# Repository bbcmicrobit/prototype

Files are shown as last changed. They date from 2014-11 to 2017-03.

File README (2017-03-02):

Prototype Microbit/Reference Implementation
===========================================

----------------------------------------------------------------------------
NOTE:

This is the original README file for the project as released to potential
project partners in 2014.  The project is no longer covered under NDA, and
none of the information in this repository is considered confidential
information.

At some point this will revert to a historical readme and the text of this
file replaced.  Pull requests welcome, and will be merged as and when
practical!

Updated: May 2016

Michael Sparks, Senior Research Engineer, BBC R&D

---------------------------------------------------------------------------

Copyright (C) 2014 BBC.

This reference implementation is confidential information, and MUST be kept
confidential, as per the NDA you have signed with the BBC.

The reference implementation is provided to assist you in your pitch/proposal/
development process. It is NOT intended as a basis for ongoing development.

You should use this as a reference for what you want to pitch, rather than as
a basis for development. While improvements to the reference implementation
are welcome, the proposition will be better served by those pitches that go
beyond the reference implementation. Please see the enclosed LICENSE for
further details.

Licenses of technologies used within the reference implementation can be
found in the LICENSES.pdf file

The reference implementation is a WORK IN PROGRESS. It covers most of the
functional specification, and was used to create the functional spec. 
However, in places the the reference implementation deviates from the
functional spec.  In such cases, the functional spec is canonical, and over
time the reference implementation will improve to match the spec.

    NO WARRANTY

    THE HARDWARE, HARDWARE DESIGNS AND SOFTWARE ("MICROBIT SYSTEM")   
    IS DISTRIBUTED IN THE HOPE THAT IT WILL BE USEFUL, BUT WITHOUT 
    ANY WARRANTY.  IT IS PROVIDED "AS IS" WITHOUT WARRANTY OF ANY
    KIND, EITHER EXPRESSED OR IMPLIED, INCLUDING, BUT NOT LIMITED      
    TO, THE IMPLIED WARRANTIES OF MERCHANTABILITY AND FITNESS FOR A
    PARTICULAR PURPOSE.  THE ENTIRE RISK AS TO THE QUALITY AND
    PERFORMANCE OF THE MICROBIT SYSTEM IS WITH YOU.  SHOULD THE
    MICROBIT SYSTEM PROVE DEFECTIVE, YOU ASSUME THE COST OF ALL
    NECESSARY SERVICING, REPAIR OR CORRECTION.

    IN NO EVENT UNLESS REQUIRED BY APPLICABLE LAW THE AUTHOR WILL BE
    LIABLE TO YOU FOR DAMAGES, INCLUDING ANY GENERAL, SPECIAL,
    INCIDENTAL OR CONSEQUENTIAL DAMAGES ARISING OUT OF THE USE OR
    INABILITY TO USE THE MICROBIT SYSTEM (INCLUDING BUT NOT LIMITED      
    TO LOSS OF DATA OR DATA BEING RENDERED INACCURATE OR LOSSES
    SUSTAINED BY YOU OR THIRD PARTIES OR A FAILURE OF THE MICROBIT 
    SYSTEM TO OPERATE WITH ANY OTHER SYSTEMS), EVEN IF THE AUTHOR
    HAS BEEN ADVISED OF THE POSSIBILITY OF SUCH DAMAGES.

Michael Sparks, Senior Research Engineer, BBC R&D, December 2014

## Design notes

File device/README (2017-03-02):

The device design & production data files will go in here, so that
all the tech materials relating to the production microbit are in one place.

The current device is described in ProductionData, and uses Design Spark PCB
as the editor tool.

Note: The gerber/etc files in here are as provided to the PCB-A
print/assembly house *that we used* and while maybe could be used as-is you
are required to check that they are suitable for your use before you do.

Files in this directory and all the directories below this one are covered by this license:

#
# Copyright 2016 British Broadcasting Corporation and Contributors(1)
#
# (1) Contributors are listed in the AUTHORS file (please extend AUTHORS,
#     not this header)
#
# Licensed under the Apache License, Version 2.0 (the "License"); you may
# not use this file except in compliance this license (or the alternative
# license below).
# You may obtain a copy of the License at
#
#     http://www.apache.org/licenses/LICENSE-2.0
#
# This file is also alternatively licensed under the terms of the Creative
# Commons Attribution License (cc-by) version 2.  You may obtain a copy of
# the license at:
#
#     https://creativecommons.org/licenses/by/2.0/uk/
#
# Unless required by applicable law or agreed to in writing, software
# distributed under the License is distributed on an "AS IS" BASIS,
# WITHOUT WARRANTIES OR CONDITIONS OF ANY KIND, either express or implied.
# See the License for the specific language governing permissions and
# limitations under the License.
#

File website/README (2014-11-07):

Massive reorganisation - to allow using the repo to store
ALL the material relating to the project.

This directory is the various necessary parts of the website

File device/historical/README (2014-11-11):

These are the iterations of the microbug device from first steps through to
now.

This only includes the iterations created using DesignSpark PCB

I've left the tmp files in for now so there's a complete copy of everything

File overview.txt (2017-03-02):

What is Microbit - prototype technical overview
===============================================

NOTE; This, and all materials related to the reference implementation are
CONFIDENTIAL INFORMATION, and must not be made public, as per NDA with BBC.

The project entails a simple programmable wearable device. The current
reference implementation is based on an Atmel ATMega 32u4 which makes it
similar to an leonardo arduino - indeed we using the command line suite of
tools configured as a leonardo. (The device doesn't have an Arduino
bootloader however)

The user uses a website (which is implemented using Django) to create
programs for the device using Blockly. Blockly generates javascript to drive
a simulator for verification of the behaviour. Blockly also generates python
- that is stored on a server.

The python is compiled to C++ - using a barebone python to C++ compiler I've
written using David Beazeley's ply.

The C++ is then injected into the arduino command line tools, compiled and a
.hex file image extracted from the build

That .hex file can be downloaded by users
They then have a local application - a loader - (PyQT & shell out to a
command line tool) for loading the code onto the device.
The device then runs the code.

There's also an IOT library (http://github.com/sparkslabs/iotoy) which is
available to allow the device to be controlled and used as a sensor by a
host machine. The primary client side library for that is written in python.

Buried in that toolchain is a cut down python to C++ compiler intended for
targetting microcontrollers. (I did look at all the others I'm aware of, but
they weren't really suitable). 

There's also the aspect that actually while blockly is used as *a* editor,
the system's primary target is python.

While technologies are used in this reference implementation, please
rememeber it is illustrative, not prescriptive. The functional specification
is the canonical description of prescriptive functionality.

There are many some parts of this are not as fleshed out as they could be -
in particular the python/C++ code is nowhere near as far along as we'd like.
It works, but within more constrained limits than it should. 

Michael Sparks, Senior Research Engineer, BBC R&D, December 2014

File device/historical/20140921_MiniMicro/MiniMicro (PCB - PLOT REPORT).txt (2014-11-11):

PLOT REPORT
-----------

Report File    : C:\Users\michaels\Documents\MiniMicro\MiniMicro (PCB - PLOT REPORT).txt
Report Written : Sunday, September 21, 2014
Design Path    : C:\Users\michaels\Documents\MiniMicro\MiniMicro.pcb
Design Title   : 
Created        : 19/09/2014 13:37:57
Last Saved     : 21/09/2014 04:09:29
Editing Time   : 1987 min
Units          : thou (precision 1)

Device Settings
===============

Gerber Settings
===============

    Leading zero suppression.
    G01 assumed throughout.
    Line termination <*> <CR> <LF>.
    2.3 format absolute inches.

    Format commands defined in Gerber file.
    Aperture table defined in Gerber file.
    Hardware arcs allowed.

Drill Settings
==============

    Excellon Format 1    Format 2.3 absolute in mm.
    No zero suppression.

PDF Settings
============

Combine Plots Yes

Use Bookmarks Yes

Component Details Yes

Symbol Details Yes

Link Net Names Yes

View PDF Yes

All Colours Black Yes

Plots Output
============

    Plot Job: "C:\Users\michaels\Documents\MiniMicro\MiniMicro.mop"

PDF Output
==========

    Layer
    --------------
    Bottom Copper
    Top Copper
    Top Silkscreen

Gerber Output
=============

C:\Users\michaels\Documents\MiniMicro\MiniMicro - Top Copper (Resist).gbr

    Layers:
    ------------
    Top Copper

    D-Code  Shape  (thou)
    --------------------------------------------
    D14     Rectangle 24.00 X 56.00  Rotation 90
    D15     Rectangle 24.00 X 56.00
    D25     Rectangle 27.52 X 47.40
    D26     Rectangle 46.00 X 67.00
    D27     Square 69.00
    D28     Round 69.00
    D29     Rectangle 28.00 X 65.00
    D72     Rectangle 65.00 X 73.00
    D73     Rectangle 63.00 X 67.00  Rotation 90
    D83     Rectangle 27.52 X 47.40  Rotation 90
    D84     Rectangle 36.00 X 65.00  Rotation 90
    D85     Rectangle 65.00 X 69.00
    D86     Rectangle 65.00 X 69.00  Rotation 90
    D87     Rectangle 40.00 X 65.00
    D88     Square 57.00
    D89     Round 57.00
    D90     Round 72.99
    D91     Round 88.74
    D92     Round 128.11

Gerber Output
=============

C:\Users\michaels\Documents\MiniMicro\MiniMicro - Top Copper (Paste).gbr

    Layers:
    ------------
    Top Copper

    D-Code  Shape  (thou)
    --------------------------------------------
    D17     Rectangle 10.00 X 42.00  Rotation 90
    D18     Rectangle 10.00 X 42.00
    D77     Rectangle 13.52 X 33.40
    D78     Rectangle 32.00 X 53.00
    D79     Rectangle 14.00 X 51.00
    D80     Rectangle 51.00 X 59.00
    D81     Rectangle 49.00 X 53.00  Rotation 90
    D93     Rectangle 13.52 X 33.40  Rotation 90
    D94     Rectangle 22.00 X 51.00  Rotation 90
    D95     Rectangle 51.00 X 55.00
    D96     Rectangle 51.00 X 55.00  Rotation 90
    D97     Rectangle 26.00 X 51.00

Gerber Output
=============

C:\Users\michaels\Documents\MiniMicro\MiniMicro - Bottom Copper (Resist).gbr

    Layers:
    ---------------
    Bottom Copper

    D-Code  Shape  (thou)
    ---------------------------------
    D20     Round 70.00
    D27     Square 69.00
    D28     Round 69.00
    D88     Square 57.00
    D89     Round 57.00
    D90     Round 72.99
    D91     Round 88.74
    D92     Round 128.11
    D98     Rectangle 246.22 X 246.22

Gerber Output
=============

C:\Users\michaels\Documents\MiniMicro\MiniMicro - Bottom Copper (Paste).gbr

    Layers:
    ---------------
    Bottom Copper

    D-Code  Shape  (thou)
    ---------------------------------
    D99     Round 56.00
    D100    Rectangle 232.22 X 232.22

NC Drill Output
===============

C:\Users\michaels\Documents\MiniMicro\MiniMicro - Drill Data - Through Hole.drl

    Output:
    --------------------------
    Plated Round Drill Holes
    Plated Slots
    Plated Board Outlines

    Tool   Size       Count    ID
    -----------------------------
    T001   00.024 in  37     B
    T002   00.027 in  2      F
    T003   00.031 in  3      G
    T004   00.032 in  13     C
    T005   00.039 in  12     E
    T006   00.057 in  1      H
    T007   00.059 in  1      I
    T008   00.071 in  2      J
    -----------------------------
    Total             71
    -----------------------------
    Tool   Size       Count    ID
    -----------------------------
    T001   00.025 in  1
    -----------------------------
    Total             1
    -----------------------------

Gerber Output
=============

C:\Users\michaels\Documents\MiniMicro\MiniMicro - Drill Ident Drawing - Through Hole.gbr

    Layers:
    ----------------
    [Through Hole]

Drill Ident Drawing
===================

    Drill  Plated  Size  Shape  ID
    ------------------------------
    24     Y       100   Round  B
    32     Y       100   Round  C
    39     Y       100   Round  E
    27     Y       100   Round  F
    31     Y       100   Round  G
    57     Y       100   Round  H
    59     Y       100   Round  I
    71     Y       100   Round  J

    D-Code  Shape  (thou)
    ---------------------
    D19     Round 100.00
    D70     Round 5.00

End Of Report.

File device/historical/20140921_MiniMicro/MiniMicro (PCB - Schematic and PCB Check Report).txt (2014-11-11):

Schematic and PCB Check Report
------------------------------

Report File    : C:\Users\michaels\Documents\MiniMicro\MiniMicro (PCB - Schematic and PCB Check Report).txt
Report Written : Sunday, September 21, 2014
Design Path    : C:\Users\michaels\Documents\MiniMicro\MiniMicro.pcb
Design Title   : 
Created        : 19/09/2014 13:37:57
Last Saved     : 21/09/2014 03:45:59
Editing Time   : 1963 min
Units          : thou (precision 1)

Checking integrity of Schematic "C:\Users\michaels\Documents\MiniMicro\MiniMicro_Sheet1.sch" with PCB "C:\Users\michaels\Documents\MiniMicro\MiniMicro.pcb"
===========================================================================================================================================================

The designs are the same.

End Of Report.

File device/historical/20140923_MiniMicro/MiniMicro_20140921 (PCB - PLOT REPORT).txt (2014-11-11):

PLOT REPORT
-----------

Report File    : C:\Users\michaels\Documents\MiniMicro_20140921\MiniMicro_20140921 (PCB - PLOT REPORT).txt
Report Written : Monday, September 22, 2014
Project Path   : C:\Users\michaels\Documents\MiniMicro_20140921\MiniMicro_20140921.prj
Design Path    : C:\Users\michaels\Documents\MiniMicro_20140921\MiniMicro_20140921.pcb
Design Title   : 
Created        : 21/09/2014 12:47:43
Last Saved     : 22/09/2014 12:27:17
Editing Time   : 626 min
Units          : thou (precision 0)

Device Settings
===============

Gerber Settings
===============

    Leading zero suppression.
    G01 assumed throughout.
    Line termination <*> <CR> <LF>.
    2.3 format absolute inches.

    Format commands defined in Gerber file.
    Aperture table defined in Gerber file.
    Hardware arcs allowed.

Drill Settings
==============

    Excellon Format 1    Format 2.3 absolute in mm.
    No zero suppression.

Plots Output
============

    Plot Job: "C:\Users\michaels\Documents\MiniMicro_20140921\MiniMicro_20140921.mop"

Gerber Output
=============

C:\Users\michaels\Documents\MiniMicro_20140921\MiniMicro_20140921 - Top Silkscreen.gbr

    Layers:
    ----------------
    Top Silkscreen
    Board Outlines

    D-Code  Shape  (thou)
    ---------------------
    D70     Round 5.00
    D116    Round 1.00
    D117    Round 6.00
    D118    Round 3.00

Gerber Output
=============

C:\Users\michaels\Documents\MiniMicro_20140921\MiniMicro_20140921 - Top Copper.gbr

    Layers:
    ------------
    Top Copper

    D-Code  Shape  (thou)
    ---------------------------------------------
    D13     Round 15.00
    D71     Round 48.00
    D119    Rectangle 14.00 X 46.00  Rotation 45
    D120    Rectangle 14.00 X 46.00  Rotation 135
    D121    Rectangle 17.52 X 37.40
    D122    Rectangle 36.00 X 57.00  Rotation 45
    D123    Square 59.00
    D124    Round 59.00
    D125    Rectangle 18.00 X 55.00
    D126    Rectangle 55.00 X 63.00
    D127    Rectangle 53.00 X 57.00  Rotation 90
    D128    Rectangle 36.00 X 57.00
    D129    Rectangle 26.00 X 55.00  Rotation 135
    D130    Rectangle 55.00 X 59.00
    D131    Rectangle 30.00 X 55.00
    D132    Round 62.99
    D133    Round 78.74
    D134    Square 47.00
    D135    Round 47.00
    D136    Round 236.22
    D137    Round 10.00
    D138    Round 56.00
    D139    Round 25.00

Gerber Output
=============

C:\Users\michaels\Documents\MiniMicro_20140921\MiniMicro_20140921 - Top Copper (Resist).gbr

    Layers:
    ------------
    Top Copper

    D-Code  Shape  (thou)
    ---------------------------------------------
    D21     Rectangle 24.00 X 56.00  Rotation 135
    D22     Rectangle 24.00 X 56.00  Rotation 45
    D25     Rectangle 27.52 X 47.40
    D26     Rectangle 46.00 X 67.00
    D27     Square 69.00
    D28     Round 69.00
    D29     Rectangle 28.00 X 65.00
    D73     Rectangle 63.00 X 67.00  Rotation 90
    D87     Rectangle 40.00 X 65.00
    D88     Square 57.00
    D89     Round 57.00
    D90     Round 72.99
    D91     Round 88.74
    D101    Rectangle 46.00 X 67.00  Rotation 45
    D102    Rectangle 65.00 X 73.00
    D104    Rectangle 65.00 X 69.00
    D107    Rectangle 36.00 X 65.00  Rotation 135
    D109    Round 246.22

Gerber Output
=============

C:\Users\michaels\Documents\MiniMicro_20140921\MiniMicro_20140921 - Top Copper (Paste).gbr

    Layers:
    ------------
    Top Copper

    D-Code  Shape  (thou)
    ---------------------------------------------
    D75     Rectangle 10.00 X 42.00  Rotation 135
    D76     Rectangle 10.00 X 42.00  Rotation 45
    D77     Rectangle 13.52 X 33.40
    D78     Rectangle 32.00 X 53.00
    D79     Rectangle 14.00 X 51.00
    D80     Rectangle 51.00 X 59.00
    D81     Rectangle 49.00 X 53.00  Rotation 90
    D95     Rectangle 51.00 X 55.00
    D97     Rectangle 26.00 X 51.00
    D105    Rectangle 32.00 X 53.00  Rotation 45
    D108    Rectangle 22.00 X 51.00  Rotation 135

Gerber Output
=============

C:\Users\michaels\Documents\MiniMicro_20140921\MiniMicro_20140921 - Bottom Copper.gbr

    Layers:
    ---------------
    Bottom Copper

    D-Code  Shape  (thou)
    ----------------------------------------------
    D13     Round 15.00
    D71     Round 48.00
    D123    Square 59.00
    D124    Round 59.00
    D132    Round 62.99
    D133    Round 78.74
    D134    Square 47.00
    D135    Round 47.00
    D136    Round 236.22
    D138    Round 56.00
    D140    Rectangle 400.00 X 400.00  Rotation 90
    D141    Rectangle 200.00 X 200.00  Rotation 90
    D142    Rectangle 196.85 X 196.85  Rotation 90
    D143    Round 50.00

Gerber Output
=============

C:\Users\michaels\Documents\MiniMicro_20140921\MiniMicro_20140921 - Bottom Copper (Resist).gbr

    Layers:
    ---------------
    Bottom Copper

    D-Code  Shape  (thou)
    ----------------------------------------------
    D27     Square 69.00
    D28     Round 69.00
    D88     Square 57.00
    D89     Round 57.00
    D90     Round 72.99
    D91     Round 88.74
    D109    Round 246.22
    D110    Rectangle 410.00 X 410.00  Rotation 90
    D111    Rectangle 210.00 X 210.00  Rotation 90
    D112    Rectangle 206.85 X 206.85  Rotation 90

Gerber Output
=============

C:\Users\michaels\Documents\MiniMicro_20140921\MiniMicro_20140921 - Bottom Copper (Paste).gbr

    Layers:
    ---------------
    Bottom Copper

    D-Code  Shape  (thou)
    ----------------------------------------------
    D113    Rectangle 396.00 X 396.00  Rotation 90
    D114    Rectangle 196.00 X 196.00  Rotation 90
    D115    Rectangle 192.85 X 192.85  Rotation 90

NC Drill Output
===============

C:\Users\michaels\Documents\MiniMicro_20140921\MiniMicro_20140921 - Drill Data - Through Hole.drl

    Output:
    --------------------------
    Plated Round Drill Holes
    Plated Slots
    Plated Board Outlines

    Tool   Size       Count    ID
    -----------------------------
    T001   00.024 in  50     B
    T002   00.027 in  2      F
    T003   00.031 in  3      G
    T004   00.032 in  9      C
    T005   00.039 in  12     E
    T006   00.057 in  1      H
    T007   00.059 in  1      I
    T008   00.157 in  8      K
    -----------------------------
    Total             86
    -----------------------------
    Tool   Size       Count    ID
    -----------------------------
    T001   00.025 in  1
    -----------------------------
    Total             1
    -----------------------------

Gerber Output
=============

C:\Users\michaels\Documents\MiniMicro_20140921\MiniMicro_20140921 - Drill Ident Drawing - Through Hole.gbr

    Layers:
    ----------------
    [Through Hole]

Drill Ident Drawing
===================

    Drill  Plated  Size  Shape  ID
    ------------------------------
    24     Y       100   Round  B
    32     Y       100   Round  C
    39     Y       100   Round  E
    27     Y       100   Round  F
    31     Y       100   Round  G
    57     Y       100   Round  H
    59     Y       100   Round  I
    157    Y       100   Round  K

    D-Code  Shape  (thou)
    ---------------------
    D19     Round 100.00
    D70     Round 5.00

End Of Report.

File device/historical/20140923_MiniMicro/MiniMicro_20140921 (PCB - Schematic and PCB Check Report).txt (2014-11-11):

Schematic and PCB Check Report
------------------------------

Report File    : C:\Users\michaels\Documents\MiniMicro_20140921\MiniMicro_20140921 (PCB - Schematic and PCB Check Report).txt
Report Written : Tuesday, September 23, 2014
Project Path   : C:\Users\michaels\Documents\MiniMicro_20140921\MiniMicro_20140921.prj
Design Path    : C:\Users\michaels\Documents\MiniMicro_20140921\MiniMicro_20140921.pcb
Design Title   : 
Created        : 21/09/2014 12:47:43
Last Saved     : 23/09/2014 15:33:50
Editing Time   : 719 min
Units          : thou (precision 0)

Checking integrity of Schematic and Pcb designs in project "MiniMicro_20140921"
===============================================================================

The designs are the same.

End Of Report.

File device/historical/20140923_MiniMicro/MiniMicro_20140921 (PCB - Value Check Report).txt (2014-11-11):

Value Check Report
------------------

Report File    : C:\Users\michaels\Documents\MiniMicro_20140921\MiniMicro_20140921 (PCB - Value Check Report).txt
Report Written : Monday, September 22, 2014
Project Path   : C:\Users\michaels\Documents\MiniMicro_20140921\MiniMicro_20140921.prj
Design Path    : C:\Users\michaels\Documents\MiniMicro_20140921\MiniMicro_20140921.pcb
Design Title   : 
Created        : 21/09/2014 12:47:43
Last Saved     : 22/09/2014 12:14:15
Editing Time   : 613 min
Units          : thou (precision 0)

Errors Found
============

Capacitor C1 value not found
Capacitor C2 value not found
Capacitor C4 value not found
Inductor L1 value not found
Inductor L2 value not found
Inductor L3 value not found
Inductor L4 value not found
Inductor L5 value not found
Inductor L6 value not found
Inductor L7 value not found
Inductor L8 value not found
Inductor L9 value not found
Inductor L10 value not found
Inductor L11 value not found
Inductor L12 value not found
Inductor L13 value not found
Inductor L14 value not found
Inductor L15 value not found
Inductor L16 value not found
Inductor L17 value not found
Inductor L18 value not found
Inductor L19 value not found
Inductor L20 value not found
Inductor L21 value not found
Inductor L22 value not found
Inductor L23 value not found
Inductor L24 value not found
Inductor L25 value not found
Resistor R1 value not found
Resistor R2 value not found
Resistor R10 value not found
Resistor R11 value not found
Resistor R13 value not found
Resistor R14 value not found
Resistor R15 value not found

End Of Report.

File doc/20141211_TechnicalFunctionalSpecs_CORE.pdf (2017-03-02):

# BBC Learning Make It Digital

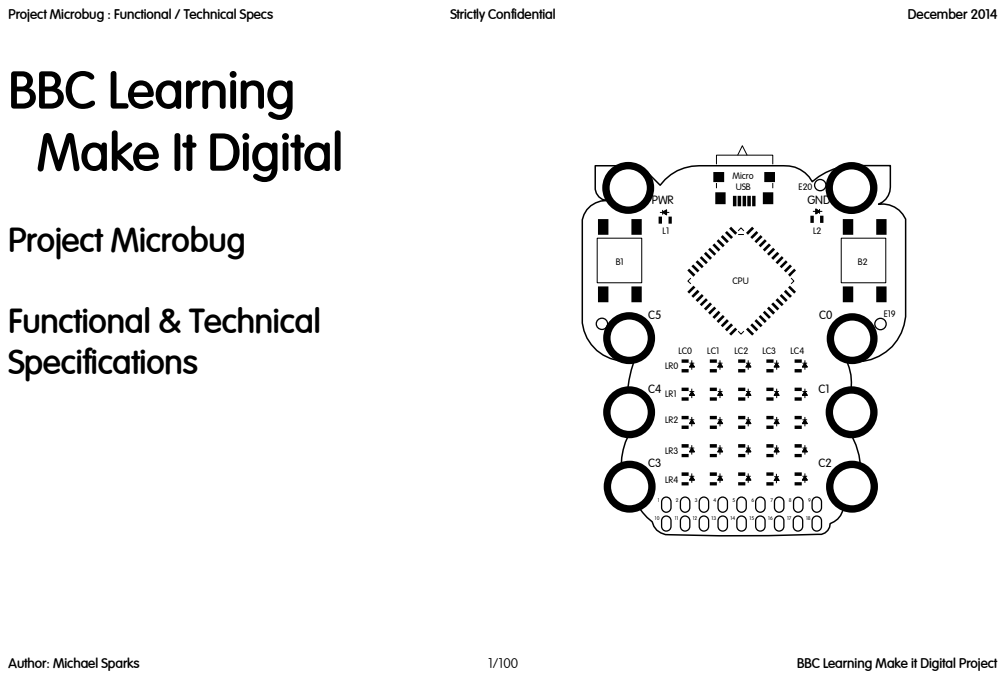
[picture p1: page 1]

Project Microbug : Functional / Technical Specs | Strictly Confidential | December 2014

## Contents

Author: Michael Sparks | 2/100 | BBC Learning Make it Digital Project

Project Microbug : Functional / Technical Specs | Strictly Confidential | December 2014

2.9 Front End Types | 40 2.10 Website Core | 41 2.10.1 Browsing | 41 2.10.2 Editing | 42 2.10.3 Simulator | 42 2.10.4 Tutorial Resources | 42 2.10.5 Code Generation from a visual editor | 43 2.11 Website Services | 43 2.11.1 Identity Services | 44 2.11.2 Compiler Service | 44 2.11.3 Python interface | 44
2.11.3.a Language Features to be supported | 44
2.11.3.b Language Features not supported | 45

2.11.4 C++ Interface | 46 2.11.5 Storage Services | 46 2.12 API | 47 2.13 Tethered Mode | 47 2.13.1 Tethered mode – Serial Protocol | 48 2.13.2 Tethered mode – Manual usage | 50 2.13.3 Tethered Mode - local API usage | 50 2.13.4 Tethered Mode - local API advertising | 50 2.13.5 Tethered Mode - remote API access | 50

### 3 Fixed & Flexible Points | 51

### 3.1 Rationale | 51 3.2 Device | 52 3.2.1 Device interface - Device abstraction layer | 52 3.2.2 uhex file specification (Universal .hex file format) | 53

3.2.3 Boot Loader | 53 3.2.4 Loader | 54 3.3 Website Overview | 54 3.3.1 Browsing | 55 3.3.2 Editing | 55 3.3.3 Simulator | 56 3.3.4 Tutorials | 56 3.3.5 Identity | 57 3.3.6 Code Generation from a visual editor | 57 3.4 Website Services | 58 3.4.1 Identity Services | 58 3.4.2 Compiler Service | 59 3.4.3 Python interface | 59 3.4.4 C++ Interface | 60 3.4.5 Other language interfaces | 60 3.4.6 Language interfaces | 61 3.4.7 Upload/Download service | 61 3.5 API | 62 3.6 Tethered Mode | 62
3.6.1 - Device specification | 63
3.6.2 - Local usage | 63
3.6.3 - local API usage | 64
3.6.4 - local API advertising | 65
3.6.5 - remote API access | 65

### 4 Appendix Reference Implementation | 66

### 4.1 Reference Implementation Hardware Description | 66 4.1.1 Electronics | 66 4.1.2 Device Physical Connections | 67

Author: Michael Sparks | 3/100 | BBC Learning Make it Digital Project

Project Microbug : Functional / Technical Specs | Strictly Confidential | December 2014
4.1.2.a Physical Connections: LED Matrix | 68
4.1.2.b Physical Connections: Buttons, Eyes, Croc Clips | 69
4.1.2.c Physical Connections: Headers | 70
4.1.2.d Physical Connections: Expert/Emergency IO Pins | 71

### 4.2 Font | 72 4.2.1 DAL Reference font | 72 4.3 Overview of Software Stack | 75 4.4 Software Stack Rationale | 75 4.4.1 Device interface - Device abstraction layer | 76

4.4.1.a Display management | 76
4.4.1.b Status LED | 77
4.4.1.c Buttons | 77
4.4.1.d Images | 77
4.4.1.e Displayable Strings | 77
4.4.1.f IO Pin Control | 77
4.4.1.g Font | 77
4.4.1.h Library Functions | 77
4.4.1.i Startup Modes | 77
4.4.1.j Compiled Program Hosting Infrastructure | 77

### 4.4.2 uhex file specification (Universal .hex file format) | 77 4.4.3 Boot Loader | 78 4.4.4 Loader | 78

4.4.4.a Windows | 79
4.4.4.b Mac OS X | 79
4.4.4.c Ubuntu | 79
4.4.4.d Rasp Pi | 79

### 4.5 Website Overview | 80 4.5.1 Browsing | 80

4.5.2 Editing | 81 4.5.3 Simulator | 81 4.5.4 Tutorials | 82 4.5.5 Identity | 82 4.5.6 Code Generation from a visual editor | 83 4.6 Website Services | 83 4.6.1 Identity Services | 84 4.6.2 Compiler Service | 84 4.6.3 Python interface | 84 4.6.4 C++ Interface | 87 4.6.5 Upload/Download service | 88 4.7 API | 88 4.8 Tethered Mode | 89 4.8.1 Device specification | 89 4.8.2 Local usage | 89 4.8.3 local API usage | 90 4.8.4 local API advertising | 90 4.8.5 remote API access | 91 4.9 Licenses | 91 4.9.1 License of Microbug Software Stack | 92 4.9.2 License of Microbug Hardware Stack | 92 4.9.3 Licence for the font Tiny | 92 4.9.4 License for parsing library ply | 93 4.9.5 License for Python & Python standard Library | 93 4.9.6 License of IOToy | 94 4.9.7 License of Blockly | 96 4.9.8 License of Design Spark PCB | 98 4.9.9 License of Arduino Libraries | 99
Author: Michael Sparks | 4/100 | BBC Learning Make it Digital Project

Project Microbug : Functional / Technical Specs | Strictly Confidential | December 2014

### 4.9.10 License of Arduino Bootloader on Device | 99 4.9.11 License of clientside Toolchain as used by Loader | 99 4.9.12 License of AVR Toolchain | 99 4.9.13 License of GCC-AVR Toolchain | 99 4.9.14 License of atmel_bootloader.h | 100 4.9.15 License of dfu-programmer | 100

Author: Michael Sparks | 5/100 | BBC Learning Make it Digital Project

Project Microbug : Functional / Technical Specs | Strictly Confidential | December 2014

# 1 Technical Specification

This document describes Project Microbug.

This is a working title for a BBC project targetted at assisting the nation's children with coding. This document using “Microbug” to describe the software and hardware platform as a matter of expedience. This is not the product name..

The intended audience of this document is primarily engineers who are interested in implementing, using or understanding one or more parts of the Microbug system.

This document consists of the following parts:

- A complete overview of what microbug is, and what it does
- A full functional specification of the system components. The functional specification is in no way prescriptive as to how the final system should be implemented.
- A full description of the complete reference implementation that has been created to sanity check the functional specification. The reference implementation is not intended to constrain the functional specification, but rather illustrate the concepts in the system.
- It is hope that potential partners will look at the reference implementation and be willing and able to offer better alternatives of various subsystems. This is actively welcomed. In order to assist with this chapter 3 discusses the impact of changing various parts of the system.

Aspects such as branding, form factor editorial direction and tone are out of scope for this document.

## 1.1 What is Microbug ?

Microbug is a platform supporting children who code, those who want to code, and those who need to code. The Microbug itself is a small, programmable, wearable device. It has an LED matrix capable of scrolling messages or simple graphics. It deliberately exposes the electronics of the device and can be powered by a coin cell battery

It has a number of crocodile clip connectors for attaching power and sensors. It also makes available a large number of IO pins for the owner to build more capable devices.

It can be programmed via a simple graphical web application and client side loader. It makes the underlying code visible to the user, and it compiles user programs online.

Furthermore, it can be used in a “tethered” mode allowing it to be controlled and act as a controller Tethered mode also enables users to explore Internet of Things related concepts and scenarios.

## 1.1.1 Aspirational

Microbug aspires to be simple to code for with a very low barrier to entry when getting started.. However it also aims to be a sufficiently capable platform such that it can grow with the user's experience. It does not aim to do everything, but does aim to enable users to take that first step in an engaging way to encourage them to take that second and third step too.

Key design constraints:

- Programmable – The device must be reprogrammable
- Simple to program – via a graphical browser based UI
- Small – maximum 5cm x5cm
- Cheap – manufacture cost must be approximately £2 or less when produced
Author: Michael Sparks | 6/100 | BBC Learning Make it Digital Project

Project Microbug : Functional / Technical Specs | Strictly Confidential | December 2014

in large scale – for example in batches of 100,000 units.

## 1.1.2 Technical

Technically, the device has the following high level characteristics:

- A small device with a microcontroller
- A 5x5 LED matrix
- 2 buttons
- 2 extra status LEDs
- 2032 coin cell battery power
- 2 crocodile clip connectors for external power (for example as a necklace)
- 6 analogue I/O crocodile clip connectors
- Access to a large number of digital IO pins, for attaching and controlling a wide variety of standard devices
- A reference implementation

The website has the following characteristics:

- Web based editng of programs graphically and textually.
- The ability to browse programs created by others
- Tutorials
- The ability for users and their mentors to have a user identity, and for mentors to be able to assist users on the system. Example mentors may be teachers, parents, youth group leaders, etc. The reference identity system utilises the fact that a device is distributed to users to enhance the user experience.
- It provides compilation services for taking web based programs and compiling them into a form suitable for running on the microcontroller. The primary service has at its heart a restricted-python to C++ compiler. There is a secondary C++ service.
- The python/C++ code targets a device abstraction layer rather than any given microcontroller's API.
- The website is specified such that there can be multiple editors, different identity systems, different tutorials, different storage systems and even potentially different hardware.
- The services the website uses are exposed as JSON oriented APIs
- There is also a reference implementation of the website

Client side, there is a need to get output of the compilation service onto the client. For reasons that will be detailed later this requires the use of a “loader” application. The features of a loader application:

- It will take a uHex file and flash the device with the code for the device.
- It can take additional data stored in the uHex file and use that to program the EEPROM data on the device.
- This client side application works on Windows, Mac OS X, Linux (including Raspberry Pi)
Author: Michael Sparks | 7/100 | BBC Learning Make it Digital Project

Project Microbug : Functional / Technical Specs | Strictly Confidential | December 2014

## 1.2 What pieces make Microbug up

## 1.2.1 Systemic elements

The functional elements of the Microbug platform are as follows:

- The device itself, and the bootloader on the device
- The client side loader application
- A browser
- The “static” elements of the system – eg editor website, tutorials.
- Web services – (eg compiler)
- Identity
- Tethered Operation (to extend utility of the device)

The reference implementation implements a version of many possible systems matching this description. We invite partners to bring their expertise, technology and services to the table to produce the eventual proposition. This means that the there could be changes to any part of the system, while the core editorial proposition remains the same.

For example the reference implementation includes an editor. There are many possible editors, and the specification allows for many different editors. Another partner may prefer a different chip at the core of the device. We invite partners to propose working with us in their area of expertise.

We are open to changes to the implementation. Implementation changes in one part of the system affect others. This document details these effects in section 3

## 1.2.2 Specific elements

The specific elements of the system break down as follows:

- Device
- Core hardware elements
- Simple & advanced expansion capabilities
- 3 modes: Bootloader mode, run mode, tethered mode
- Client side loader
- Bootloader functionality
- Tethered mode functionality
- Browser
- the users browser. A recent HTML5 based browser is generally assumed, but the system should work with old browsers
- Static elements of the website
- Core web pages, templating, CMS
- Program editor
- Tutorials
- Program browsing
- Web services
- Program storage:
- Immutable version storage, mutable programs relate to immutable
Author: Michael Sparks | 8/100 | BBC Learning Make it Digital Project

Project Microbug : Functional / Technical Specs | Strictly Confidential | December 2014

version(s).

- upload
- download
- browse
- Compiler services:
- Pro-active compilation
- Python to .hex compilation
- C++ to .hex compilation
- Others, subject to agreement
- API Services
- Web services can all be used (and implemented) as JSON oriented APIs.
- Identity
- Baked in concepts of identity:
- Anonymous users – create programs
- Basic users – create/own programs
- Facilitator users – assist basic users (and above)
- Independent edit permissions
- Integration with thirst
- Tethered Operation
- Tethered mode is provided to extend the utility of the device, and allow the device to act as a controller, a sensor, and to explore IOT concepts.
- USB Serial based protocol to interact with the device - can be used without any library
- Supports device introspection & control through a command line style API
- Supports all aspects of the device
- Potential support for user functionality
- Python library provided to enable using the tethered device in a simple programmable fashion
- Python library provided also allows IOT functionality:
- Device can be automatically advertised onto the local network via mDNS
- REST oriented API is auto generated via introspection
- Clients can introspect the REST oriented API
- Python code to automatically introspect a device, and create a local API for the device is also include.
- The IOT library aims to provide an IP-like layer for devices to interact locally easily..
- Does NOT publish any data beyond local network and must be explicitly activated. Requires a host machine.
Author: Michael Sparks | 9/100 | BBC Learning Make it Digital Project

Project Microbug : Functional / Technical Specs | Strictly Confidential | December 2014

1.3 Walk through of basic usage.

This is a walk through of basic usage of the reference implementation to illustrate the
concepts used in Microbug.

NOTE: The reference implementation is in no way prescriptive. Use of a technology does NOT recommend that any particular technology or approach be used. Information relating to form factor, shape, colour, branding etc, are are provided separately. The implementation of software and electronics will be finalised in partnership.

This is the current reference implementation device:

The user goes to the website, clicks on “create”, and is taken to an editor, where they can create a program of their choice. In the reference implementation it looks like this when the user goes to create:

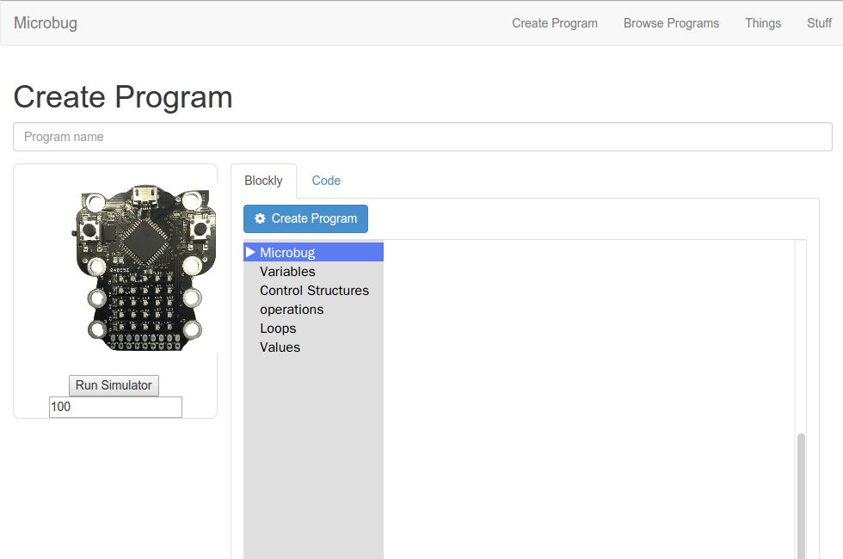
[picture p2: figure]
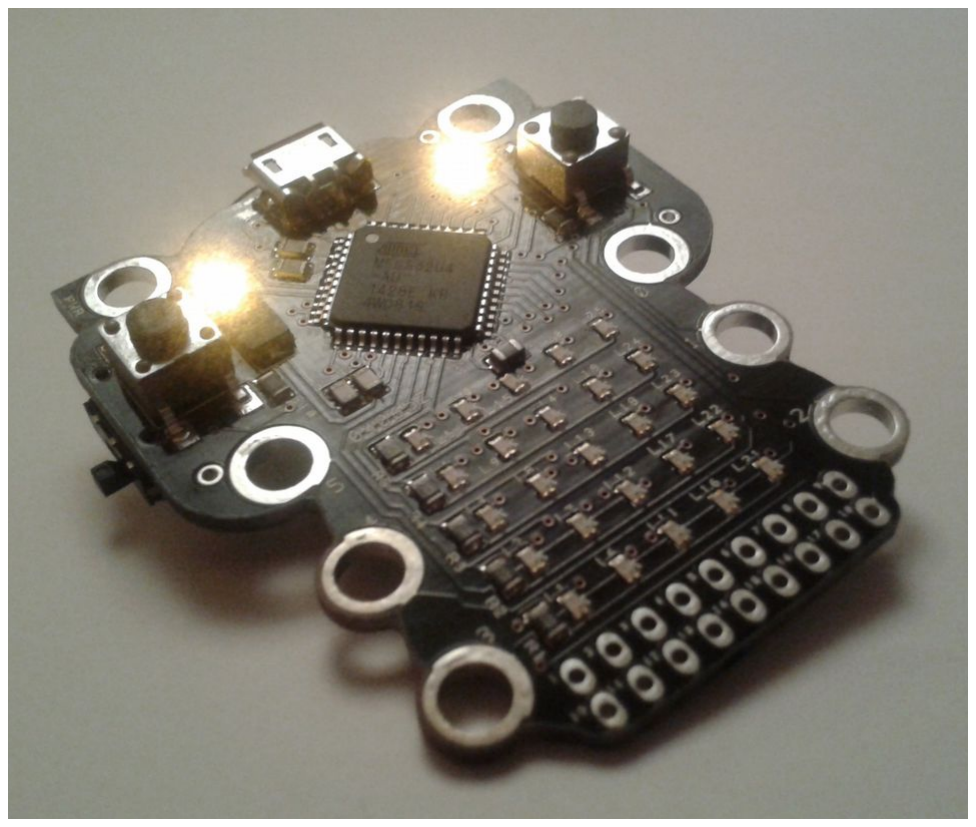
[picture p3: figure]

They can start editing their program:

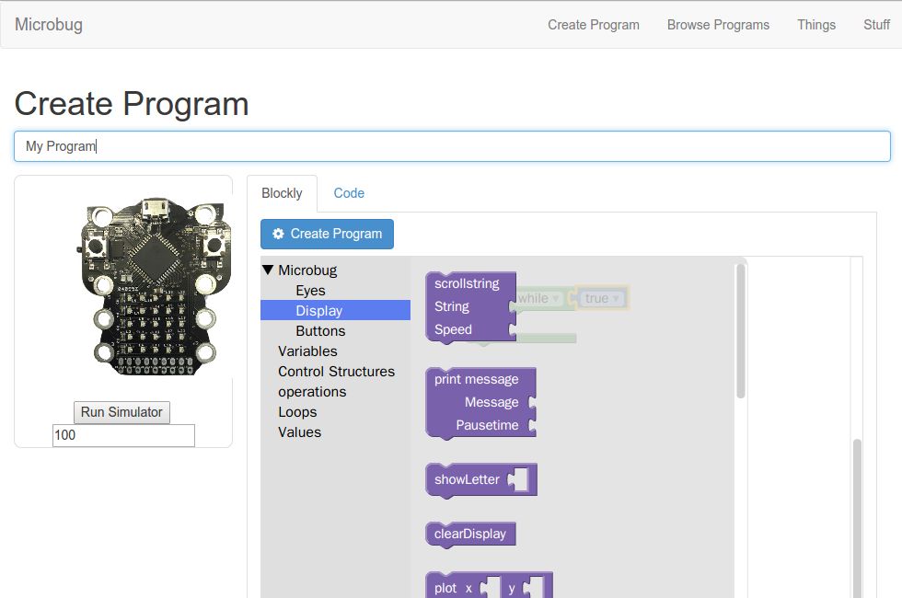
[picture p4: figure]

Author: Michael Sparks | 10/100 | BBC Learning Make it Digital Project

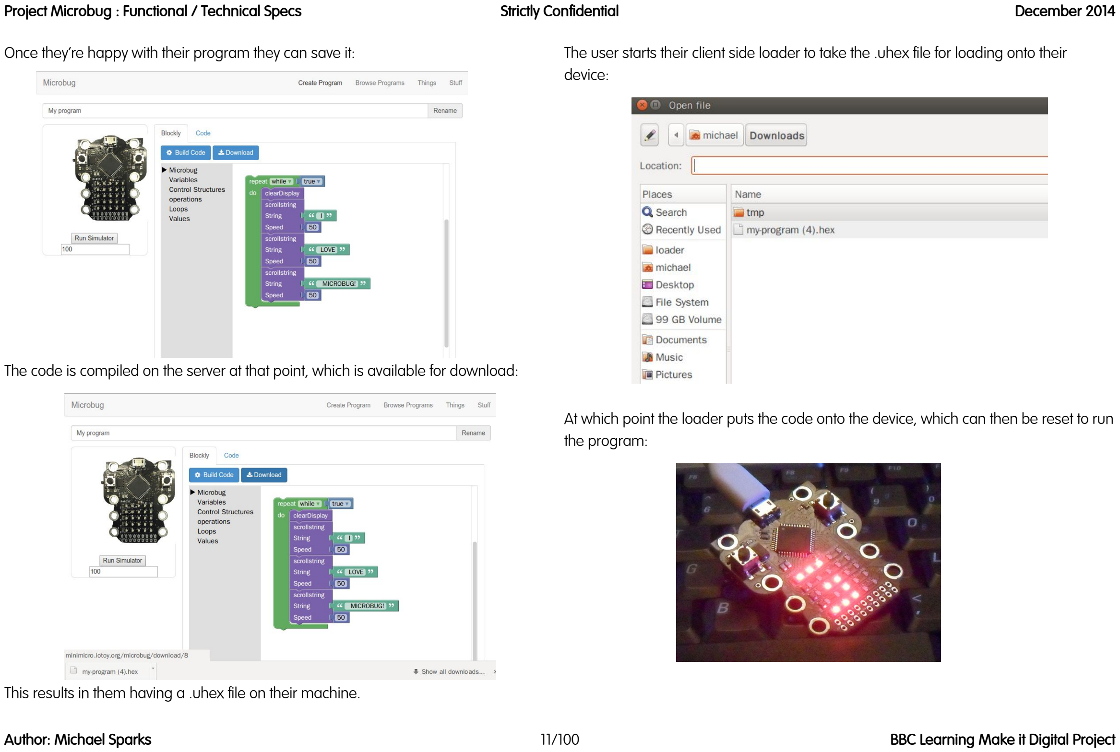
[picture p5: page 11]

Project Microbug : Functional / Technical Specs | Strictly Confidential | December 2014

Once they're happy with their program they can save it:

The code is compiled on the server at that point, which is available for download:

This results in them having a .uhex file on their machine.

The user starts their client side loader to take the .uhex file for loading onto their device:

At which point the loader puts the code onto the device, which can then be reset to run the program:

Author: Michael Sparks | 11/100 | BBC Learning Make it Digital Project

Project Microbug : Functional / Technical Specs | Strictly Confidential | December 2014

Additionally, there is a browse area of the website. If we had gone to the website
before they created their program, it would look like this:

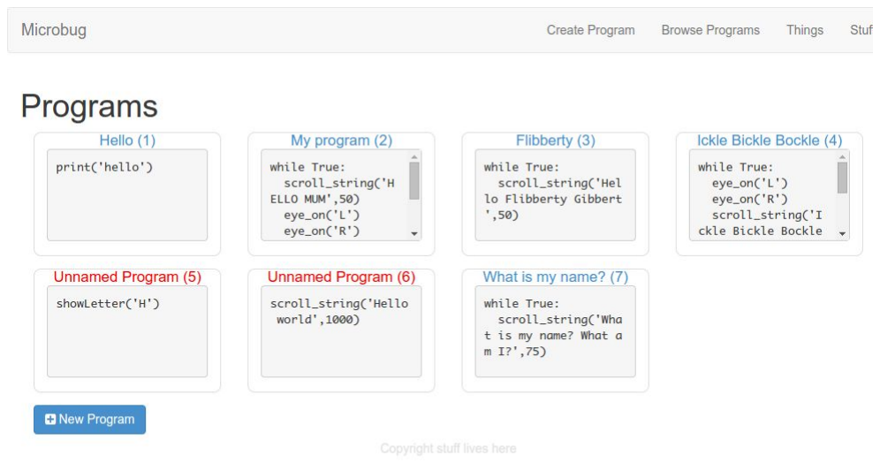
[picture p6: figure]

(The program names in red indicate the user didn't give that program a name - yet).

After the user creates the program we describe earlier, their program shows up here:

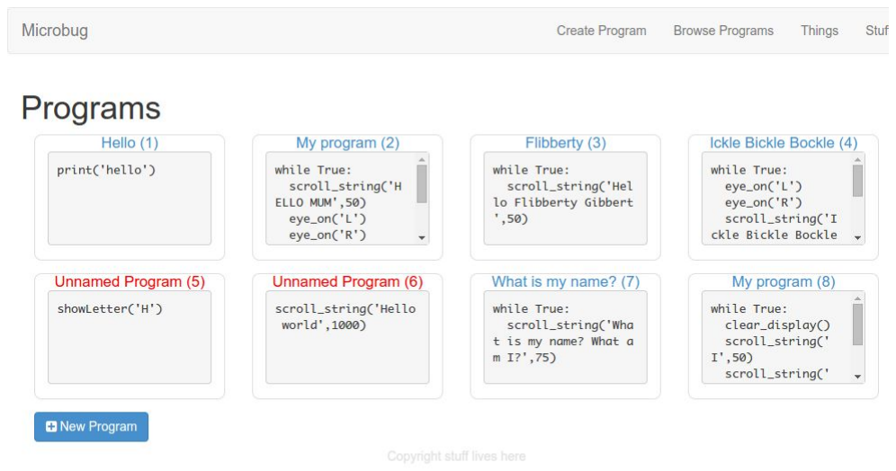
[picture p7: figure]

If a user clicks on any program in that display they are taken to an editor preloaded with that program. They can then create their own version, download it to their device or look at the python code behind the blocks.

The python code you see here:

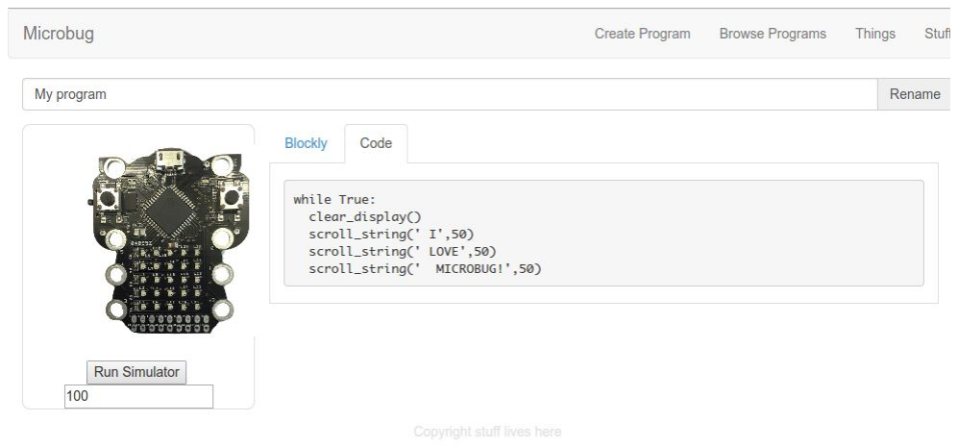
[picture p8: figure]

… is auto-generated from the blocks, and is the code that the website compiler service actually compiled into code the microbug device can run.

Finally, it is worth noting that every editor page has access to a simulator – this simulates the effect of running the code. It is not however an emulator in that it doesn't emulate the effects of running the .hex file on a device

Author: Michael Sparks | 12/100 | BBC Learning Make it Digital Project

Project Microbug : Functional / Technical Specs | Strictly Confidential | December 2014

## 1.4 Operational overview

The following operational overview assumes the following standard setup:

- A client device – such as a laptop, or desktop computer, running a common operating system
- A server consisting of standard relatively static web components
- Web services including storage, program compilation etc.

This split between subsystem functionality is illustrative, not prescriptive.

If the implementation was changed to entirely offline on a client device, all the server aspects and web services would either need to be running on the client, or running in an offline proxy mode.

If the implementation was changed to be app oriented – that is designed around running as an app on client devices such as iPads, Android devices, Windows Surfaces, and so on, then it is reasonable to expect parts of what is labelled on the following diagrams as static web or web services to run inside a client. Furthermore, the loader application on the diagram may also be integrated into the system.

## 1.4.1 Operational overview – standard usage

Earlier sections described the functional subunits of the system. Having walked through how they are used, this diagram shows the relationship between the

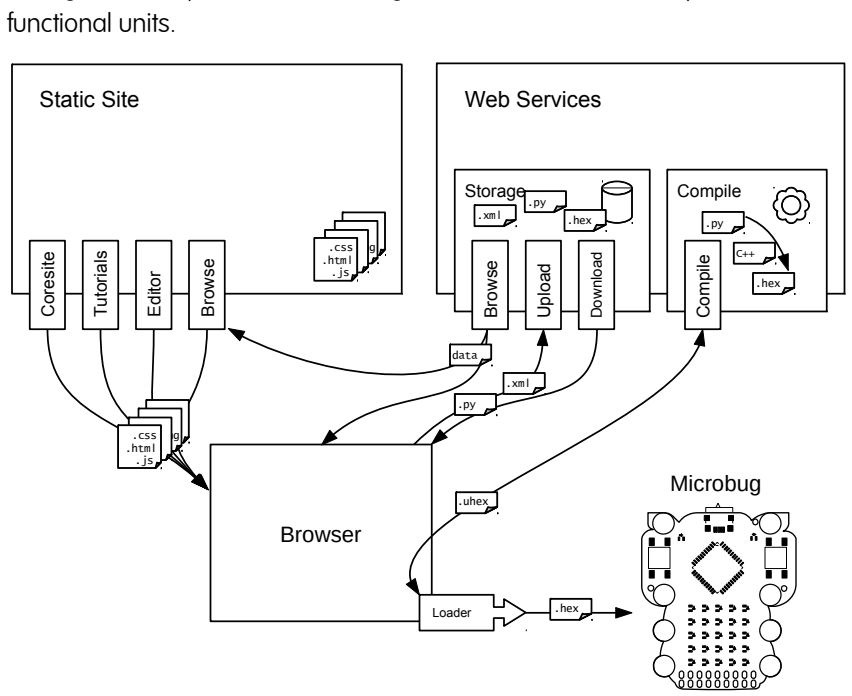
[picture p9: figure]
functional units.; Browser; Static Site; Web Services; Coresite; Tutorials; Editor; Browse; Upload; Download; Compile; Storage; Loader; data; .xml; .uhex; .hex; Microbug; .png .html .js; .css

Things this diagram does not show include: user identity and functional flow related to users. Please see the section on identity for this.

Author: Michael Sparks | 13/100 | BBC Learning Make it Digital Project

Project Microbug : Functional / Technical Specs | Strictly Confidential | December 2014

The following activity diagram shows the key interactions between functional units, as
illustrated by the walkthrough in the previous section:

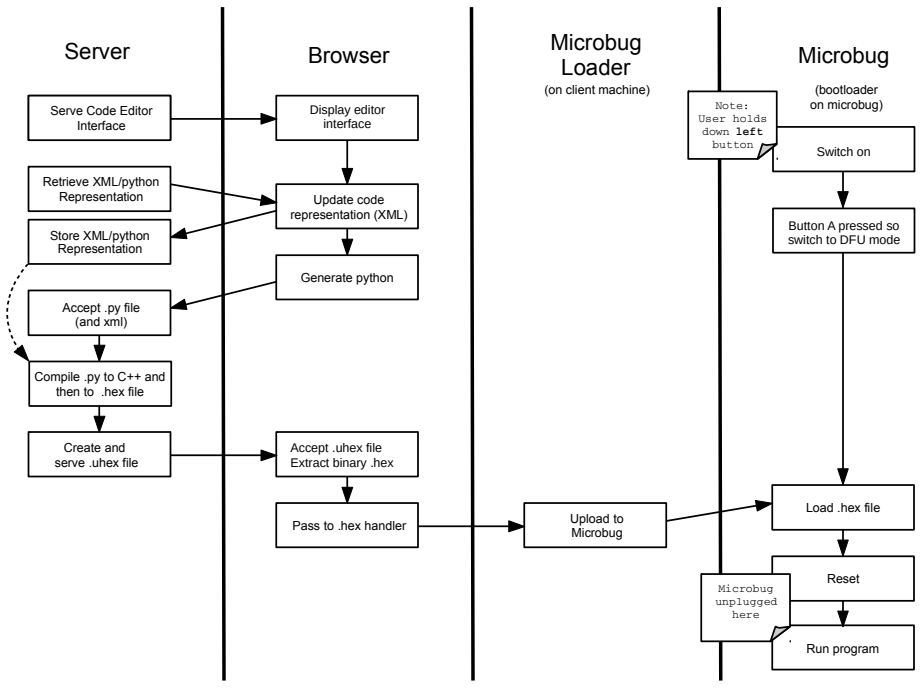
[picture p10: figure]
Microbug Loader; (on client machine); Upload to Microbug; (bootloader on microbug); Browser; Microbug; Update code representation (XML); Display editor interface; Generate python; Accept .uhex file Extract binary .hex; Pass to .hex handler; Server; Create and serve .uhex file; Serve Code Editor Interface; Accept .py file (and xml); Compile .py to C++ and then to .hex file; Load .hex file; Reset; Run program; Retrieve XML/python Representation; Store XML/python Representation; Microbug unplugged here; Switch on; Note: User holds down left button; Button A pressed so switch to DFU mode
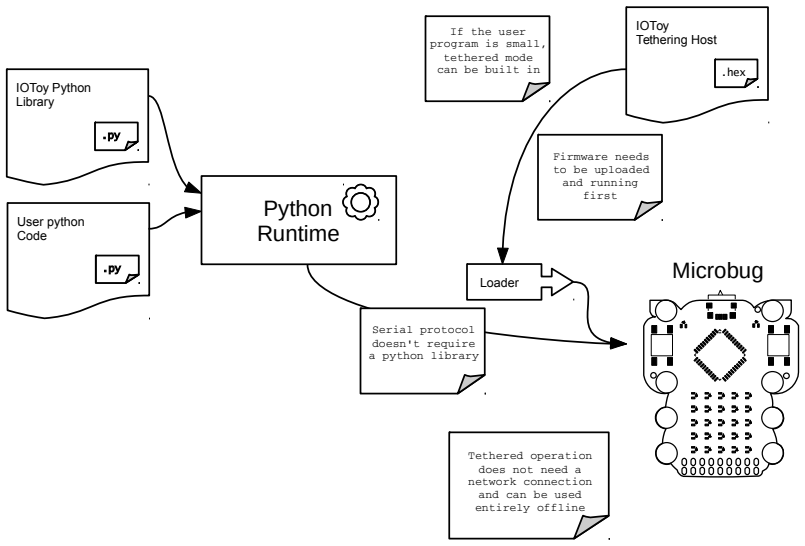
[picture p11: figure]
Python Runtime; Loader; IOToy Tethering Host; .hex; IOToy Python Library; User python Code; Firmware needs to be uploaded and running first; Tethered operation does not need a network connection and can be used entirely offline; Microbug; Serial protocol doesn't require a python library; If the user program is small, tethered mode can be built in

This diagram does not include aspects relating to user identity, but provides an overview of how the system as a whole interacts to enable the user to program their device.

## 1.4.2 Operational overview – tethered usage

Tethered usage is where the device is connected to a computer and can be controlled and queried by a program running on the host computer. This includes scrolling messages, turning LEDs on and off, button presses, reading/setting pin values etc.

The reference implementation of tethering uses BBC R&D's IOToy project's IOT stack. ¹

The protocol it implements specified here as the protocol for tethering and network tethering. This protocol has been used on even very small microcontrollers

The following diagram summarises the context for the simplest interaction with tethered mode, using sample python bindings:

1 http://github.com/bbcrd/iotoy

Author: Michael Sparks | 14/100 | BBC Learning Make it Digital Project

Project Microbug : Functional / Technical Specs | Strictly Confidential | December 2014

Key points: Firmware for enabling tethering has to be on the device. That firmware
provides a serial, line oriented protocol for interacting, controlling and introspecting the
device. An example python binding exists to wrap that up for the user.

The following activity diagram describes the primary interactions with a device that only has the tethering code loaded:

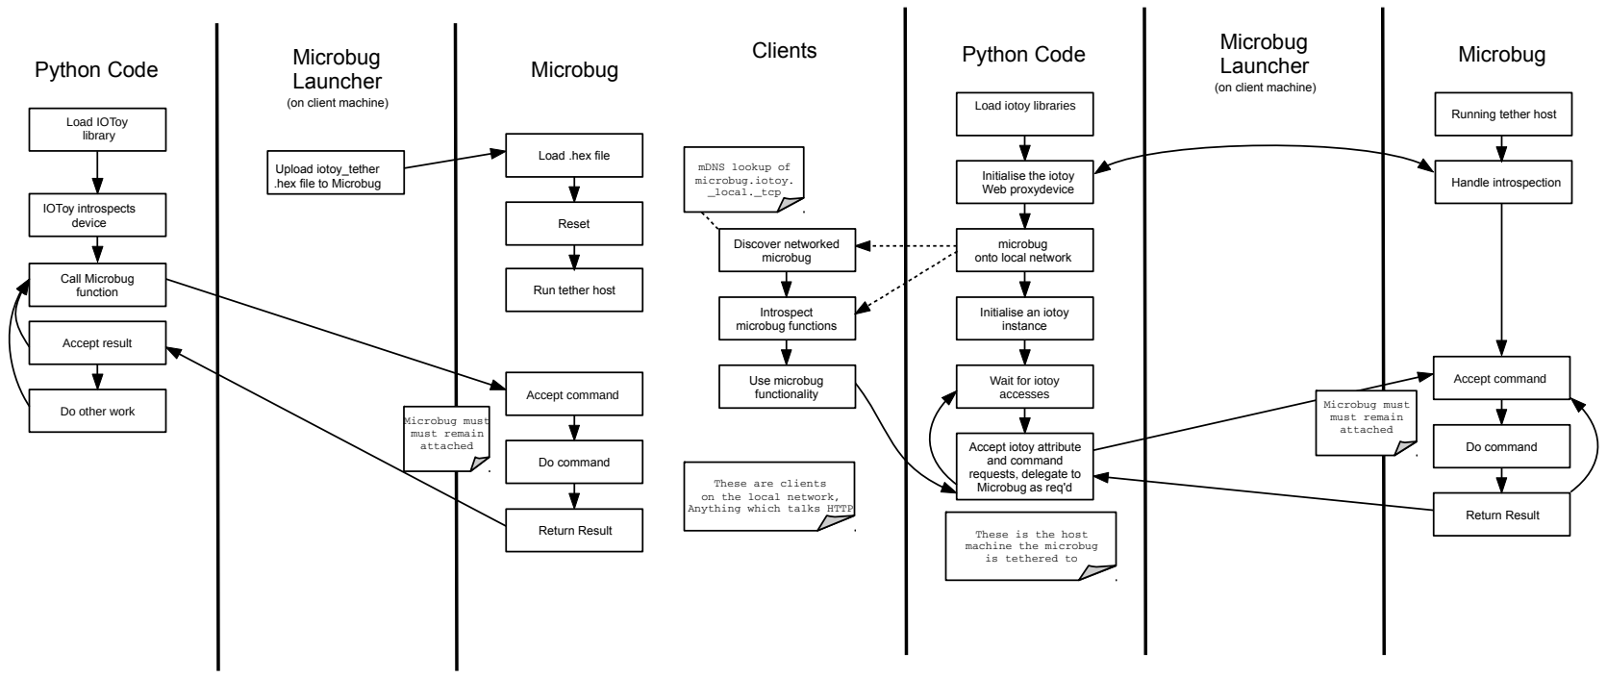
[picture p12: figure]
Microbug Launcher; (on client machine); Upload iotoy_tether .hex file to Microbug; Python Code; Microbug; IOToy introspects device; Load IOToy library; Call Microbug function; Do other work; Load .hex file; Reset; Run tether host; Accept command; Do command; Return Result; Accept result; must; must remain attached; Initialise an iotoy instance; Load iotoy libraries; Accept iotoy attribute and command requests, delegate to Microbug as req'd; Clients; Running tether host; Wait for iotoy accesses; These are clients on the local network, Anything which talks HTTP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

Note: tethering mode does not require the use of a server, or use of a specific language. This allows the device to be used without installing any software specific to the device and discovery of what functionality it supports. Use of bindings and network connectivity do open up wider opportunities

## 1.4.3 Operational overview – Networked tether

Networked tether mode introspects a device, and advertises the device as a RESTful service using mDNS. It also includes client side bindings for autodiscovery and introspection of microbug based IOT devices. The following activity diagram shows how this works from a host/device perspective:

Author: Michael Sparks | 15/100 | BBC Learning Make it Digital Project

Server

Server not
required.
Can be used
entirely
offline

Project Microbug : Functional / Technical Specs | Strictly Confidential | December 2014

Key points:

- The device is introspected as per the tethered mode
- That allows auto-creation of a REST/json oriented webservice, advertised over mDNS using a name derived from the device type
- Clients merely need to follow links In the json data mean in order to introspect the service and use it. What the data types mean is linked to from within the values.
- Sample python bindings are provided for the networked tether mode, but could be implemented in any language which can interact with a REST service that uses json for object structure.
Author: Michael Sparks | 16/100 | BBC Learning Make it Digital Project

Project Microbug : Functional / Technical Specs | Strictly Confidential | December 2014

# 2 Functional Specs

This chapter describes functional requirements of the system and also also non-functional perspectives. Generally speaking it describes what must exist in each layer in terms of functionality. It does not prescribe what that implementation should be.

Clarification of what the functional specification means can be found in two place:

- Firstly in the reference implementation
- The project team

The key focus of the functional spec is:

- To say what functionality is required
- To enable flexibility in the implementation
- To enable interoperation and co-ordination between a heterogeneous implementation.

## 2.1 Safety

The system must be safe:

- This means the device must be electrically sound and safe for an 11 year old to use
- The website must be designed and built with child protection issues and privacy in mind – it should no be possible for someone to be able to identify a child or their work without being their facilitator (eg parent or teacher)
- The web services should be implemented in such a way that data leakage cannot occur. They should also be designed such that they do not compromise the security of the system either directly or indirectly through denial of service attacks
- The client side loader should have a simple and clear implementation, to reduce the chance of the client side loader being a vector for problems for the user, facilitator

## 2.2 Users and Identity in the System

The system identifies the followng core active identities in the system:

- Anonymous users
- Anonymous users granted edit rights
- Users
- Facilitators – those who assist users
- Facilitators of Facilitators.

It should be possible to assert your identity either using a built in system or using an external identity provider. Users who forget their login credentials should be able to recover them, with the potential assistance of a facilitator and/or their device.

More details on this are described in the section on identity in the section on the website and its services.

## 2.3 Flexibility

In so far as possible, as much of the system must be able to be implemented by multiple partners to increase choice and flexibility, while retaining interoperability and compatibility and keeping costs to a minimum.

Author: Michael Sparks | 17/100 | BBC Learning Make it Digital Project

Project Microbug : Functional / Technical Specs | Strictly Confidential | December 2014

## 2.4 Supported Operating Systems

## 2.4.1 Desktop Operating Systems

The minimum supported operating systems for Microbug are:

- Windows (As many versions as practical)
- Mac OS X (As many recent versions as practical)
- Ubuntu (14.04LTS onwards)
- Raspian on Raspberry Pi

Support for other operating systems is very welcome.

## 2.4.2 Tablet / Phone Operating Systems

It is desirable for the Microbug System to have interfaces for running on devices running on leading smartphone and tablet systems. This includes Android (4+), iOS, Windows Surface and others. As with desktop operating systems, support for other operating systems is very welcome.

## 2.5 Device

The device MUST support (at minimum):

- Programming over USB
- For example DFU, generic HID, FAT12 filesystem, etc.
- 25 LEDs – which may be controlled by as few as 10 I/O pins.
- 2 Buttons
- 2 status LEDs
- 4 or more analogue I/O pins – connected to via crocodile clips
- Power from a 2032 battery, USB or external battery
- Additional header connection points to allow more complex expansion capabilities
- The ability to run serial communications over pairs of I/O pins
- Being tethered, including control of the 25 LEDs, detection of button and I/O states, using the protocol described in the section on tethering

Minimum MCU specs (these specs can obviously be exceeded)

- Programs must be able to be created using a command line C (or C++) Compiler, to allow integration with the web platform.
- 8 bit, 16Mhz Clock
- 2K Ram, 16K Flash
- 18 I/O pins, which may be used: 10 LED matrix, 4 analogue I/O, 2 for buttons and 2 for status LEDs.
- A unique identifier
- EEPROM storage, minimum 256bytes, preferred minimum 1K

Desirable non-functional requirements:

- Tool chain that has widespread community support
- Device cost at scale should be £2 or less.
- Croc clips connectors should map to a 1cm grid spacing – to allow integration with other physical prototyping tools.
Author: Michael Sparks | 18/100 | BBC Learning Make it Digital Project

Project Microbug : Functional / Technical Specs | Strictly Confidential | December 2014
- Access to a number of IO pins on the device – perhaps via allowing soldering
of one or more headers to the board, either via 0.1 inch grid pitch headers, or
via ~5mm grid pitch screw in terminal blocks.
- Use of standard spacings and connectors to allow the creation of expansion “shields” to use with the device.
- Bricking of devices is a realistic possibility. While steps can be taken at the software level to try to prevent this, access to appropriate pins to enable last ditch rescue (eg via ISP) is highly desirable.
- Ability to group devices together in at minimum a daisy chain fashion.
- Allow exploration and teaching of IOT concepts

## 2.5.1 Device interface - Device abstraction layer

The purpose of the device abstraction layer (DAL) is to enable a hardware manufacturer to be able to change the implementation of the device right down to chip level, while presenting a consistent interface for the users of the device.

The device abstraction layer is a C++ artefact. It should not use templates, the STL or similar. By definition the device abstraction layer must relate to the hardware of the device and any basic operations.

By necessity therefore the specification of the device abstraction layer is far more specific than any other part of the system. Changes to the DAL are possible, but require co-ordination with other areas and implementors of the system. It is expected that the DAL may extend, but only via pre-agreed co-ordination.

The purpose of the device abstraction layer is to give clearly defined names for each part of the device in a way that leaves the implementation open to the device manufacturer. Essentially it abstracts away details of the hardware to provide core functionality, but without any policies on top of that hardware. It therefore performs a similar role to that of device drivers in a massively simplified single user operating system.

The device abstraction layer manages functionality that is exposed to the end user and that exposed to system implementers.

- User functionality:
- Display management, access and update - including update frequency
- Status LED management and update
- Button management
- Creation, management and display of images
- Creation, management and display of displayable strings
- Getting and setting of pin values for both analogue and digital pins
- Standard names for all device I/Os, and common values
- A font for text display
- Standard library functions, such as random, pause, sleep, memory allocation, tethering mode, EEPROM access, unique Ids, etc
- Startup handling to allow switching into bootloader mode, tethering mode or identity mode
- Provide the standard infrastructure for compiled programs to be inserted into when compiling programs.

As a result the device abstraction layer is a key subsystem in enabling flexibility in the system. Note, the device abstraction layer for a given device may well include other functionality used to implement the device abstraction layer. Use of that additional

Author: Michael Sparks | 19/100 | BBC Learning Make it Digital Project

Project Microbug : Functional / Technical Specs | Strictly Confidential | December 2014

functionality in end user code however is not supported without agreed extension of
the DAL.

This section outlines minimal behaviour in the device abstraction layer. Extensions to the device abstraction layer are possible, and would extend the functionality of the device. Extensions and changes to the device abstraction layer and subsequent interactions with other parts of the system are detailed in section 3.

2.5.1.a Display management
Display assumptions:
- The display assumes a 5x5 LED matrix.
- This 5x5 matrix is controlled by a 5 I/O lines tied to the rows and a further 5 tied to the columns. By marking a row I/O “high” and a column I/O “low”, it allows current to flow between that row I/O and that column I/O, through any LED's connected to turn them on.
- By rapidly selectively marking some columns high, some low, you can iterate different (incompatible) patterns on different columns. This allows a persistence of vision style effect to be used to allow the display to show arbitrary patterns.
- The display updates at a frame-rate of 40Hz.
- As a result the display is driven at a rate of 200Hz to account for the 5 columns.

If a device implementation uses more than 10 I/Os, this ability must be emulated to allow code level compatibility with devices that use just 10 I/Os.

This display update routine is ideally run by a system timer. If this is the case, it should not interfere with hardware or software serial implementations. Ideally this should not interfere with common libraries.

Specific functionality and values:

The following constants are defined regarding the display:

ON, OFF – Constants for on/off levels for the LEDs
DISPLAY_WIDTH, DISPLAY_HEIGHT – Constants defining width/height of display

The following values are symbolic values for the IO pins for the row of LEDs

int row0, row1, row2 , row3 , row4

The following values are symbolic values for the IO pins for each column of LEDs

int col0, col1, col2, col3, col4
The following array is used by the display timer to render the display. Changing the contents of the display changes what is displayed.

int display[DISPLAY_WIDTH][DISPLAY_HEIGHT]
Internal setup functions

void setup_display(); – Initialises the display. (Starts the timer, and the display hander)

Internal test functions.

These are useful for debugging the device, but not intended for end users

void scroll_string(const char * str); – Scrolls the given string across the display – with a delay of 50 milliseconds between scroll steps.

void scroll_string(const char * str, int delay); – Scrolls the given string across
the display – with a delay of delay milliseconds between scroll steps.

Functions defined to operate on the display

void clear_display(); – Clears the values in display[][]
void plot(int x, int y); – Sets display[x][y] to ON
Author: Michael Sparks | 20/100 | BBC Learning Make it Digital Project

Project Microbug : Functional / Technical Specs | Strictly Confidential | December 2014

void unplot(int x, int y); – Sets display[x][y] to OFF
int point(int x, int y); – Returns the ON/OFF value of display[x][y]
void set_display(int image[5][5]); – Copies the array image[][] to display[][]

The following two functions switch on/off the display timer/interrupt

void display_on()

void display_off()
2.5.1.b Status LED
The two status LEDs are provided to allow hinting about different behaviours. For example in DFU bootloader mode both status LEDs are required to light up to hint to the user the device is in “program me” mode. They are currently referred to as “eye” LEDs.

However, in the final board, the status LEDs may be in a different position, so anywhere the API says “eye”, may later be replaced with “statusled”. (For example eye_on may change to statusled_on)

Specific functionality and values:

The following constants are defined regarding the status LEDs:

ON, OFF – Constants for on/off levels for the LEDs

The following values are symbolic values for the IO pins for the two status LEDs

int lefteye, righteye
The following values are used to track the state of the status LEDs

int left_eye_state, right_eye_state
The status LEDs currently can be referred to as “L” and “R”, or “A and “B”

The following functions may be used to manipulate the status LEDs void set_eye(char id, int state); – Sets the status LED to the given state int get_eye(char id, int state); – Sets the status LED's current state void eye_on(char id); – Turn the given status LED on
void eye_off(char id); – Turn the given status LED off
void eye_on(const char *id); – Alternative API (first letter of string) void eye_off(const char *id); – Alternative API (first letter of string) void toggle_eye(char id); – Toggles the given status LED on/off

The alternative API is suggested based on the experience with the reference implementation.

2.5.1.c Buttons
Specific functionality and values:

The following constants are defined regarding the buttons

- PRESSED, UNPRESSED
The following values are symbolic values for the IO pins for the two buttons
- int ButtonA, ButtonB
The following function may be used to query the state of buttons. The buttons currently can be referred to as “A and “B”. Note, the value returned refers to the button state at that instant in time.
- boolean get_button(char id);

2.5.1.d Images
The display can be used to display images. Images in Microbug may be larger or smaller than the display. If the display is smaller than the image, then the display operates as a viewport that can be panned over the image.

Specific functionality and values:

Author: Michael Sparks | 21/100 | BBC Learning Make it Digital Project

Project Microbug : Functional / Technical Specs | Strictly Confidential | December 2014

Images are defined simply as a byte array of ON/OFF values.

The following constants are defined regarding images

___ – This constant – three underscores – is provided to enable string literal representations of images to be clear in source. It is equivalent to “OFF”.

Images do not relate directly to IO pins, and therefore no values are defined relating IO pins to images.

Images are defined as stateful objects. They are defined using the following structure:

typedef struct Image { – This implements...
int width;
int height;
int *data ;
} Image;

The height/width define the interpretation of the data array. The data array is a collection on ON/OFF values. This may also be ON/___ values. An example Image literal is:

Image myImage;

int image_data[] = {
___, ___, ___, ___, ___, ___, ON, ___, ___, ___, ___, ___, ON, ___, ___, ON, ___, ___, ON, ___, ___, ON, ___, ON, ___, ___, ___, ON, ___, ON, ___, ___, ___, ___, ON, ___, ___, ___, ___, ON, ___, ___, ON, ___, ___, ON, ___, ON, ON, ___, ON, ___, ___, ___, ___, ___, ON, ON, ___, ___, ___, ___, ON, ON, ___, ON, ON, ___, ___, ___, ___, ___, ON, ___, ___, ___, ___, ON, ON, ___, ___, ___, ___, ___, ON, ___, ___, ON, ___, ON, ___, ___, ON, ___, ___, ___, ___, ___, ___, ___, ON, ___, ON, ___, ___, ON, ___, ON, ___, ___, ___, ON, ON, ___, ___, ON, ___, ON, ___, ___, ___, ___, ON, ___, ___, ___, ___, ___, };

myImage.width=16;

myImage.height=8;

myImage.data = image_data;

Functions for working with images:

- void showViewport(Image& someImage, int x, int y); – This displays a display sized
viewport starting at location x,y within the image.
- void ScrollImage(Image someImage, boolean loop); – This scrolls an image across
the display. If loop is set to true, when the display viewport scrolls off the image, it displays the wrapped version of the image.
- int image_point(Image& someImage, int x, int y); – Returns the ON/OFF value of
the point at the given location in the image
- void set_image_point(Image& someImage, int x, int y, int value); – Sets the
ON/OFF value of a given point at the given location in the image

Internal function for working with images:

- inline int image_point_index(Image& someImage, int x, int y); – Returns the index
value into the data array for a given point x,y in the image.

2.5.1.e Displayable Strings
In order to display strings on the display, they need to be converted from a collection of character bytes to an image that can be displayed. How this is implemented internally is implementation dependent.

The API defined for use has a working assumption that rather than render a 45 character string as an image 225 pixels by 5 pixels, that instead an optimised version will be used. This is based on optimisations used in the reference implementation where only two characters at a time are rendered to an internal data buffer.

A displayable string is represented by a data structure called a StringImage. This uses a C++ struct. Operations on the struct itself are performed using member methods.

The “current” viewport window on the virtual image is is tracked via a “current pixel

Author: Michael Sparks | 22/100 | BBC Learning Make it Digital Project

Project Microbug : Functional / Technical Specs | Strictly Confidential | December 2014

position” representing the top left corner of the visible viewport.

The fact that the display can only show a subset of the string which is used to optimise
the display given the limited space for data and in RAM on a microcontroller. The current pixel position in a StringImage is one way of achieving using that.

Structures defined here:

- struct StringImage ; – This implements...

Functions defined that operate on StringImages:

- void scroll_string)mage (StringImage theStrImage, int pausetime); – This
implements...

Member Methods in StringImages:

- StringImage(const char * str) – String Image constructor. Initialises the constructor with the given string
- void setString(const char * str) – Changes the string the Image refers to to the given string
- void render_string() – This renders the currently visible portion of the string into the internal image buffer
- void update_display() – Renders the internal image buffer to the display
- void pan_right(); – Increments the internal current pixel position by 1
- void pan_left(); – Decrements the internal current pixel position by 1
- void set_pixel_pos(int pos) – Sets a specific “current” pixel position in the string. A 45 character string is 225 virtual pixels wide.
- int pixel_width(); – Returns the width of the current StringImage in pixels. Implementations may choose to actually store the pixels. In the reference implementation, these are virtual pixels

Possible extensions: to include panning up and down strings, to render strings from right to left, up to down, and down to up, and add addition “pan” and set_pixel_pos alternatives. Extensions are welcome, but this is the minimal core.

2.5.1.f IO Pin Control
Access to and control of IO pins beyond display are really what enables Microbug as a proposition to have greater longevity. This represents a minimal device abstraction layer.

However, this is sufficient for many sensor and control tasks.

The following constants are defined regarding the buttons

- PRESSED, UNPRESSED
The following values are symbolic values for the IO pins for the LED array:
- | int row0, row1, row2, row3, row4 | This implements... –
- | int col0, col1, col2, col3, col4 | This implements... –
The following values are symbolic values for the IO pins for the status LEDs and buttons:
- int lefteye, righteye, ButtonA, ButtonB
The following values are symbolic values for the IO pins for the croc clip connectors
- int lefteye, righteye, ButtonA, ButtonB
- int croc0, croc1, croc2, croc3, croc4, croc5
The headers along the bottom of the device are also usable as digital pins for IO. The specific values available mapping to pins follow. For each header, a second values is given in bold like this: h1 3, h2 4, etc The value in bold is the silkscreen id on the board
Author: Michael Sparks | 23/100 | BBC Learning Make it Digital Project

Project Microbug : Functional / Technical Specs | Strictly Confidential | December 2014

on the headers along the bottom. The values (and mappings) are:

- | int h1 3, h2 4, h3 5, h4 6, h5 7, h6 | 8, h7 9
int h8 10, h9 12, h10 13, h11 14, h12 15, h13 16, h14 17
There are two extra additional hardware pin points on the device – ee19 and ee20. These are designed for emergency or expert use only.

They are accessible from the DAL via the two following symbolic values:

- int ee19, ee20
Functions for working with digital IO pins:
- void set_pin(int pin, int value) – Sets the given pin to HIGH or LOW
- int get_pin(int pin) – Gets the current pin values as HIGH or LOW

Functions for working with analogue IO pins - specifically the croc clip connectors:

- void set_analogue_pin(int pin, int value) – Sets the pin value to a value between

### 0 and 1023

- int get_analogue _pin(int pin) – Gets a pin value – retruns a value between 0 and 1023

2.5.1.g Font
The DAL defines the existence of a 4x5 font. It is designed to be used with a single strip of blank pixels down the right hand side. The specific font defined is included in the appendix to this document.

It is primarily used internally within the DAL, but there are some specific functions that are used regarding the display of letters as images:

- void showLetter(char c) – Renders the given letter into display[][]
- void print_message(const char * message, int pausetime=100); – Renders each letter of the message in sequence onto the display, with a delay between each letter being rendered of pausetime milliseconds
- typedef struct StringImage – as defined In section 2.5.1.e this is used for working with strings as images
- void render_string() – This specifically renders the current visible portion of the string image into it's internal buffer

2.5.1.h Library Functions
There are a collection of library oriented functions in the DAL, which are required for various subsystems.

Basic functions

- long random(int min, int max) – Returns a random number between min and max inclusively
- void pause(int time) – Causes the program to pause execution of time miliiseconds
- void sleep(int time) - Causes the microbug to sleep for the given time period in microseconds. When the device sleeps, all functionality on the device insofar as possible – including display update – comes to a halt

Tether related :

- CommandHostTiny – This class implements the core command host as used by the tethering code. The class implements a number of methods. Those intended to be overridden in a sub class are underlined:
- const char *hostid() - Returns the host id for the device.
- const char * attrs() – Returns a string containing a comma separated list of names representing device attributes.
Author: Michael Sparks | 24/100 | BBC Learning Make it Digital Project

Project Microbug : Functional / Technical Specs | Strictly Confidential | December 2014
- const char * funcs() – Returns a string containing a comma seperated list
of names representing device functionality.
- bool has_help(char * name) – Returns true is the device will return help for the given name
- void help(char * name) – Emits help over the serial console for the given name
- bool exists(char * attribute) – Returns true if the device implements the given attribute
- const char *get(char * attribute) – Called when the serial API requests the given attribute, the response is a string
- int set(char* attribute, char* raw_value) – Called when the serial API
requests the given attribute is set to the given raw value
- int callfunc(char* funcname, char* raw_args) – Called when the serial API
requests the named function to be called with the given argument(s)
- void setup(void) – Mandatory internal setup function

Common library functions:

- int strcmp(string1, string2) – If the two strings are equal, the result is 0.
- int atoi(const char* raw_string); - Converts raw_string to an integer.
- void itoa (int value, char * result_string, base); – Converts a given integer value to a string in the given base, and stores the result in the result_string – which must be large enough to hold the value.
- char * strstr(source_string,search_string) – Searches for search_string within the
source_string. If not found the value returned is NULL, otherwise the value returned is a pointer to where the value is found.

EEPROM Access

NOTE: Addresses 0 to 127 are reserved for use by a DAL implementation

- int get_eebyte(int location) – Reads a value from the given location in EEPROM.
- void set_eebyte(int location, int value) – Sets a value in the given location in
EEPROM
- void set_last_userid(const char*) – Sets the id of the last user to program the device in EEPROM. This is defined as starting at location 0 in DAL reserved space. The first byte is the length of the username
- const char *get_last_userid() –.Gets the user id of the last user to program the device.
- const char *get_unique_id() – Returns a unique id of the device. For devices with a microcontroller with an inbuilt chip ID, this id can be that chip ID. If it's been overridden, then this should return the overridden id, which is stored in EEPROM.
- void set_unique_id(const char* new_id) – Sets the new unique id for the device,
which is stored in EEPROM.

USB

- USBDevice.attach(); - Attaches & initialises the USB connection
- Usb_detach() - Detaches the USB connection

Conversions

- int int(some_float); – Conversts some_float to an integer
- double double(wholepart); - Converts whole_num to a floating point value
Author: Michael Sparks | 25/100 | BBC Learning Make it Digital Project

Project Microbug : Functional / Technical Specs | Strictly Confidential | December 2014

Serial console access

- Serial.begin(int baudrate); - Initialises the serial console at the given baudrate
- Serial.print(const char* name); - Sends the given string to the serial console
- Serial.println(const char* name); – Sends the given string to the serial console followed by a new line
- Serial.available() - Returns the number of bytes available on the serial console
- char Serial.read(); – Returns the next byte from the serial console

2.5.1.i Startup Modes
Functions relevant to system startup mode:
- void bootloader_start(void); - When called, the device resets itself back to its base/initial state and launches the devices' DFU bootloader – assuming a DFU based bootloader (or similar)
- void check_bootkey(); - At start up checks to see if the left hand button is pressed down and switches the device into bootloader mode – could also check the righthand button for an identity start or both buttons for a tethered start.
- void tethered_start() - switches the device into tethered mode
- void identity_start() - Switches the device to identity recovery mode – specifically displays the last programmed username on a loop

2.5.1.j Compiled Program Hosting Infrastructure
Programs that are compiled on the hosting infrastructure should assume:
- #include "dal.h"– This line must be included at the start of the user c++ code
- USBDevice.attach();– This should be called to initialise the USB connector at startup
- void loop()– This should implement the body of the any core functionality that is to be repeated
- void setup()– This should implement the device's required startup. In particular, custom user programs must call microbug_setup – in order to enable the startup modes.
- microbug_setup();– As noted above, this must be called at device startup from the setup() function.

See the reference implementation for more detailed examples.

## 2.5.2 uhex file specification (Universal .hex file format)

The microbug reference implementation at present use .hex files.

A .hex file is a file with many lines of this format:

:1000C00007080B0816081108200000000000210492

:1000D00004040004220A0A000000230A0F0A0F0A7F

:1000E00024060D060B06250902040900260604094C
These lines essentially specify which parts of the flash memory contain which values. Then, when the device is switched into run mode, the MCU starts execution at a given point in memory. This means that the .hex file format for one MCU differs from another radically. The origin of this file format comes from intel and is commonly usefd with lots of microcontrollers.

If there were to be only one possible microcontroller for the microbug device implementation, then we would have only ever one .hex file format to consider. In that scenario, using .hex files directly could make sense.

Author: Michael Sparks | 26/100 | BBC Learning Make it Digital Project

Project Microbug : Functional / Technical Specs | Strictly Confidential | December 2014

However, we need to leave the door open for partners who are willing to manufacture
devices to be able to change implementation details such as the chip at the core of the
system. Additionally, the uhex format allows us to include meta-data.

This necessitates a need to have a file format that allows multiple binary representations to co-exist in a single file. Furthermore, we have a need – due to identity in the system – to be able to state “this hex file was built by this user”. Doing this outside the .hex file has utility, since we can then store that data inthe EEPROM data of the device.

As a result the uhex file format is born.

Specification:

A uhex file is a json format file.

It contains just one json object

That json object has the following fields.

- Build-user – the identity of the user that download this .uhex file
- hexfiles

The hexfiles field relates to a json object of hexfile representations. Each field is a type of hexfile. Each type relates to a given microbug device. There have been 3 iterations of the reference implementation, so valid types at time of writing are: megabug, microbug, microkit. The value of this field is the hexfile itself.

In particular processing of a uhex file can proceed as follows:

import json
data= open( my-program.uhex ).read() “ | ”
j = json.loads(data)
print Built by , j[ build-user ] “ | ” | “ | ”
print Hexfile for microkit , j[ hexfiles ][ microkit ] “ | ” | “ | ” “ | ”
This allows the user's client side loader to load the right sort of code onto the device.

## 2.5.3 Boot Loader

The boot loader is the firmware running on the microcontroller that allows it to be programmed. On entry level devices, this is generally a different mode of running the device. The boot loader is often a feature of either a given chip and/or a given tool chain.

The minimal functional requirements on the bootloader are as follows:

- Must be able to be switched into from software running on the device
- The hardware must make it possible to the device into bootloader mode. If this is generally under software control, this can be of the level of.
- Must be able to accept updated firmware over the USB connection
- Preferably use a recognised protocol for USB update, such as:
- Generic HID
- DFU update
- To present as a file system with firmware file
- Other protocols may be acceptable, depending on cross platform tool support.
- There must be either
- Cross platform command line tools on the supported client operating systems, for communicating with the boot-loader to perform the update.
- A cross platform C-library is a requirement to allow a cross platform firmware update tool to be created.
Devices must be supplied a bootloader installed. If a device is supplied without a program to run, it MUST default to running in the bootloader mode.

For more details on device update, see the next question on the “loader” application.

Author: Michael Sparks | 27/100 | BBC Learning Make it Digital Project

Project Microbug : Functional / Technical Specs | Strictly Confidential | December 2014

## 2.5.4 Loader

The MicroBug loader is an application running on the supported operating systems
has the following core functionality:
- It is a graphical application that takes a compiled program and uploads it to the device.

2.5.4.a Loader Core Characteristics
It has the following preferable characteristics:
- Minimal installation
- It must be a graphical tool – though it must also be possible to use the functionality of the loader as a command line tool.
- No drivers (if possible)
- Integration/launch via a custom mime-type – allowing integration with browsers.
- Provides a helping hand for the user
- Helps prevent “bricking” of devices
- Potentially validates code for upload onto a device
- Potentially validates devices to load onto

Possible characteristic:

- Assists in the creation of automated serial numbers of IOT purposes

2.5.4.b Loader Modes of Operation
There are three possible types of operation

### 1. The device presents as a file system that works identically on the supported

operating systems. This represents the ideal world state.

### 2. The devices presents as a filesystem that has correct operation default

dependent on the operating system in use, and incorrectly on other operating systems.

### 3. The device requires a protocol like DFU update or similar to perform an

update and requires the use of a program or library.

Options 2 and 3 have essentially equal merits due to practicalities, however option 2 has slight preference due to giving at least one operating system a second option.

Option 1

To meet this type of operation

- The device presents as a file system containing one file such as firmware.bin
- This file may be deleted to erase the device
- A new file can be created called firmware.bin, which results in the device being flashed with that image
- The firmware.bin file can be copied off the device for backup purposes
- That all 4 operations MUST operate identically on all of the supported operating systems.

It is our experience of looking at low cost microcontrollers that this functionality does not interact identally on all 4 operating systems. In particular this functionality operates differently on Mac OS X and Windows, due to file handling differences.

If a device does operate this way, then no loader application is required.

However, it may still be be useful for reasons discussed later in tethered mode of

Author: Michael Sparks | 28/100 | BBC Learning Make it Digital Project

Project Microbug : Functional / Technical Specs | Strictly Confidential | December 2014

operation and also to enable standalone/offline usage of the system.

Option 2

To meet this mode of operation, on at least one of the supported operating systems the following behaviour must be possible:

- The device presents as a filesystem containing one file such as firmware.bin
- This file may be deleted to erase the device
- A new file can be created called firmware.bin, which results in the device being flashed with that image
- The firmware.bin file can be copied off the device for backup purposes

Other operating systems may interact with this process differently. If that is the case, the following must be true:

- The device presents as a filesystem containing one file such as firmware.bin
- This file should not be deleted
- It must be possible to update the firmware.bin file in place – ala unix tools like “dd”
- The firmware.bin file can be copied off the device for backup purposes

In devices that support file systems, it is our experience of looking at low cost micro controllers that this mixed handling of file systems on different operating systems is the common case. Asking users on one operating system to use “dd”, and others to simply copy files is liable to leave to confusion.

Given the differences in behaviour between the supported operating systems, a loader application is still required. The reason for this is to ensure that all users of the device have the ability to update their device in a way that matches the same instructions for any given device. This allows users of the device to share their knowledge about how the device works without worrying about what operating system they're using, since they may not even know.

On the operating system where the file-system operates as the device expects, the file system based approach is something that can be used. However doing so will be treated as an emergency alternative.

As a result, the preferred approach will be to use a loader application in option 2.

Option 3

While this approach should use a standard protocol for update, the protocols generally used are often only supported via a stand alone application.

In this scenario, the loader application should operate cross platform and ideally have as few requirements as possible. It must be a graphical tool, but that graphical tool may wrap a command line tool.

## 2.6 Offline Support

Offline support is highly desirable, but not a core functional requirement. Offline support could be implemented the following approach:

- Running a webserver inside the loader application. (for example, using the built in server to django or flask)
- Ensuring that webserver can only be accessed from the local server
- Allowing the web application that runs the website to run off that server

For example, shipping the reference implementation as a client side application running behind a Flask/Django webserver is something that could be done. This has not been done for the reference implementation, but is something that could be desirable, and would fulfill this functional requirement.

Author: Michael Sparks | 29/100 | BBC Learning Make it Digital Project

Project Microbug : Functional / Technical Specs | Strictly Confidential | December 2014

While 95% of homes have broadband facility, 5% of homes in raw numbers is still a
very high number of homes, and often in under served demographics.

Speculative solutions for offline support are therefore an open area for discussion.

## 2.7 Browser Requirements

The preferred browser support requirements are detailed here:

http://www.bbc.co.uk/guidelines/futuremedia/technical/browser_support.shtml

In particular, those creating web related content should target Level 1 clients as per those requirements. The key requirements on the browsers are:

- To support modern drap and drop based editting of graphical program code
- To support modern text based editting of textual program code
- HTML5 Canvas support – for rendering graphical views and simulators

Ideally creators of various web components in the system should bear in mind that the first contact with the device is likely to be through schools. Schools often do not run the most recent versions of browsers, so it would be wise to consider supporting level 2 browsers.

In particular though, implementations should state which level they support.

## 2.8 Identity

Identity in Microbug has the following core working assumptions, principles and core requirements:

- All users have poor memories, and identities do get compromised.
- The prime users are children – that is vulnerable users.
- Uniquely identifying information regarding prime users MUST NOT be stored in the microbug system. The system should actively aim to dissuade/prevent the storage of uniquely identifying information for prime users.
- Every prime user of the system will have their own microbug device, programmed by that prime user. Microbug devices will change owners – either accidentally, or deliberately.
- Every prime user has at least one helper, or facilitator:
- Examples: parents, teachers, youth group leaders, scout/guide leaders, etc. ie a person with whom the child already has a pre-existing mentor/mentee relationship.
- A facilitator's systematic purpose is to assist prime users with account details – password resets, account recovery, etc. Functionality revolving around facilitators is there to support prime users usage of the system. Only minimal information will be stored to enable facilitation
- Facilitators may use the system in the same way as a prime user
- Every facilitator may themselves have a facilitator – a super-facilitator. (That is someone who can assist them with their account)
- Facilitators can only “see” accounts they directly facilitate (& own)
- Prime users will need to change/add/remove facilitators
- A prime user must not be a facilitator
- Accounts:
- A prime user needs a way to recover their account in the event of losing their account details, and having disconnected their facilitators
Author: Michael Sparks | 30/100 | BBC Learning Make it Digital Project

Project Microbug : Functional / Technical Specs | Strictly Confidential | December 2014
- Users can self register as prime users or as facilitators, in the event of
account loss.
- Attempts should be made to prevent prime users registering as facilitators. For example, having facilitators confirmed as adults by other facilitators. eg via manually or via a confirmation code style approach etc.
- Distribution chain
- It is currently expected that devices will be gifted to children through schools. There could be other mechanisms, but the key point is they will be distributed through adults who facilitate groups of children.
- It is currently expected that devices will be distributed in batches of a given size. Each batch can include an equal number of pre-generated identities. This can include a confirmation code.
- Devices are programmed by a user with a given identity using a loader application. In addition to loading the program into flash, that identity could be loaded into EEPROM data.

This description of identity very deliberately avoids discussion of how this will be implemented. Any authentication mechanism is used is orthoganal to this set of role requirements. This model of identity is based on taking best practice forms of prime user and facilitators from a variety of groups and systems.

Specifically the following approaches have been used as starting points:

- Online children communities – such as Moshi Monters, Club Penguin, Bin Weevils etc. These all use a parental facilitator to act as a helper to the child. The difference here is that we can provide facilitators usernames/passwords upfront, and that the initial batch of facilitators are guaranteed to be adults.
- Electronic ID tokens. The system takes advantage of the fact that we have a physical device that the child owns. We can use it to assist in account reminders. While this isn't a traditional eID token, this approach of using a physical programmable device to store/retrieve a piece of unique information to assist with login is inspired by various eID tokens.
- Scout & Guiding organisations. Scout and guiding organisations has 100 years of experience in terms of managing adults in assisting volunteers in mentoring, guiding & protecting children. The idea of using facilitators to confirm facilitators, is based on the model used in scouting. In particular, adults must be vouched for by other adults in order to be added to scouting systems. If a weak link is discovered, then any weak links can be audited and dependent links broken.
- The idea of a super-facilitator – that a facilitator can have a facilitator, is based on many standard models of system administration. In youth organisations this may map to a group leader or district leader. In groups of parents this could map to a parent who happens to be particularly tech-savvy. In schools this could map to an IT manager/assistant, an ICT teacher. By making it such that the superfacilitator cannot see the view of the system the facilitator has, it doesn't risk or enable access to prime users.

## 2.8.1 Operation of Identity

The descriptions within the following scenarios are illustrative, not prescriptive.

The system MUST support prime users in the following optimal scenarios and failure scenarios for identity. We would expect that if taken on by a partner that identity would be fleshed out to meet best practice. Furthermore, any implementation of identity is subject to ratification according to BBC Editorial Policy, specifically including those revolving around child protection guidelines and information security.

Author: Michael Sparks | 31/100 | BBC Learning Make it Digital Project

Project Microbug : Functional / Technical Specs | Strictly Confidential | December 2014

Optimal Scenario:

- The facilitator has pre-installed the loader software on the machines the prime
users will be using.
- A batch of devices are shipped to a facilitator along with a list of usernames & passwords on an accompanying sheet. This includes a facilitator username/password
- The facilitator gives devices, usernames and passwords to prime users
- The prime users can then use the system and program their devices. If they log in, their programs are saved to their identity
- Facilitator asks prime users to edit their preferences to set the name the facilitator knows them by. (For example Adam or Adam S)
- Facilitator asks prime users to edit their preferences to answer the short survey that's there as well. The answers to the survey are there as a last ditch approach to unlocking their account.
- The facilitator confirms their email with their username. Upon confirming sees the list of prime users they facilitate, including the names they know them by.

This scenario allows the facilitator to just give out the devices and run with it. It doesn't involve a lengthy registration period. The aim is to enable the prime users and facilitators first experience to be painless.

Failure Scenario: Fail to receive a sheet with usernames/passwords in a batch (A)

- They could re-request a new sheet – the sheet is in no way tied to any particular batch.

Failure Scenario: Fail to receive a sheet with usernames/passwords in a batch (B)

- Prime users can self register on the system
- The facilitator can self register on the system
- The prime users can add the facilitator's username
- The facilitator can add a username of another facilitator to confirm them (in a school this would be another teacher. The alternative is via the distribution chain)
- Once the facilitator is confirmed, the facilitator can then confirm they are facilitating those prime users.

Failure Scenario: Prime user forgets password

- Prime user goes to website, clicks forgotten password, enters username
- Facilitator is informed, goes to their profile, resets password
- Facilitator gives new password to prime user face to face

Failure Scenario: Prime user forgets username

- Prime user goes to facilitator, asks for username
- Facilitator gives prime user name face to face

Failure Scenario: Prime user forgets username, facilitator doesn't remember, prime user set up account

- Prime user forgets username, facilitator doesn't remember
- Facilitator logs into site
- Goes to the list of prime users they facilitate
- Finds the name they know the prime user by
- Gives prime user their username
Author: Michael Sparks | 32/100 | BBC Learning Make it Digital Project

Project Microbug : Functional / Technical Specs | Strictly Confidential | December 2014

Failure Scenario: Prime user forgets username, prime user programmed their device
last, device based reminder
- User switches on device, holding down button B.
- Device switches to reminder mode
- Device scrolls the username stored in EEPROM

Failure Scenario: Prime user forgets password, no active facilitator

- Prime user goes to website, clicks on forgot password
- User selects the child friendly option that means “no active faciltator to reset password”
- Child is given survey based on the questions they answered when given the bug
- If they get “enough” correct, they are provided with a new passwords

Once again, the requirement here is to handle these failure scenarios gracefully, and the mechanisms described here are illustrative, not prescriptive.

## 2.8.2 Authentication

In this context, authentication means the assertion and verification of an identity within the system. Clearly there are many mechanisms that could be used here. It is preferable that users are able to use their preferred form of identity within the system, without losing the benefits described in the previous section.

In the previous section where one possible mode of operation exists for identity there is a working assumption of a particular form of authentication.

That particular sequence of illustrations assume:

- That usernames/passwords can be pre-generated
- That they can be associated with identity roles within the system
- That relationships between identity roles within the system can be dealt with.

The illustrative solutions to the scenarios presented there are highly desirable because they have the key benefits:

- No knowledge of prime user identity
- Takes advantage of the pre-existing face to face relationship between mentors and mentees
- Takes advantage of the fact there is a device to help the user authenticate themselves.

Clearly these identity aspects can be implemented in many ways. An ideal implementation for authentication would enable prime users and facilitators to asset other online identities match their identity in the system such they can be then authenticated using an external system.

For example schools have online systems already. While the device is clearly the prime users' device, not the schools, being able to assert a school identity is also your identity would be useful since then the prime user could assert their identity using their school login.

Furthermore, if the prime user is older than 13, they (like facilitators) may have other services that they would wish to use to assert their identity. These potentially include service like Google+, Facebook,, and OAuth2 based services – such as twitter.

Use of such services should not be enabled for prime users younger than 13 for legal reasons, and also to not encourage prime users to use such services they should not have access to.

Author: Michael Sparks | 33/100 | BBC Learning Make it Digital Project

Project Microbug : Functional / Technical Specs | Strictly Confidential | December 2014

It is likely therefore that any implementation of identity may have a fall back
implementation which accompanies the distribution of devices – to bootstrap a users
identity within the system. As time progresses they become able to assert other
preferred identities. These preferred identities could then be used to unlock their account – reducing the prime users dependency on the facilitator.

The authentication scheme chosen should be clearly described, including it's interface to other mechanisms to allow a preferred pre-existing identity to be asserted as matching an identity within the Microbug system.

Secondly since services the Microbug system uses may be implemented by multiple vendors on multiple systems, any implementation of authentication for microbug needs to support authentication for those services.

Specific non-exhaustive requirements:

- Ability to confirm the identity of a specific user within the system
- Ability to assist in the management of the relationship between user roles within the system
- Ability to asset an identity within the Microbug system matches another identity outside the Microbug system, and then to be able to identity as that Microbug identity through trust in that external system. External identity vendors include :
- School authentication mechanisms (such as wayf etc.)
- Youth organisation authentication schemes.
- Common educational authentication schemes
- Commonly used internet authentication schemes – such as Google+, Facebook ID, Microsoft Account (formerly Windows Live ID), OAuth2, etc. This is not an exhaustive set nor does it recommend one external

ID system over another.

- Pre-shared Public Key - Private Key systems etc.
- Able to assert to an sub-system implemented separately that the user using the sub system is a given Microbug identity, with a given role type. Microbug subsystems implemented independently may include:
- Editing tools, apps and services
- Storage systems
- Tutorial systems
- Any implementation of authentication must match current best practice – it should not be practical for a user to steal another users account, nor should it be possible to derive user passwords from a compromised machine
- If pre-generated identities are used, it should be based on a mechanism that results in memorable ideas, and should not result in offensive identities. Any pre-generated passwords should be ephemeral and changed upon log on.
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

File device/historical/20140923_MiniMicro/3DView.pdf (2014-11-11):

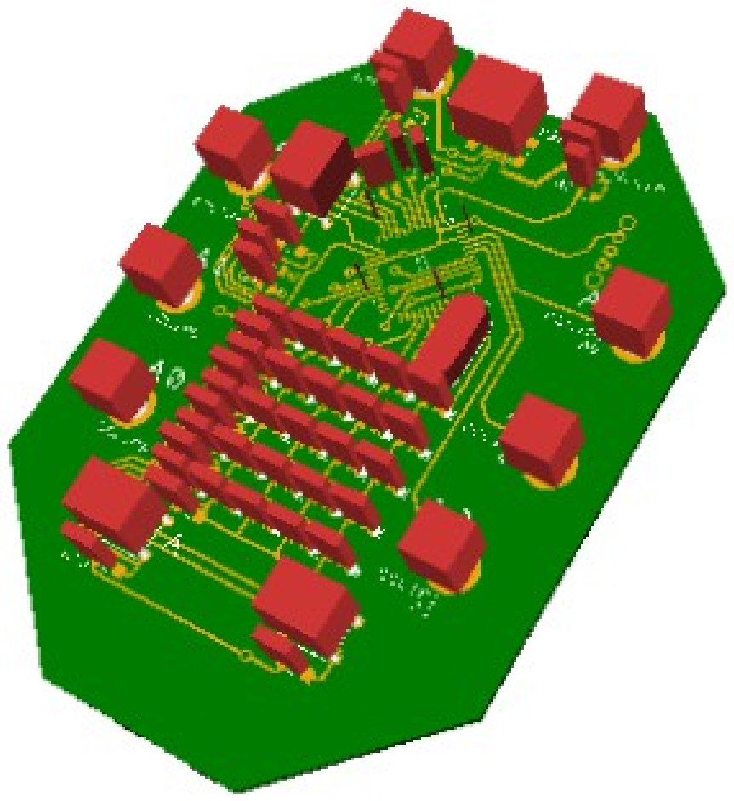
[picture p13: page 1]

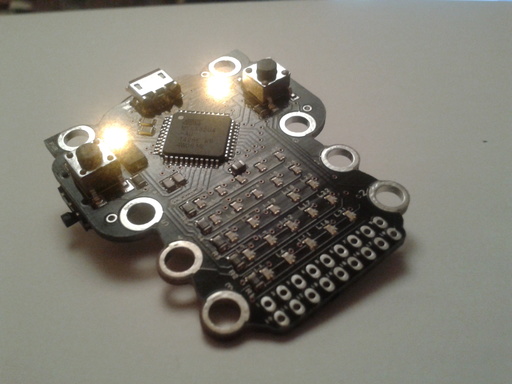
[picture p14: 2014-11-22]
loader/microbug-small.jpg

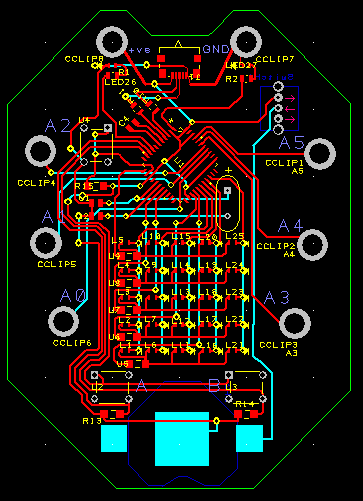
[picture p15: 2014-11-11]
device/historical/20140923_MiniMicro/MiniMicro_PCB_Snapshot.png

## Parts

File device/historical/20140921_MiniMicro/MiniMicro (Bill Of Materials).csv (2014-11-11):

Report Written : Friday | September 19 | 2014 12:25
Project Path : C:\Users\michaels\Documents\MiniMicro\MiniMicro.prj
Design Path : C:\Users\michaels\Documents\MiniMicro\MiniMicro_Sheet1.sch
Design Title :
Created :
Last Saved : 19/09/2014 12:19:49
Editing Time : 59 min
Units : thou (precision 2)
Bill of Materials generated with DesignSpark PCB - www.DesignSpark.com/pcb
--------------------------------------------------------------------------
Ref Name | Qty | Component | Value | Package | Manufacturer | MPN | RS Part Number | Other Part Number | Description
U1 | 1 | ATMEGA32U4-AU |  | 44ML-L | Atmel | ATMEGA32U4-AU | 7153805 |  | MCU AVR 32K FLASH 16MHZ 44-TQFP
C4 | 1 | C0805C106K4PACTU |  | CAP_C0805-L | Kemet Electronics | C0805C106K4PACTU
R2 | 1 | CFR25J10K |  | RES_CFR25_TYCO | Tyco Electronics | CFR25J10K | 131378 |  | CFR25 carbon film resistor,10K 0.33W
R1 | 1 | CFR25J10K |  | RES_CFR25_TYCO | Tyco Electronics | CFR25J10K | 131378 |  | CFR25 carbon film resistor,10K 0.33W
R4 | 1 | CFR25J220R |  | RES_CFR25_TYCO | Tyco Electronics | CFR25J220R | 131176 |  | CFR25 carbon film resistor,220R 0.33W
R3 | 1 | CFR25J220R |  | RES_CFR25_TYCO | Tyco Electronics | CFR25J220R | 131176 |  | CFR25 carbon film resistor,220R 0.33W
R7 | 1 | CFR25J220R |  | RES_CFR25_TYCO | Tyco Electronics | CFR25J220R | 131176 |  | CFR25 carbon film resistor,220R 0.33W
R6 | 1 | CFR25J220R |  | RES_CFR25_TYCO | Tyco Electronics | CFR25J220R | 131176 |  | CFR25 carbon film resistor,220R 0.33W
R5 | 1 | CFR25J220R |  | RES_CFR25_TYCO | Tyco Electronics | CFR25J220R | 131176 |  | CFR25 carbon film resistor,220R 0.33W
C1 | 1 | DEC1X3J220JC4B |  | CAP_9X7 | Murata | DEC1X3J220JC4B
C2 | 1 | DEC1X3J220JC4B |  | CAP_9X7 | Murata | DEC1X3J220JC4B
C3 | 1 | DEC1X3J220JC4B |  | CAP_9X7 | Murata | DEC1X3J220JC4B
LED7 | 1 | LNJ237W82RA |  | LED_LNJ | Panasonic | LNJ237W82RA | 7160522 |  | LED, Red, SMD, Top view
LED8 | 1 | LNJ237W82RA |  | LED_LNJ | Panasonic | LNJ237W82RA | 7160522 |  | LED, Red, SMD, Top view
LED24 | 1 | LNJ237W82RA |  | LED_LNJ | Panasonic | LNJ237W82RA | 7160522 |  | LED, Red, SMD, Top view
LED9 | 1 | LNJ237W82RA |  | LED_LNJ | Panasonic | LNJ237W82RA | 7160522 |  | LED, Red, SMD, Top view
LED25 | 1 | LNJ237W82RA |  | LED_LNJ | Panasonic | LNJ237W82RA | 7160522 |  | LED, Red, SMD, Top view
LED22 | 1 | LNJ237W82RA |  | LED_LNJ | Panasonic | LNJ237W82RA | 7160522 |  | LED, Red, SMD, Top view
LED23 | 1 | LNJ237W82RA |  | LED_LNJ | Panasonic | LNJ237W82RA | 7160522 |  | LED, Red, SMD, Top view
LED13 | 1 | LNJ237W82RA |  | LED_LNJ | Panasonic | LNJ237W82RA | 7160522 |  | LED, Red, SMD, Top view
LED20 | 1 | LNJ237W82RA |  | LED_LNJ | Panasonic | LNJ237W82RA | 7160522 |  | LED, Red, SMD, Top view
LED12 | 1 | LNJ237W82RA |  | LED_LNJ | Panasonic | LNJ237W82RA | 7160522 |  | LED, Red, SMD, Top view
LED21 | 1 | LNJ237W82RA |  | LED_LNJ | Panasonic | LNJ237W82RA | 7160522 |  | LED, Red, SMD, Top view
LED11 | 1 | LNJ237W82RA |  | LED_LNJ | Panasonic | LNJ237W82RA | 7160522 |  | LED, Red, SMD, Top view
LED10 | 1 | LNJ237W82RA |  | LED_LNJ | Panasonic | LNJ237W82RA | 7160522 |  | LED, Red, SMD, Top view
LED17 | 1 | LNJ237W82RA |  | LED_LNJ | Panasonic | LNJ237W82RA | 7160522 |  | LED, Red, SMD, Top view
LED16 | 1 | LNJ237W82RA |  | LED_LNJ | Panasonic | LNJ237W82RA | 7160522 |  | LED, Red, SMD, Top view
LED15 | 1 | LNJ237W82RA |  | LED_LNJ | Panasonic | LNJ237W82RA | 7160522 |  | LED, Red, SMD, Top view
LED1 | 1 | LNJ237W82RA |  | LED_LNJ | Panasonic | LNJ237W82RA | 7160522 |  | LED, Red, SMD, Top view
LED14 | 1 | LNJ237W82RA |  | LED_LNJ | Panasonic | LNJ237W82RA | 7160522 |  | LED, Red, SMD, Top view
LED2 | 1 | LNJ237W82RA |  | LED_LNJ | Panasonic | LNJ237W82RA | 7160522 |  | LED, Red, SMD, Top view
LED3 | 1 | LNJ237W82RA |  | LED_LNJ | Panasonic | LNJ237W82RA | 7160522 |  | LED, Red, SMD, Top view
LED4 | 1 | LNJ237W82RA |  | LED_LNJ | Panasonic | LNJ237W82RA | 7160522 |  | LED, Red, SMD, Top view
LED19 | 1 | LNJ237W82RA |  | LED_LNJ | Panasonic | LNJ237W82RA | 7160522 |  | LED, Red, SMD, Top view
LED5 | 1 | LNJ237W82RA |  | LED_LNJ | Panasonic | LNJ237W82RA | 7160522 |  | LED, Red, SMD, Top view
LED18 | 1 | LNJ237W82RA |  | LED_LNJ | Panasonic | LNJ237W82RA | 7160522 |  | LED, Red, SMD, Top view
LED6 | 1 | LNJ237W82RA |  | LED_LNJ | Panasonic | LNJ237W82RA | 7160522 |  | LED, Red, SMD, Top view
XTAL1 | 1 | XTAL | 16KHZ | DSC | Euroquartz | 16.000MHz HC49/4H/30/50/-40+85/18pF/ATF | 6938819

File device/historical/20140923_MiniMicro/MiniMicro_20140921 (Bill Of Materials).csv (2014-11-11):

Report Written : Monday | September 22 | 2014 12:17
Project Path : C:\Users\michaels\Documents\MiniMicro_20140921\MiniMicro_20140921.prj
Design Path : C:\Users\michaels\Documents\MiniMicro_20140921\MiniMicro_20140921.pcb
Design Title :
Created : 21/09/2014 12:47:43
Last Saved : 22/09/2014 12:14:15
Editing Time : 613 min
Units : thou (precision 0)
Bill of Materials generated with DesignSpark PCB - www.DesignSpark.com/pcb
--------------------------------------------------------------------------
Ref Name | Qty | Component | Value | Package | Manufacturer | MPN | RS Part Number | Other Part Number | Description
XTAL2 | 1 | 16MhzCrystal |  | USER | Euroquartz | 16.000MHz HC49/4H/30/50/-40+85/18pF/ATF | 6938819 |  | 16Mhz Crystal Oscillator
BH2 | 1 | 2032_BatteryHolder_SMT |  | USER | Keystone | 3 003 | 2197960 |  | 2032 Surface mounted battery holder
C1 | 1 | 08051A220JAT2A |  | CAP_C0G_0805-L | AVX | 08051A220JAT2A | 4646587 |  | AVX 0.022 nF ±5 % 100 V dc C0G Dielectric SMD Ceramic Multilayer Capacitor 0805
C2 | 1 | 08051A220JAT2A |  | CAP_C0G_0805-L | AVX | 08051A220JAT2A | 4646587 |  | AVX 0.022 nF ±5 % 100 V dc C0G Dielectric SMD Ceramic Multilayer Capacitor 0805
J1 | 1 | 1981568-1 |  | CONN_1981568-1 | Tyco Electronics Amp | 1981568-1 | 6694645 |  | Micro USB Receptacle type B
U1 | 1 | ATMEGA32U4-AU |  | 44ML-L | Atmel | ATMEGA32U4-AU | 7153805 |  | MCU AVR 32K FLASH 16MHZ 44-TQFP
C4 | 1 | C0805C106K4PACTU |  | CAP_C0805-L | Kemet Electronics | C0805C106K4PACTU | 6911161 |  | Kemet 10000 nF ±10 % 16 V dc X5R Dielectric SMD Ceramic Multilayer Capacitor 0805
U5 | 1 | CMA02040X2200GB300 |  | CMA_0204 | Vishay | CMA02040X2200GB300 | 6845985 |  | CMA0204 Resistor T/R,0.25W,2%,220R
U6 | 1 | CMA02040X2200GB300 |  | CMA_0204 | Vishay | CMA02040X2200GB300 | 6845985 |  | CMA0204 Resistor T/R,0.25W,2%,220R
U7 | 1 | CMA02040X2200GB300 |  | CMA_0204 | Vishay | CMA02040X2200GB300 | 6845985 |  | CMA0204 Resistor T/R,0.25W,2%,220R
U8 | 1 | CMA02040X2200GB300 |  | CMA_0204 | Vishay | CMA02040X2200GB300 | 6845985 |  | CMA0204 Resistor T/R,0.25W,2%,220R
U9 | 1 | CMA02040X2200GB300 |  | CMA_0204 | Vishay | CMA02040X2200GB300 | 6845985 |  | CMA0204 Resistor T/R,0.25W,2%,220R
R10 | 1 | CRCW080522R0FKEA |  | RES_CRCW_0805-L | Vishay | CRCW080522R0FKEA | 6791112 |  | CRCW0805 Resistor T/R 0.125W,1%,22R
R11 | 1 | CRCW080522R0FKEA |  | RES_CRCW_0805-L | Vishay | CRCW080522R0FKEA | 6791112 |  | CRCW0805 Resistor T/R 0.125W,1%,22R
R1 | 1 | CRG0805F1K0 |  | RES0805_CRG_TYCO-L | Tyco Electronics Uk | CRG0805F1K0 | 2230427 |  | CRG0805 SMT chip resistor,1K 0.125W
R2 | 1 | CRG0805F1K0 |  | RES0805_CRG_TYCO-L | Tyco Electronics Uk | CRG0805F1K0 | 2230427 |  | CRG0805 SMT chip resistor,1K 0.125W
U2 | 1 | FSM2JH |  | SWITCH_FSM2JH | Tyco | FSM2JH | 4791390 |  | 6x6mm tactile switch,4.3mm H 1.6N
U3 | 1 | FSM2JH |  | SWITCH_FSM2JH | Tyco | FSM2JH | 4791390 |  | 6x6mm tactile switch,4.3mm H 1.6N
U4 | 1 | FSM2JH |  | SWITCH_FSM2JH | Tyco | FSM2JH | 4791390 |  | 6x6mm tactile switch,4.3mm H 1.6N
L1 | 1 | LNJ237W82RA |  | LED_LNJ | Panasonic | LNJ237W82RA | 7160522 |  | LED, Red, SMD, Top view
L2 | 1 | LNJ237W82RA |  | LED_LNJ | Panasonic | LNJ237W82RA | 7160522 |  | LED, Red, SMD, Top view
L3 | 1 | LNJ237W82RA |  | LED_LNJ | Panasonic | LNJ237W82RA | 7160522 |  | LED, Red, SMD, Top view
L4 | 1 | LNJ237W82RA |  | LED_LNJ | Panasonic | LNJ237W82RA | 7160522 |  | LED, Red, SMD, Top view
L5 | 1 | LNJ237W82RA |  | LED_LNJ | Panasonic | LNJ237W82RA | 7160522 |  | LED, Red, SMD, Top view
L6 | 1 | LNJ237W82RA |  | LED_LNJ | Panasonic | LNJ237W82RA | 7160522 |  | LED, Red, SMD, Top view
L7 | 1 | LNJ237W82RA |  | LED_LNJ | Panasonic | LNJ237W82RA | 7160522 |  | LED, Red, SMD, Top view
L8 | 1 | LNJ237W82RA |  | LED_LNJ | Panasonic | LNJ237W82RA | 7160522 |  | LED, Red, SMD, Top view
L9 | 1 | LNJ237W82RA |  | LED_LNJ | Panasonic | LNJ237W82RA | 7160522 |  | LED, Red, SMD, Top view
L10 | 1 | LNJ237W82RA |  | LED_LNJ | Panasonic | LNJ237W82RA | 7160522 |  | LED, Red, SMD, Top view
L11 | 1 | LNJ237W82RA |  | LED_LNJ | Panasonic | LNJ237W82RA | 7160522 |  | LED, Red, SMD, Top view
L12 | 1 | LNJ237W82RA |  | LED_LNJ | Panasonic | LNJ237W82RA | 7160522 |  | LED, Red, SMD, Top view
L13 | 1 | LNJ237W82RA |  | LED_LNJ | Panasonic | LNJ237W82RA | 7160522 |  | LED, Red, SMD, Top view
L14 | 1 | LNJ237W82RA |  | LED_LNJ | Panasonic | LNJ237W82RA | 7160522 |  | LED, Red, SMD, Top view
L15 | 1 | LNJ237W82RA |  | LED_LNJ | Panasonic | LNJ237W82RA | 7160522 |  | LED, Red, SMD, Top view
L16 | 1 | LNJ237W82RA |  | LED_LNJ | Panasonic | LNJ237W82RA | 7160522 |  | LED, Red, SMD, Top view
L17 | 1 | LNJ237W82RA |  | LED_LNJ | Panasonic | LNJ237W82RA | 7160522 |  | LED, Red, SMD, Top view
L18 | 1 | LNJ237W82RA |  | LED_LNJ | Panasonic | LNJ237W82RA | 7160522 |  | LED, Red, SMD, Top view
L19 | 1 | LNJ237W82RA |  | LED_LNJ | Panasonic | LNJ237W82RA | 7160522 |  | LED, Red, SMD, Top view
L20 | 1 | LNJ237W82RA |  | LED_LNJ | Panasonic | LNJ237W82RA | 7160522 |  | LED, Red, SMD, Top view
L21 | 1 | LNJ237W82RA |  | LED_LNJ | Panasonic | LNJ237W82RA | 7160522 |  | LED, Red, SMD, Top view
L22 | 1 | LNJ237W82RA |  | LED_LNJ | Panasonic | LNJ237W82RA | 7160522 |  | LED, Red, SMD, Top view
L23 | 1 | LNJ237W82RA |  | LED_LNJ | Panasonic | LNJ237W82RA | 7160522 |  | LED, Red, SMD, Top view
L24 | 1 | LNJ237W82RA |  | LED_LNJ | Panasonic | LNJ237W82RA | 7160522 |  | LED, Red, SMD, Top view
L25 | 1 | LNJ237W82RA |  | LED_LNJ | Panasonic | LNJ237W82RA | 7160522 |  | LED, Red, SMD, Top view
LED26 | 1 | LNJ837W83RA |  | LED_LNJ | Panasonic | LNJ837W83RA | 7160538 |  | LED, Orange, SMD, Top view
LED27 | 1 | LNJ837W83RA |  | LED_LNJ | Panasonic | LNJ837W83RA | 7160538 |  | LED, Orange, SMD, Top view
R13 | 1 | MMA02040E1002BB100 |  | RES_MMA_0204 | Vishay | MMA02040E1002BB100 | 6787570 |  | MMA0204 Melf Resistor T/R, 0.07W, 10K
R14 | 1 | MMA02040E1002BB100 |  | RES_MMA_0204 | Vishay | MMA02040E1002BB100 | 6787570 |  | MMA0204 Melf Resistor T/R, 0.07W, 10K
R15 | 1 | MMA02040E1002BB100 |  | RES_MMA_0204 | Vishay | MMA02040E1002BB100 | 6787570 |  | MMA0204 Melf Resistor T/R, 0.07W, 10K
Switch1 | 1 | SlideSwitch |  | SlideSwitch_SPDT | C & K | OS102011MA1QN1 | 7874855 |  | Through Hole Slide Switch SPDT On-On 0.1 A@ 12 V dc Slide

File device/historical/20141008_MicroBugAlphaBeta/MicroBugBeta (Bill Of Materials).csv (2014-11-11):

Report Written : Wednesday | October 08 | 2014 17:42
Design Path : C:\Users\michaels\Documents\MicroBugAlpha\MicroBugBeta.sch
Design Title :
Created :
Last Saved : 06/10/2014 15:28:19
Editing Time : 231 min
Units : thou (precision 2)
Bill of Materials generated with DesignSpark PCB - www.DesignSpark.com/pcb
--------------------------------------------------------------------------
Ref Name | Qty | Component | Value | Package | Manufacturer | MPN | RS Part Number | Other Part Number | Description
BH1 | 1 | 2032_BatteryHolder_SMT |  | USER | Keystone | 3003 | 2197960
C1 | 1 | 08051A220JAT2A |  | CAP_C0G_0805-L | AVX | 08051A220JAT2A
C2 | 1 | 08051A220JAT2A |  | CAP_C0G_0805-L | AVX | 08051A220JAT2A
MicroUSB | 1 | 1981568-1 |  | CONN_1981568-1 | Tyco Electronics Amp | 1981568-1 | 6694645 |  | Micro USB Receptacle type B
U1 | 1 | ATMEGA32U4-AU |  | 44ML-L | Atmel | ATMEGA32U4-AU | 7153805 |  | MCU AVR 32K FLASH 16MHZ 44-TQFP
C3 | 1 | C0805C105K4RACTU |  | CAP_C0805-L | Kemet Electronics | C0805C105K4RACTU
R8 | 1 | CRG0805F10K |  | RES0805_CRG_TYCO-L | Tyco Electronics Uk | CRG0805F10K | 2230562 |  | CRG0805 SMT chip resistor,10K 0.125W
R9 | 1 | CRG0805F10K |  | RES0805_CRG_TYCO-L | Tyco Electronics Uk | CRG0805F10K | 2230562 |  | CRG0805 SMT chip resistor,10K 0.125W
R10 | 1 | CRG0805F10K |  | RES0805_CRG_TYCO-L | Tyco Electronics Uk | CRG0805F10K | 2230562 |  | CRG0805 SMT chip resistor,10K 0.125W
R11 | 1 | CRG0805F22R |  | RES0805_CRG_TYCO-L | Tyco Electronics Uk | CRG0805F22R | 2230203 |  | CRG0805 SMT chip resistor,22R 0.125W
R12 | 1 | CRG0805F22R |  | RES0805_CRG_TYCO-L | Tyco Electronics Uk | CRG0805F22R | 2230203 |  | CRG0805 SMT chip resistor,22R 0.125W
R1 | 1 | CRG0805F220R |  | RES0805_CRG_TYCO-L | Tyco Electronics Uk | CRG0805F220R | 2230332 |  | CRG0805 SMT chip resistor,220R 0.125W
R2 | 1 | CRG0805F220R |  | RES0805_CRG_TYCO-L | Tyco Electronics Uk | CRG0805F220R | 2230332 |  | CRG0805 SMT chip resistor,220R 0.125W
R3 | 1 | CRG0805F220R |  | RES0805_CRG_TYCO-L | Tyco Electronics Uk | CRG0805F220R | 2230332 |  | CRG0805 SMT chip resistor,220R 0.125W
R4 | 1 | CRG0805F220R |  | RES0805_CRG_TYCO-L | Tyco Electronics Uk | CRG0805F220R | 2230332 |  | CRG0805 SMT chip resistor,220R 0.125W
R5 | 1 | CRG0805F220R |  | RES0805_CRG_TYCO-L | Tyco Electronics Uk | CRG0805F220R | 2230332 |  | CRG0805 SMT chip resistor,220R 0.125W
R6 | 1 | CRG0805F220R |  | RES0805_CRG_TYCO-L | Tyco Electronics Uk | CRG0805F220R | 2230332 |  | CRG0805 SMT chip resistor,220R 0.125W
R7 | 1 | CRG0805F220R |  | RES0805_CRG_TYCO-L | Tyco Electronics Uk | CRG0805F220R | 2230332 |  | CRG0805 SMT chip resistor,220R 0.125W
CCLIP1 | 1 | CrocClipConnector |  | USER
CCLIP2 | 1 | CrocClipConnector |  | USER
CCLIP3 | 1 | CrocClipConnector |  | USER
CCLIP4 | 1 | CrocClipConnector |  | USER
CCLIP5 | 1 | CrocClipConnector |  | USER
CCLIP6 | 1 | CrocClipConnector |  | USER
VCC | 1 | CrocClipConnector |  | USER
GND | 1 | CrocClipConnector |  | USER
XTAL1 | 1 | Crystal 16 MHz mini SMD |  | USER | QANTEK | QC5CB16.0000F18B23R | 8136116
U2 | 1 | FSM4JSMATR |  | SWITCH_FSM4JSMATR | Tyco Electronics Amp | FSM4JSMATR | 7182455 |  | Tactile switch,SMT,SPST,raised actuator
U3 | 1 | FSM4JSMATR |  | SWITCH_FSM4JSMATR | Tyco Electronics Amp | FSM4JSMATR | 7182455 |  | Tactile switch,SMT,SPST,raised actuator
U4 | 1 | FSM4JSMATR |  | SWITCH_FSM4JSMATR | Tyco Electronics Amp | FSM4JSMATR | 7182455 |  | Tactile switch,SMT,SPST,raised actuator
L1 | 1 | LNJ237W82RA |  | LED_LNJ | Panasonic | LNJ237W82RA | 7160522 |  | LED, Red, SMD, Top view
L2 | 1 | LNJ237W82RA |  | LED_LNJ | Panasonic | LNJ237W82RA | 7160522 |  | LED, Red, SMD, Top view
L3 | 1 | LNJ237W82RA |  | LED_LNJ | Panasonic | LNJ237W82RA | 7160522 |  | LED, Red, SMD, Top view
L4 | 1 | LNJ237W82RA |  | LED_LNJ | Panasonic | LNJ237W82RA | 7160522 |  | LED, Red, SMD, Top view
L5 | 1 | LNJ237W82RA |  | LED_LNJ | Panasonic | LNJ237W82RA | 7160522 |  | LED, Red, SMD, Top view
L6 | 1 | LNJ237W82RA |  | LED_LNJ | Panasonic | LNJ237W82RA | 7160522 |  | LED, Red, SMD, Top view
L7 | 1 | LNJ237W82RA |  | LED_LNJ | Panasonic | LNJ237W82RA | 7160522 |  | LED, Red, SMD, Top view
L8 | 1 | LNJ237W82RA |  | LED_LNJ | Panasonic | LNJ237W82RA | 7160522 |  | LED, Red, SMD, Top view
L9 | 1 | LNJ237W82RA |  | LED_LNJ | Panasonic | LNJ237W82RA | 7160522 |  | LED, Red, SMD, Top view
L10 | 1 | LNJ237W82RA |  | LED_LNJ | Panasonic | LNJ237W82RA | 7160522 |  | LED, Red, SMD, Top view
L11 | 1 | LNJ237W82RA |  | LED_LNJ | Panasonic | LNJ237W82RA | 7160522 |  | LED, Red, SMD, Top view
L12 | 1 | LNJ237W82RA |  | LED_LNJ | Panasonic | LNJ237W82RA | 7160522 |  | LED, Red, SMD, Top view
L13 | 1 | LNJ237W82RA |  | LED_LNJ | Panasonic | LNJ237W82RA | 7160522 |  | LED, Red, SMD, Top view
L14 | 1 | LNJ237W82RA |  | LED_LNJ | Panasonic | LNJ237W82RA | 7160522 |  | LED, Red, SMD, Top view
L15 | 1 | LNJ237W82RA |  | LED_LNJ | Panasonic | LNJ237W82RA | 7160522 |  | LED, Red, SMD, Top view
L16 | 1 | LNJ237W82RA |  | LED_LNJ | Panasonic | LNJ237W82RA | 7160522 |  | LED, Red, SMD, Top view
L17 | 1 | LNJ237W82RA |  | LED_LNJ | Panasonic | LNJ237W82RA | 7160522 |  | LED, Red, SMD, Top view
L18 | 1 | LNJ237W82RA |  | LED_LNJ | Panasonic | LNJ237W82RA | 7160522 |  | LED, Red, SMD, Top view
L19 | 1 | LNJ237W82RA |  | LED_LNJ | Panasonic | LNJ237W82RA | 7160522 |  | LED, Red, SMD, Top view
L20 | 1 | LNJ237W82RA |  | LED_LNJ | Panasonic | LNJ237W82RA | 7160522 |  | LED, Red, SMD, Top view
L21 | 1 | LNJ237W82RA |  | LED_LNJ | Panasonic | LNJ237W82RA | 7160522 |  | LED, Red, SMD, Top view
L22 | 1 | LNJ237W82RA |  | LED_LNJ | Panasonic | LNJ237W82RA | 7160522 |  | LED, Red, SMD, Top view
L23 | 1 | LNJ237W82RA |  | LED_LNJ | Panasonic | LNJ237W82RA | 7160522 |  | LED, Red, SMD, Top view
L24 | 1 | LNJ237W82RA |  | LED_LNJ | Panasonic | LNJ237W82RA | 7160522 |  | LED, Red, SMD, Top view
L25 | 1 | LNJ237W82RA |  | LED_LNJ | Panasonic | LNJ237W82RA | 7160522 |  | LED, Red, SMD, Top view
L26 | 1 | LNJ437W84RA |  | LED_LNJ | Panasonic | LNJ437W84RA | 7160534 |  | LED, Amber, SMD, Top view
L27 | 1 | LNJ437W84RA |  | LED_LNJ | Panasonic | LNJ437W84RA | 7160534 |  | LED, Amber, SMD, Top view
Switch1 | 1 | SlideSwitch |  | SlideSwitch_SPDT | C & K | OS102011MA1QN1 | 7874855

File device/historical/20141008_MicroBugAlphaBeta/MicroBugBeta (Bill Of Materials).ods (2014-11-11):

Report Written : Wednesday | October 08 | 2014 17:42
Design Path : C:\Users\michaels\Documents\MicroBugAlpha\MicroBugBeta.sch
Design Title :
Created :
Last Saved : 06/10/2014 15:28:19
Editing Time : 231 min
Units : thou (precision 2)
Bill of Materials generated with DesignSpark PCB - www.DesignSpark.com/pcb
--------------------------------------------------------------------------
Ref Name | Qty | Component | Value | Package | Manufacturer | MPN | RS Part Number | Other Part Number | Description
BH1 | 1 | 2032_BatteryHolder_SMT |  | USER | Keystone | 3003 | 2197960
C1 | 1 | 08051A220JAT2A | 22pF | CAP_C0G_0805-L | AVX | 08051A220JAT2A | 4646587
C2 | 1 | 08051A220JAT2A | 22pF | CAP_C0G_0805-L | AVX | 08051A220JAT2A | 4646587
MicroUSB | 1 | 1981568-1 |  | CONN_1981568-1 | Tyco Electronics Amp | 1981568-1 | 6694645 |  | Micro USB Receptacle type B
U1 | 1 | ATMEGA32U4-AU |  | 44ML-L | Atmel | ATMEGA32U4-AU | 7153805 |  | MCU AVR 32K FLASH 16MHZ 44-TQFP
C3 | 1 | C0805C105K4RACTU | 1uF | CAP_C0805-L | Kemet Electronics | C0805C105K4RACTU | 4515770
R8 | 1 | CRG0805F10K | 10K | RES0805_CRG_TYCO-L | Tyco Electronics Uk | CRG0805F10K | 2230562 |  | CRG0805 SMT chip resistor,10K 0.125W
R9 | 1 | CRG0805F10K | 10K | RES0805_CRG_TYCO-L | Tyco Electronics Uk | CRG0805F10K | 2230562 |  | CRG0805 SMT chip resistor,10K 0.125W
R10 | 1 | CRG0805F10K | 10K | RES0805_CRG_TYCO-L | Tyco Electronics Uk | CRG0805F10K | 2230562 |  | CRG0805 SMT chip resistor,10K 0.125W
R11 | 1 | CRG0805F22R | 22 | RES0805_CRG_TYCO-L | Tyco Electronics Uk | CRG0805F22R | 2230203 |  | CRG0805 SMT chip resistor,22R 0.125W
R12 | 1 | CRG0805F22R | 22 | RES0805_CRG_TYCO-L | Tyco Electronics Uk | CRG0805F22R | 2230203 |  | CRG0805 SMT chip resistor,22R 0.125W
R1 | 1 | CRG0805F220R | 220 | RES0805_CRG_TYCO-L | Tyco Electronics Uk | CRG0805F220R | 2230332 |  | CRG0805 SMT chip resistor,220R 0.125W
R2 | 1 | CRG0805F220R | 220 | RES0805_CRG_TYCO-L | Tyco Electronics Uk | CRG0805F220R | 2230332 |  | CRG0805 SMT chip resistor,220R 0.125W
R3 | 1 | CRG0805F220R | 220 | RES0805_CRG_TYCO-L | Tyco Electronics Uk | CRG0805F220R | 2230332 |  | CRG0805 SMT chip resistor,220R 0.125W
R4 | 1 | CRG0805F220R | 220 | RES0805_CRG_TYCO-L | Tyco Electronics Uk | CRG0805F220R | 2230332 |  | CRG0805 SMT chip resistor,220R 0.125W
R5 | 1 | CRG0805F220R | 220 | RES0805_CRG_TYCO-L | Tyco Electronics Uk | CRG0805F220R | 2230332 |  | CRG0805 SMT chip resistor,220R 0.125W
R6 | 1 | CRG0805F220R | 220 | RES0805_CRG_TYCO-L | Tyco Electronics Uk | CRG0805F220R | 2230332 |  | CRG0805 SMT chip resistor,220R 0.125W
R7 | 1 | CRG0805F220R | 220 | RES0805_CRG_TYCO-L | Tyco Electronics Uk | CRG0805F220R | 2230332 |  | CRG0805 SMT chip resistor,220R 0.125W
CCLIP1 | 1 | CrocClipConnector |  | USER
CCLIP2 | 1 | CrocClipConnector |  | USER
CCLIP3 | 1 | CrocClipConnector |  | USER
CCLIP4 | 1 | CrocClipConnector |  | USER
CCLIP5 | 1 | CrocClipConnector |  | USER
CCLIP6 | 1 | CrocClipConnector |  | USER
VCC | 1 | CrocClipConnector |  | USER
GND | 1 | CrocClipConnector |  | USER
XTAL1 | 1 | Crystal 16 MHz mini SMD | 16Mhz | USER | QANTEK | QC5CB16.0000F18B23R | 8136116
U2 | 1 | FSM4JSMATR |  | SWITCH_FSM4JSMATR | Tyco Electronics Amp | FSM4JSMATR | 7182455 |  | Tactile switch,SMT,SPST,raised actuator
U3 | 1 | FSM4JSMATR |  | SWITCH_FSM4JSMATR | Tyco Electronics Amp | FSM4JSMATR | 7182455 |  | Tactile switch,SMT,SPST,raised actuator
U4 | 1 | FSM4JSMATR |  | SWITCH_FSM4JSMATR | Tyco Electronics Amp | FSM4JSMATR | 7182455 |  | Tactile switch,SMT,SPST,raised actuator
L1 | 1 | LNJ237W82RA | RED | LED_LNJ | Panasonic | LNJ237W82RA | 7160522 |  | LED, Red, SMD, Top view
L2 | 1 | LNJ237W82RA | RED | LED_LNJ | Panasonic | LNJ237W82RA | 7160522 |  | LED, Red, SMD, Top view
L3 | 1 | LNJ237W82RA | RED | LED_LNJ | Panasonic | LNJ237W82RA | 7160522 |  | LED, Red, SMD, Top view
L4 | 1 | LNJ237W82RA | RED | LED_LNJ | Panasonic | LNJ237W82RA | 7160522 |  | LED, Red, SMD, Top view
L5 | 1 | LNJ237W82RA | RED | LED_LNJ | Panasonic | LNJ237W82RA | 7160522 |  | LED, Red, SMD, Top view
L6 | 1 | LNJ237W82RA | RED | LED_LNJ | Panasonic | LNJ237W82RA | 7160522 |  | LED, Red, SMD, Top view
L7 | 1 | LNJ237W82RA | RED | LED_LNJ | Panasonic | LNJ237W82RA | 7160522 |  | LED, Red, SMD, Top view
L8 | 1 | LNJ237W82RA | RED | LED_LNJ | Panasonic | LNJ237W82RA | 7160522 |  | LED, Red, SMD, Top view
L9 | 1 | LNJ237W82RA | RED | LED_LNJ | Panasonic | LNJ237W82RA | 7160522 |  | LED, Red, SMD, Top view
L10 | 1 | LNJ237W82RA | RED | LED_LNJ | Panasonic | LNJ237W82RA | 7160522 |  | LED, Red, SMD, Top view
L11 | 1 | LNJ237W82RA | RED | LED_LNJ | Panasonic | LNJ237W82RA | 7160522 |  | LED, Red, SMD, Top view
L12 | 1 | LNJ237W82RA | RED | LED_LNJ | Panasonic | LNJ237W82RA | 7160522 |  | LED, Red, SMD, Top view
L13 | 1 | LNJ237W82RA | RED | LED_LNJ | Panasonic | LNJ237W82RA | 7160522 |  | LED, Red, SMD, Top view
L14 | 1 | LNJ237W82RA | RED | LED_LNJ | Panasonic | LNJ237W82RA | 7160522 |  | LED, Red, SMD, Top view
L15 | 1 | LNJ237W82RA | RED | LED_LNJ | Panasonic | LNJ237W82RA | 7160522 |  | LED, Red, SMD, Top view
L16 | 1 | LNJ237W82RA | RED | LED_LNJ | Panasonic | LNJ237W82RA | 7160522 |  | LED, Red, SMD, Top view
L17 | 1 | LNJ237W82RA | RED | LED_LNJ | Panasonic | LNJ237W82RA | 7160522 |  | LED, Red, SMD, Top view
L18 | 1 | LNJ237W82RA | RED | LED_LNJ | Panasonic | LNJ237W82RA | 7160522 |  | LED, Red, SMD, Top view
L19 | 1 | LNJ237W82RA | RED | LED_LNJ | Panasonic | LNJ237W82RA | 7160522 |  | LED, Red, SMD, Top view
L20 | 1 | LNJ237W82RA | RED | LED_LNJ | Panasonic | LNJ237W82RA | 7160522 |  | LED, Red, SMD, Top view
L21 | 1 | LNJ237W82RA | RED | LED_LNJ | Panasonic | LNJ237W82RA | 7160522 |  | LED, Red, SMD, Top view
L22 | 1 | LNJ237W82RA | RED | LED_LNJ | Panasonic | LNJ237W82RA | 7160522 |  | LED, Red, SMD, Top view
L23 | 1 | LNJ237W82RA | RED | LED_LNJ | Panasonic | LNJ237W82RA | 7160522 |  | LED, Red, SMD, Top view
L24 | 1 | LNJ237W82RA | RED | LED_LNJ | Panasonic | LNJ237W82RA | 7160522 |  | LED, Red, SMD, Top view
L25 | 1 | LNJ237W82RA | RED | LED_LNJ | Panasonic | LNJ237W82RA | 7160522 |  | LED, Red, SMD, Top view
L26 | 1 | LNJ437W84RA | AMBER | LED_LNJ | Panasonic | LNJ437W84RA | 7160534 |  | LED, Amber, SMD, Top view
L27 | 1 | LNJ437W84RA | AMBER | LED_LNJ | Panasonic | LNJ437W84RA | 7160534 |  | LED, Amber, SMD, Top view
Switch1 | 1 | SlideSwitch |  | SlideSwitch_SPDT | C & K | OS102011MA1QN1 | 7874855

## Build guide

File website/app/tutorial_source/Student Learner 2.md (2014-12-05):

!Page:_tutorial_toolbox_1

# Beginner

-----------

## Turning LEDs on and off

!Page:_tutorial_toolbox_1

### Before you get started

Before you start coding there are three simple concepts you need to understand.

### How do I tell the difference betweens the LEDs

All of the LEDs look the same, but there is a simple way to tell them apart using X and Y co-ordinates.

Your X axis runs along the bottom of the grid, as shown on the diagram here.  The Y axis runs up the side.

The first row on X and and column on Y is 0.  The next is 1 and so on.

**TODO: Images live here**
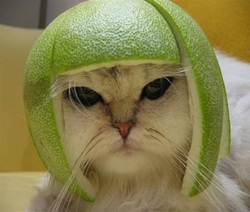
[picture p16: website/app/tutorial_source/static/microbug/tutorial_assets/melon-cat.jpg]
Melon Cat


So if we want to identify this LED here *(Diagram 2)* we count 3 rows along the X axis and 5 up the Y axis.  (Meaning this LEDs name is X2 Y4).

Each of the LED state blocks has a space where you can enter the X and Y numbers you need.

### How does an LED know to turn on or off?

Binary code consists entirely of 1s and 0s.  If you want a light to come on, you'll need to enter 1.  If you want it to be off you need to enter 0.

OFF = 0
ON = 1

!Page:_tutorial_toolbox_1
### What does the code actually look like?

The technical name for the code you will be working with is JavaScript.  Which looks like this:

    <!DOCTTYPE html>
    <html>
    <body>

    <script>
    document.getElementById('demo').innerHTML = '123e5';
    </script>

But to help make things a bit easier we've created visual building blocks that you can arrange in the workspace.  By simply dragging and dropping different blocks and attacking them to each other in sequence, you can assemble your code a lot more quickly.

They'll give exactly the same instructions to Micro Bug, you just need to change the numbes on each block to get the results you want.

And when you've finished a creation, you can see what it looks like as JavaScript by pressing the JavaScript button at the top of the workspace.

----

### *Task 1:* Turning the LED on

Let's get an LED on the Micro Bug to light up.  This is also called 'setting the LED state'.

* **a** To do this go to the LED menu and select a *set LED state block*.

**TODO: Image lives here **

* **b** Because both X and Y are set to 0, this command will go straight to the LED at the bottom left of your grid.

* **c** By setting the state to 1 we are turning it ON (Remember 0 = OFF and 1 = On)

* **d** If you click the play button now you should see that the LED on the bottom left lights up.

** TODO: Image lives here **

* **e** If you have time, try changing one of the X or Y numbers to make a different LED light up.  If you do, change it back to 0 again before starting task 2.

!Page:_tutorial_toolbox_1

### *Task 2:* Turning the LED off again

To turn the LED OFF again we'll need to add an instruction.

* **a** First of all we need a *pause for time (ms)* block.  Select one from the Basic menu, then place this underneath the *set LED state* block you already have.

* **b** Pause blocks count everything in milliseconds to give you lots of control for sophisticated coding later on.  For now, just remember 1000ms = 1 second.

* **c** To change your LED state to OFF we'll need to select another *set LED state* block and drag this underneath the *pause for time (ms)* block.

* **d** We're instructing the light we just turned on, so the X and Y numbers should be exactly the same as they are in the first block.  The only thing we need to change is the state.  OFF=0 so set that number *to 0*, as we've done below.

** TODO: Image lives here **

* **e** If you click the play button now you should see that the LED on the bottom left:
    * Lights up
    * Pauses for 1 second
    * And then turns off

** TODO: Image lives here **

Done it?  Great!  Let's try turning multiple LEDs on at the same time.

!Page:_tutorial_toolbox_1

### *Task3:* Turning the LED off again

* **a** If we want to turn on lots of LEDs simultaneously we will need lots of *LED state blocks*

* **b** Using exactly the same kind of instructions as task 2 we can create a leter T.

* **c** To do this we need to turn on a row of 4 LEDs at the top, and a column of 4 LEDs in the middle.  So we'll need 8 *LED state* blocks.

* **d** Using the X and Y counting system you learned earlier, identify each LED that you need and set the state to 1 (just like we've done below)

* **e** You'll need a *pause for time (ms)* block at the end too.

** TODO: Image lives here **

!Page:_tutorial_toolbox_1

### *Task 4*: Create your own initials

If your first initial starts with a T then this will be a little easy, so pick another letter.

* **a** First, use a pencil to colour in the LEDs on a Micro Bug worksheet, to decide the best way to show your initial.  For instance an L will be very like a T, except you need your X row at the bottom and your Y column on the left.

* **b** Once you are ready select the appropriate number of *LED state* blocks, then enter the X and Y numbers and set all of their states to 1 (ON).

* **c** Now add a *pause for time(ms)* block and see how it looks by pressing PLAY

* **d** Done?  Then try adding your second initial to the code too.

----

### *TOP TIP:* Try changing the speed

You can adjust the speed that your instructions play as they light up using the SPEED SLIDER.  This will show the program running through your sequence of instructions one at a time, to help you check that everything is working the way you want it to.

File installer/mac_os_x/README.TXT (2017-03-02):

HOW TO BUILD BBCBUG.DMG
==========================

Set up your build environment, as detailed below.

Run makedmg.sh

That's it.

BUILD ENVIRONMENT
=================

Install PySide 1.2.1 binaries and Qt 4.8 for Mac

	Brew installs may work for you, but I had trouble with directory permissions, and ultimately installed DMGs from here:

	http://qt-project.org/wiki/PySide_Binaries_MacOSX#99905e544954e0e23f71eec9df2c02e9

Install Py2app

	You will need to sudo this if your Python install is a system installation
	
	pip install -U py2app

Make sure you have the version of libusb that dfu-programmer expects

	http://sourceforge.net/projects/libusb/postdownload?source=dlp

	You're looking for libusb-compat-0.1.4

Install dylibbundler

	Dylibbundler is used to add libusb into the application bundle

	https://github.com/auriamg/macdylibbundler/

Install appdmg
	
	https://github.com/LinusU/node-appdmg (requires node install http://nodejs.org/)

LICENSE
=======

#
# Copyright 2016 British Broadcasting Corporation and Contributors(1)
#
# (1) Contributors are listed in the AUTHORS file (please extend AUTHORS,
#     not this header)
#
# Licensed under the Apache License, Version 2.0 (the "License"); you may
# not use this file except in compliance this license (or the alternative
# license below).
# You may obtain a copy of the License at
#
#     http://www.apache.org/licenses/LICENSE-2.0
#
# This file is also alternatively licensed under the terms of the GPL
# version 2. You may obtain a copy of the license at:
#
#     http://www.gnu.org/licenses/old-licenses/gpl-2.0.txt
#
# Unless required by applicable law or agreed to in writing, software
# distributed under the License is distributed on an "AS IS" BASIS,
# WITHOUT WARRANTIES OR CONDITIONS OF ANY KIND, either express or implied.
# See the License for the specific language governing permissions and
# limitations under the License.
#

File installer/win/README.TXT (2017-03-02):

To build the Windows BBC Bug Loader
===================================

	Install Python for Windows (Version used: Python 2.7)

	Install PySide Binaries for Windows  (http://qt-project.org/wiki/PySide_Binaries_Windows)

	Install PY2EXE (http://www.py2exe.org) - ensure you install corresponding version, i.e. for Python 2.7

	Run /installer/win/PY2EXE/make.bat - further details can be found in /installer/win/PY2EXE/README.TXT

To build the Windows Microbug Installer 
=======================================

**Requires basic knowledge of Inno Installer and tinkering skills**

	Install Inno Installer (I used 2.1.0.20)

	Modify \installer\win\InnoSetupScript.iss to point to your clone of the BBCBug .git repo. There are five lines starting with C:\Users\Matthew\ that will need changing accordingly.

	Compile the modified InnoSetupScript to produce the installer.

LICENSE:
=======
#
# Copyright 2016 British Broadcasting Corporation and Contributors(1)
#
# (1) Contributors are listed in the AUTHORS file (please extend AUTHORS,
#     not this header)
#
# Licensed under the Apache License, Version 2.0 (the "License"); you may
# not use this file except in compliance this license (or the alternative
# license below).
# You may obtain a copy of the License at
#
#     http://www.apache.org/licenses/LICENSE-2.0
#
# This file is also alternatively licensed under the terms of the GPL
# version 2. You may obtain a copy of the license at:
#
#     http://www.gnu.org/licenses/old-licenses/gpl-2.0.txt
#
# Unless required by applicable law or agreed to in writing, software
# distributed under the License is distributed on an "AS IS" BASIS,
# WITHOUT WARRANTIES OR CONDITIONS OF ANY KIND, either express or implied.
# See the License for the specific language governing permissions and
# limitations under the License.
#

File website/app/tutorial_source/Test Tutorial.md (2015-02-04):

!Page:_tutorial_toolbox_1
Normal content

# Header 1

## Header 2

> Quoted text.

This is **content** for **page 1**.

Melon Cat

* One
* Two
* Three (**nifty**)

Press this button to load some code..

!LoadCode:"&lt;xml xmlns=&quot;http://www.w3.org/1999/xhtml&quot;&gt;&lt;block type=&quot;microbug_forever&quot; id=&quot;7&quot; x=&quot;93&quot; y=&quot;18&quot;&gt;&lt;statement name=&quot;NAME&quot;&gt;&lt;block type=&quot;microbug_print_message&quot; id=&quot;12&quot; inline=&quot;false&quot;&gt;&lt;value name=&quot;message&quot;&gt;&lt;block type=&quot;text&quot; id=&quot;22&quot;&gt;&lt;field name=&quot;TEXT&quot;&gt;Good morning universe&lt;/field&gt;&lt;/block&gt;&lt;/value&gt;&lt;value name=&quot;pausetime&quot;&gt;&lt;block type=&quot;math_number&quot; id=&quot;19&quot;&gt;&lt;field name=&quot;NUM&quot;&gt;200&lt;/field&gt;&lt;/block&gt;&lt;/value&gt;&lt;/block&gt;&lt;/statement&gt;&lt;/block&gt;&lt;/xml&gt;"

Press this button to load some other code..

!LoadCode:"&lt;xml xmlns=&quot;http://www.w3.org/1999/xhtml&quot;&gt;&lt;block type=&quot;microbug_eye_on&quot; id=&quot;6&quot; inline=&quot;true&quot; x=&quot;121&quot; y=&quot;59&quot;&gt;&lt;value name=&quot;id&quot;&gt;&lt;block type=&quot;text&quot; id=&quot;34&quot;&gt;&lt;field name=&quot;TEXT&quot;&gt;L&lt;/field&gt;&lt;/block&gt;&lt;/value&gt;&lt;next&gt;&lt;block type=&quot;microbug_eye_on&quot; id=&quot;12&quot; inline=&quot;true&quot;&gt;&lt;value name=&quot;id&quot;&gt;&lt;block type=&quot;text&quot; id=&quot;37&quot;&gt;&lt;field name=&quot;TEXT&quot;&gt;R&lt;/field&gt;&lt;/block&gt;&lt;/value&gt;&lt;next&gt;&lt;block type=&quot;microbug_pause&quot; id=&quot;31&quot; inline=&quot;true&quot;&gt;&lt;value name=&quot;pause&quot;&gt;&lt;block type=&quot;math_number&quot; id=&quot;40&quot;&gt;&lt;field name=&quot;NUM&quot;&gt;200&lt;/field&gt;&lt;/block&gt;&lt;/value&gt;&lt;next&gt;&lt;block type=&quot;microbug_eye_off&quot; id=&quot;20&quot; inline=&quot;true&quot;&gt;&lt;value name=&quot;id&quot;&gt;&lt;block type=&quot;text&quot; id=&quot;47&quot;&gt;&lt;field name=&quot;TEXT&quot;&gt;L&lt;/field&gt;&lt;/block&gt;&lt;/value&gt;&lt;next&gt;&lt;block type=&quot;microbug_eye_off&quot; id=&quot;26&quot; inline=&quot;true&quot;&gt;&lt;value name=&quot;id&quot;&gt;&lt;block type=&quot;text&quot; id=&quot;50&quot;&gt;&lt;field name=&quot;TEXT&quot;&gt;R&lt;/field&gt;&lt;/block&gt;&lt;/value&gt;&lt;/block&gt;&lt;/next&gt;&lt;/block&gt;&lt;/next&gt;&lt;/block&gt;&lt;/next&gt;&lt;/block&gt;&lt;/next&gt;&lt;/block&gt;&lt;/xml&gt"

!Page:_tutorial_toolbox_2
# Page 2

This is **content** for **page 2**.

!Page:_tutorial_toolbox_3
# Page 3

This is **content** for **page 3**.

!Page:_tutorial_toolbox_4
# Page 4

This is **content** for **page 4**.

!Page:_tutorial_toolbox_4
# Page 5

This is **content** for **page 5**.

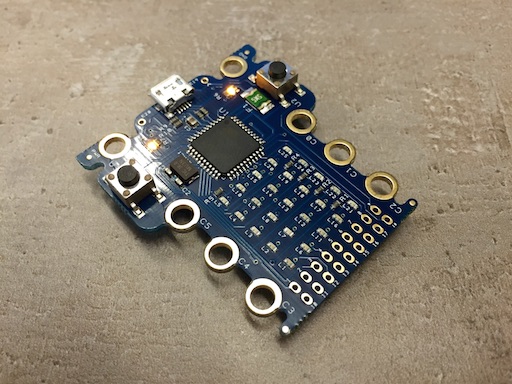
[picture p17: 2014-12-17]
installer/mac_os_x/bbcbug.jpg

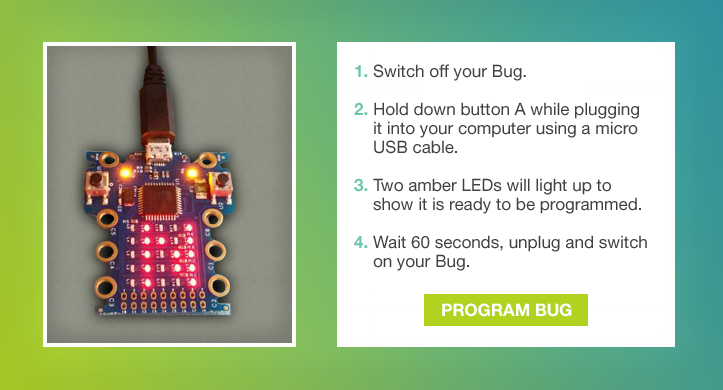
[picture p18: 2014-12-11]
installer/mac_os_x/Instructions1.png

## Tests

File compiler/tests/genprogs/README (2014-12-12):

This is where compiled test programs go when built

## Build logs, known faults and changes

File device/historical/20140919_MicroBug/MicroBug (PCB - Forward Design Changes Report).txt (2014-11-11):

Forward Design Changes Report
-----------------------------

Report File    : C:\Users\michaels\Documents\MicroBug\MicroBug (PCB - Forward Design Changes Report).txt
Report Written : Friday, September 19, 2014
Project Path   : C:\Users\michaels\Documents\MicroBug\MicroBug.prj
Design Path    : C:\Users\michaels\Documents\MicroBug\MicroBug.pcb
Design Title   : 
Created        : 18/09/2014 23:45:43
Last Saved     : 19/09/2014 01:41:26
Editing Time   : 114 min
Units          : thou (precision 0)

Connected pin "LED4-1" to net "N0013".

End Of Report.

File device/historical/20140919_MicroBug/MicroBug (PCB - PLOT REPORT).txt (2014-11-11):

PLOT REPORT
-----------

Report File    : C:\Users\michaels\Documents\MicroBug\MicroBug (PCB - PLOT REPORT).txt
Report Written : Friday, September 19, 2014
Project Path   : C:\Users\michaels\Documents\MicroBug\MicroBug.prj
Design Path    : C:\Users\michaels\Documents\MicroBug\MicroBug.pcb
Design Title   : 
Created        : 18/09/2014 23:45:43
Last Saved     : 19/09/2014 01:56:42
Editing Time   : 155 min
Units          : thou (precision 0)

Device Settings
===============

Gerber Settings
===============

    Leading zero suppression.
    G01 assumed throughout.
    Line termination <*> <CR> <LF>.
    2.3 format absolute inches.

    Format commands defined in Gerber file.
    Aperture table defined in Gerber file.
    Hardware arcs allowed.

Drill Settings
==============

    Excellon Format 1    Format 2.3 absolute in mm.
    No zero suppression.

PDF Settings
============

Combine Plots Yes

Use Bookmarks Yes

Component Details Yes

Symbol Details Yes

Link Net Names Yes

View PDF Yes

All Colours Black Yes

Plots Output
============

    Plot Job: "C:\Users\michaels\Documents\MicroBug\MicroBug.mop"

PDF Output
==========

    Layer
    --------------
    Bottom Copper
    Top Copper
    Top Silkscreen

Gerber Output
=============

C:\Users\michaels\Documents\MicroBug\MicroBug - Top Copper.gbr

    Layers:
    ------------
    Top Copper

    D-Code  Shape  (thou)
    --------------------------------------------
    D10     Rectangle 14.00 X 46.00  Rotation 90
    D11     Rectangle 14.00 X 46.00
    D12     Rectangle 60.00 X 80.00  Rotation 90
    D13     Round 15.00
    D71     Round 48.00

Gerber Output
=============

C:\Users\michaels\Documents\MicroBug\MicroBug - Top Copper (Resist).gbr

    Layers:
    ------------
    Top Copper

    D-Code  Shape  (thou)
    --------------------------------------------
    D14     Rectangle 24.00 X 56.00  Rotation 90
    D15     Rectangle 24.00 X 56.00
    D16     Rectangle 70.00 X 90.00  Rotation 90

Gerber Output
=============

C:\Users\michaels\Documents\MicroBug\MicroBug - Top Copper (Paste).gbr

    Layers:
    ------------
    Top Copper

    D-Code  Shape  (thou)
    --------------------------------------------
    D17     Rectangle 10.00 X 42.00  Rotation 90
    D18     Rectangle 10.00 X 42.00

Gerber Output
=============

C:\Users\michaels\Documents\MicroBug\MicroBug - Bottom Copper (Resist).gbr

    Layers:
    ---------------
    Bottom Copper

    D-Code  Shape  (thou)
    --------------------------------------------
    D16     Rectangle 70.00 X 90.00  Rotation 90

Gerber Output
=============

C:\Users\michaels\Documents\MicroBug\MicroBug - Bottom Copper (Paste).gbr

    Layers:
    ---------------
    Bottom Copper

    D-Code  Shape  (thou)
    ---------------------

NC Drill Output
===============

C:\Users\michaels\Documents\MicroBug\MicroBug - Drill Data - Through Hole.drl

    Output:
    --------------------------
    Plated Round Drill Holes
    Plated Slots
    Plated Board Outlines

    Tool   Size       Count    ID
    -----------------------------
    T001   00.024 in  38     B
    T002   00.030 in  50     A
    -----------------------------
    Total             88
    -----------------------------
    Tool   Size       Count    ID
    -----------------------------
    T001   00.025 in  1
    -----------------------------
    Total             1
    -----------------------------

Gerber Output
=============

C:\Users\michaels\Documents\MicroBug\MicroBug - Drill Ident Drawing - Through Hole.gbr

    Layers:
    ----------------
    [Through Hole]

Drill Ident Drawing
===================

    Drill  Plated  Size  Shape  ID
    ------------------------------
    30     Y       100   Round  A
    24     Y       100   Round  B

    D-Code  Shape  (thou)
    ---------------------
    D19     Round 100.00
    D70     Round 5.00

End Of Report.

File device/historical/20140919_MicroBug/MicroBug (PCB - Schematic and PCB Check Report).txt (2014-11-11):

Schematic and PCB Check Report
------------------------------

Report File    : C:\Users\michaels\Documents\MicroBug\MicroBug (PCB - Schematic and PCB Check Report).txt
Report Written : Friday, September 19, 2014
Project Path   : C:\Users\michaels\Documents\MicroBug\MicroBug.prj
Design Path    : C:\Users\michaels\Documents\MicroBug\MicroBug.pcb
Design Title   : 
Created        : 18/09/2014 23:45:43
Last Saved     : 19/09/2014 01:44:16
Editing Time   : 116 min
Units          : thou (precision 0)

Checking integrity of Schematic "C:\Users\michaels\Documents\MicroBug\MicroBug.sch" with PCB "C:\Users\michaels\Documents\MicroBug\MicroBug.pcb"
================================================================================================================================================

The designs are the same.

End Of Report.

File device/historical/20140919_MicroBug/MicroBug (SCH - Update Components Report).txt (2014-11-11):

Update Components Report
------------------------

Report File    : C:\Users\michaels\Documents\MicroBug\MicroBug (SCH - Update Components Report).txt
Report Written : Friday, September 19, 2014
Project Path   : C:\Users\michaels\Documents\MicroBug\MicroBug.prj
Design Path    : C:\Users\michaels\Documents\MicroBug\MicroBug.sch
Design Title   : 
Created        : 
Last Saved     : 18/09/2014 21:33:53
Editing Time   : 226 min
Units          : thou (precision 2)

Library Files:
==============

C:\Users\Public\Documents\DesignSpark PCB 6.1\Library\DownloadedLibrary\Semiconductors-Processors & Microcontrollers-Microcontrollers.cml
C:\Users\Public\Documents\DesignSpark PCB 6.1\Library\User\User.cml
C:\Users\Public\Documents\DesignSpark PCB 6.1\Library\Default\DesignSpark.cml
C:\Users\Public\Documents\DesignSpark PCB 6.1\Library\Default\ltspice.cml
C:\Users\Public\Documents\DesignSpark PCB 6.1\Library\Default\XSpice.cml

Selected items to be updated:
=============================

Components:
===========

    (None) 

Symbols:
========

    (None) 

Additional items to be updated:
===============================

Components:
===========

    (None) 

Symbols:
========

    (None) 

Selected items not to be updated  (Same version as library)
===========================================================

Components:
===========

LED  C:\Users\Public\Documents\DesignSpark PCB 6.1\Library\Default\DesignSpark.cml

Symbols:
========

LED  C:\Users\Public\Documents\DesignSpark PCB 6.1\Library\Default\DesignSpark.ssl

Update Components Summary
=========================

Updating single component.
Update component values
Update component value positions

	Selected for update:			   1  Component 
						   1  Symbol 

	Selected items to be updated:		   0  Components
						   0  Symbols

	Additional items to be updated:		   0  Components
						   0  Symbols

	Selected items NOT to be updated:	   1  Component 
	  (Same version as library)		   1  Symbol 

End Of Report.

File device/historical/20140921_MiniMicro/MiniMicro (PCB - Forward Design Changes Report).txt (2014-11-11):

Forward Design Changes Report
-----------------------------

Report File    : C:\Users\michaels\Documents\MiniMicro\MiniMicro (PCB - Forward Design Changes Report).txt
Report Written : Sunday, September 21, 2014
Design Path    : C:\Users\michaels\Documents\MiniMicro\MiniMicro.pcb
Design Title   : 
Created        : 19/09/2014 13:37:57
Last Saved     : 21/09/2014 02:11:59
Editing Time   : 1869 min
Units          : thou (precision 1)

Connected pin "U1-10" to net "N0097".

End Of Report.

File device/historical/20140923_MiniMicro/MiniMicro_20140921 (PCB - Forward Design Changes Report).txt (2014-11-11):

Forward Design Changes Report
-----------------------------

Report File    : C:\Users\michaels\Documents\MiniMicro_20140921\MiniMicro_20140921 (PCB - Forward Design Changes Report).txt
Report Written : Tuesday, September 23, 2014
Project Path   : C:\Users\michaels\Documents\MiniMicro_20140921\MiniMicro_20140921.prj
Design Path    : C:\Users\michaels\Documents\MiniMicro_20140921\MiniMicro_20140921.pcb
Design Title   : 
Created        : 21/09/2014 12:47:43
Last Saved     : 22/09/2014 12:53:18
Editing Time   : 673 min
Units          : thou (precision 0)

Added value "description=16MhzCrystal" to component reference "XTAL2".

End Of Report.

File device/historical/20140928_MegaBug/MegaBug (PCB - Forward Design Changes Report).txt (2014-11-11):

Forward Design Changes Report
-----------------------------

Report File    : C:\Users\michaels\Documents\MegaBug\MegaBug (PCB - Forward Design Changes Report).txt
Report Written : Sunday, September 28, 2014
Design Path    : C:\Users\michaels\Documents\MegaBug\MegaBug.pcb
Design Title   : 
Created        : 28/09/2014 11:23:08
Last Saved     : 28/09/2014 12:09:30
Editing Time   : 49 min
Units          : thou (precision 0)

Renamed component reference "RESET" to "RESET".

Renamed component reference "B" to "B".

Renamed component reference "A" to "A".

Net "VCC" changed from net class "Power" to net class "Signal".

End Of Report.

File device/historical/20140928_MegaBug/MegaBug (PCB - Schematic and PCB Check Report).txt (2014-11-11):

Schematic and PCB Check Report
------------------------------

Report File    : C:\Users\michaels\Documents\MegaBug\MegaBug (PCB - Schematic and PCB Check Report).txt
Report Written : Sunday, September 28, 2014
Design Path    : C:\Users\michaels\Documents\MegaBug\MegaBug.pcb
Design Title   : 
Created        : 28/09/2014 11:23:08
Last Saved     : 28/09/2014 13:15:40
Editing Time   : 114 min
Units          : thou (precision 0)

Checking integrity of Schematic "C:\Users\michaels\Documents\MegaBug\MegaBug.sch" with PCB "C:\Users\michaels\Documents\MegaBug\MegaBug.pcb"
============================================================================================================================================

The designs are the same.

End Of Report.

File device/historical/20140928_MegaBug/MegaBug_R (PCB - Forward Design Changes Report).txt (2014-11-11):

Forward Design Changes Report
-----------------------------

Report File    : C:\Users\michaels\Documents\MegaBug\MegaBug_R (PCB - Forward Design Changes Report).txt
Report Written : Sunday, September 28, 2014
Design Path    : C:\Users\michaels\Documents\MegaBug\MegaBug_R.pcb
Design Title   : 
Created        : 28/09/2014 11:23:08
Last Saved     : 28/09/2014 22:08:05
Editing Time   : 644 min
Units          : thou (precision 0)

Connected pin "LED22-1" to net "N0073".

End Of Report.

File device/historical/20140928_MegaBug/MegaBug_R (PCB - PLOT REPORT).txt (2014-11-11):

PLOT REPORT
-----------

Report File    : C:\Users\michaels\Documents\MegaBug\MegaBug_R (PCB - PLOT REPORT).txt
Report Written : Monday, September 29, 2014
Design Path    : C:\Users\michaels\Documents\MegaBug\MegaBug_R.pcb
Design Title   : 
Created        : 28/09/2014 11:23:08
Last Saved     : 29/09/2014 01:03:06
Editing Time   : 824 min
Units          : thou (precision 0)

Device Settings
===============

PDF Settings
============

Combine Plots Yes

Use Bookmarks Yes

Component Details Yes

Symbol Details Yes

Link Net Names Yes

View PDF Yes

All Colours Black Yes

Plots Output
============

    Plot Job: "C:\Users\michaels\Documents\MegaBug\MegaBug_R.mop"

PDF Output
==========

    Layer
    -------------
    Bottom Copper

End Of Report.

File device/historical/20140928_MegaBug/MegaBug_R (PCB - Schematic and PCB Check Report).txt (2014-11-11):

Schematic and PCB Check Report
------------------------------

Report File    : C:\Users\michaels\Documents\MegaBug\MegaBug_R (PCB - Schematic and PCB Check Report).txt
Report Written : Monday, September 29, 2014
Design Path    : C:\Users\michaels\Documents\MegaBug\MegaBug_R.pcb
Design Title   : 
Created        : 28/09/2014 11:23:08
Last Saved     : 29/09/2014 01:03:06
Editing Time   : 2141 min
Units          : thou (precision 0)

Checking integrity of Schematic "C:\Users\michaels\Documents\MegaBug\MegaBug_R.sch" with PCB "C:\Users\michaels\Documents\MegaBug\MegaBug_R.pcb"
================================================================================================================================================

The designs are the same.

End Of Report.

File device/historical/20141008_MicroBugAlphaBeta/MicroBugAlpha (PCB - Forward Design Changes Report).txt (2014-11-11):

Forward Design Changes Report
-----------------------------

Report File    : C:\Users\michaels\Documents\MicroBugAlpha\MicroBugAlpha (PCB - Forward Design Changes Report).txt
Report Written : Monday, October 06, 2014
Design Path    : C:\Users\michaels\Documents\MicroBugAlpha\MicroBugAlpha.pcb
Design Title   : 
Created        : 05/10/2014 22:26:50
Last Saved     : 06/10/2014 02:48:54
Editing Time   : 262 min
Units          : thou (precision 0)

Connected pin "Switch1-1" to net "VCC".

End Of Report.

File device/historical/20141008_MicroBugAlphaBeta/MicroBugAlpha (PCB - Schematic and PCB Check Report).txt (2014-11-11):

Schematic and PCB Check Report
------------------------------

Report File    : C:\Users\michaels\Documents\MicroBugAlpha\MicroBugAlpha (PCB - Schematic and PCB Check Report).txt
Report Written : Monday, October 06, 2014
Design Path    : C:\Users\michaels\Documents\MicroBugAlpha\MicroBugAlpha.pcb
Design Title   : 
Created        : 05/10/2014 22:26:50
Last Saved     : 06/10/2014 02:48:54
Editing Time   : 265 min
Units          : thou (precision 0)

Checking integrity of Schematic "C:\Users\michaels\Documents\MicroBugAlpha\MicroBugAlpha.sch" with PCB "C:\Users\michaels\Documents\MicroBugAlpha\MicroBugAlpha.pcb"
====================================================================================================================================================================

The designs are the same.

End Of Report.

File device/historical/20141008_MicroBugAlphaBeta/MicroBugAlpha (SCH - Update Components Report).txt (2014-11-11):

Update Components Report
------------------------

Report File    : C:\Users\michaels\Documents\MicroBugAlpha\MicroBugAlpha (SCH - Update Components Report).txt
Report Written : Sunday, October 05, 2014
Design Path    : C:\Users\michaels\Documents\MicroBugAlpha\MicroBugAlpha.sch
Design Title   : 
Created        : 
Last Saved     : 05/10/2014 19:00:42
Editing Time   : 84 min
Units          : thou (precision 2)

Library Files:
==============

C:\Users\Public\Documents\DesignSpark PCB 6.1\Library\User\User.cml
C:\Users\Public\Documents\DesignSpark PCB 6.1\Library\DownloadedLibrary\Batteries-Battery Chargers & Battery Accessories-Battery Holders & Mounts.cml
C:\Users\Public\Documents\DesignSpark PCB 6.1\Library\DownloadedLibrary\Connectors-USB, D-sub & Computing Connectors-Micro USB Connectors.cml
C:\Users\Public\Documents\DesignSpark PCB 6.1\Library\DownloadedLibrary\Displays & Optoelectronics-LEDs & LED Accessories-Visible LEDs.cml
C:\Users\Public\Documents\DesignSpark PCB 6.1\Library\DownloadedLibrary\Passive Components-Capacitors-Aluminium Capacitors.cml
C:\Users\Public\Documents\DesignSpark PCB 6.1\Library\DownloadedLibrary\Passive Components-Capacitors-Ceramic Multilayer Capacitors.cml
C:\Users\Public\Documents\DesignSpark PCB 6.1\Library\DownloadedLibrary\Passive Components-Capacitors-Ceramic Single Layer Capacitors.cml
C:\Users\Public\Documents\DesignSpark PCB 6.1\Library\DownloadedLibrary\Passive Components-Fixed Resistors-Surface Mount Fixed Resistors.cml
C:\Users\Public\Documents\DesignSpark PCB 6.1\Library\DownloadedLibrary\Passive Components-Fixed Resistors-Through Hole Fixed Resistors.cml
C:\Users\Public\Documents\DesignSpark PCB 6.1\Library\DownloadedLibrary\Semiconductors-Crystals, Oscillators & Resonators-Ceramic Resonators.cml
C:\Users\Public\Documents\DesignSpark PCB 6.1\Library\DownloadedLibrary\Semiconductors-Crystals, Oscillators & Resonators-Crystal Units.cml
C:\Users\Public\Documents\DesignSpark PCB 6.1\Library\DownloadedLibrary\Semiconductors-Processors & Microcontrollers-Microcontrollers.cml
C:\Users\Public\Documents\DesignSpark PCB 6.1\Library\DownloadedLibrary\Switches-Tactile Switches & Accessories-Tactile Switches.cml
C:\Users\Public\Documents\DesignSpark PCB 6.1\Library\Default\DesignSpark.cml
C:\Users\Public\Documents\DesignSpark PCB 6.1\Library\Default\ltspice.cml
C:\Users\Public\Documents\DesignSpark PCB 6.1\Library\Default\XSpice.cml
C:\Users\Public\Documents\DesignSpark PCB 6.1\Library\3m.cml
C:\Users\Public\Documents\DesignSpark PCB 6.1\Library\74hc.cml
C:\Users\Public\Documents\DesignSpark PCB 6.1\Library\74hct.cml
C:\Users\Public\Documents\DesignSpark PCB 6.1\Library\74ls.cml
C:\Users\Public\Documents\DesignSpark PCB 6.1\Library\4000.cml
C:\Users\Public\Documents\DesignSpark PCB 6.1\Library\actel.cml
C:\Users\Public\Documents\DesignSpark PCB 6.1\Library\ad.cml
C:\Users\Public\Documents\DesignSpark PCB 6.1\Library\adsp.cml
C:\Users\Public\Documents\DesignSpark PCB 6.1\Library\altera.cml
C:\Users\Public\Documents\DesignSpark PCB 6.1\Library\alteracyclone.cml
C:\Users\Public\Documents\DesignSpark PCB 6.1\Library\amp.cml
C:\Users\Public\Documents\DesignSpark PCB 6.1\Library\atmel.cml
C:\Users\Public\Documents\DesignSpark PCB 6.1\Library\atmel8051.cml
C:\Users\Public\Documents\DesignSpark PCB 6.1\Library\atmelarm.cml
C:\Users\Public\Documents\DesignSpark PCB 6.1\Library\atmelatsam7.cml
C:\Users\Public\Documents\DesignSpark PCB 6.1\Library\atmelavr.cml
C:\Users\Public\Documents\DesignSpark PCB 6.1\Library\avx.cml
C:\Users\Public\Documents\DesignSpark PCB 6.1\Library\capacitor.cml
C:\Users\Public\Documents\DesignSpark PCB 6.1\Library\coldfire.cml
C:\Users\Public\Documents\DesignSpark PCB 6.1\Library\connector.cml
C:\Users\Public\Documents\DesignSpark PCB 6.1\Library\csm.cml
C:\Users\Public\Documents\DesignSpark PCB 6.1\Library\cypress.cml
C:\Users\Public\Documents\DesignSpark PCB 6.1\Library\diode.cml
C:\Users\Public\Documents\DesignSpark PCB 6.1\Library\discrete.cml
C:\Users\Public\Documents\DesignSpark PCB 6.1\Library\dsm.cml
C:\Users\Public\Documents\DesignSpark PCB 6.1\Library\fairchild.cml
C:\Users\Public\Documents\DesignSpark PCB 6.1\Library\fairchild1.cml
C:\Users\Public\Documents\DesignSpark PCB 6.1\Library\fairchildacex.cml
C:\Users\Public\Documents\DesignSpark PCB 6.1\Library\fci.cml
C:\Users\Public\Documents\DesignSpark PCB 6.1\Library\fuse.cml
C:\Users\Public\Documents\DesignSpark PCB 6.1\Library\hamlin.cml
C:\Users\Public\Documents\DesignSpark PCB 6.1\Library\hybrid.cml
C:\Users\Public\Documents\DesignSpark PCB 6.1\Library\infineontc116x.cml
C:\Users\Public\Documents\DesignSpark PCB 6.1\Library\intel8051.cml
C:\Users\Public\Documents\DesignSpark PCB 6.1\Library\ir.cml
C:\Users\Public\Documents\DesignSpark PCB 6.1\Library\lattice.cml
C:\Users\Public\Documents\DesignSpark PCB 6.1\Library\lt.cml
C:\Users\Public\Documents\DesignSpark PCB 6.1\Library\ltspice.cml
C:\Users\Public\Documents\DesignSpark PCB 6.1\Library\luminarycortex.cml
C:\Users\Public\Documents\DesignSpark PCB 6.1\Library\maxim.cml
C:\Users\Public\Documents\DesignSpark PCB 6.1\Library\maxim8051.cml
C:\Users\Public\Documents\DesignSpark PCB 6.1\Library\maximmp.cml
C:\Users\Public\Documents\DesignSpark PCB 6.1\Library\mc68hc.cml
C:\Users\Public\Documents\DesignSpark PCB 6.1\Library\microchip.cml
C:\Users\Public\Documents\DesignSpark PCB 6.1\Library\microchippic.cml
C:\Users\Public\Documents\DesignSpark PCB 6.1\Library\molex.cml
C:\Users\Public\Documents\DesignSpark PCB 6.1\Library\msp430.cml
C:\Users\Public\Documents\DesignSpark PCB 6.1\Library\murata.cml
C:\Users\Public\Documents\DesignSpark PCB 6.1\Library\natsemi.cml
C:\Users\Public\Documents\DesignSpark PCB 6.1\Library\nxp-lpc32x0.cml
C:\Users\Public\Documents\DesignSpark PCB 6.1\Library\omron.cml
C:\Users\Public\Documents\DesignSpark PCB 6.1\Library\onsemi.cml
C:\Users\Public\Documents\DesignSpark PCB 6.1\Library\opamps.cml
C:\Users\Public\Documents\DesignSpark PCB 6.1\Library\pcb.cml
C:\Users\Public\Documents\DesignSpark PCB 6.1\Library\philips80c51.cml
C:\Users\Public\Documents\DesignSpark PCB 6.1\Library\philipsarm.cml
C:\Users\Public\Documents\DesignSpark PCB 6.1\Library\philipsp89.cml
C:\Users\Public\Documents\DesignSpark PCB 6.1\Library\philipsxa.cml
C:\Users\Public\Documents\DesignSpark PCB 6.1\Library\picaxe.cml
C:\Users\Public\Documents\DesignSpark PCB 6.1\Library\powerpc.cml
C:\Users\Public\Documents\DesignSpark PCB 6.1\Library\qbsm.cml
C:\Users\Public\Documents\DesignSpark PCB 6.1\Library\qcsm.cml
C:\Users\Public\Documents\DesignSpark PCB 6.1\Library\qsm.cml
C:\Users\Public\Documents\DesignSpark PCB 6.1\Library\quicklogic.cml
C:\Users\Public\Documents\DesignSpark PCB 6.1\Library\relay.cml
C:\Users\Public\Documents\DesignSpark PCB 6.1\Library\renesasr8c.cml
C:\Users\Public\Documents\DesignSpark PCB 6.1\Library\resistor.cml
C:\Users\Public\Documents\DesignSpark PCB 6.1\Library\rfmicro.cml
C:\Users\Public\Documents\DesignSpark PCB 6.1\Library\schema.cml
C:\Users\Public\Documents\DesignSpark PCB 6.1\Library\sm.cml
C:\Users\Public\Documents\DesignSpark PCB 6.1\Library\sonycx.cml
C:\Users\Public\Documents\DesignSpark PCB 6.1\Library\st-arm7.cml
C:\Users\Public\Documents\DesignSpark PCB 6.1\Library\st.cml
C:\Users\Public\Documents\DesignSpark PCB 6.1\Library\testpoint.cml
C:\Users\Public\Documents\DesignSpark PCB 6.1\Library\ti.cml
C:\Users\Public\Documents\DesignSpark PCB 6.1\Library\tms320.cml
C:\Users\Public\Documents\DesignSpark PCB 6.1\Library\tms470.cml
C:\Users\Public\Documents\DesignSpark PCB 6.1\Library\toshibatmp86.cml
C:\Users\Public\Documents\DesignSpark PCB 6.1\Library\trans.cml
C:\Users\Public\Documents\DesignSpark PCB 6.1\Library\transistor.cml
C:\Users\Public\Documents\DesignSpark PCB 6.1\Library\vishay.cml
C:\Users\Public\Documents\DesignSpark PCB 6.1\Library\xilinx.cml
C:\Users\Public\Documents\DesignSpark PCB 6.1\Library\zilog.cml

Selected items to be updated:
=============================

Components:
===========

    (None) 

Symbols:
========

    (None) 

Additional items to be updated:
===============================

Components:
===========

    (None) 

Symbols:
========

    (None) 

Selected items not to be updated  (Same version as library)
===========================================================

Components:
===========

LNJ237W82RA  C:\Users\Public\Documents\DesignSpark PCB 6.1\Library\DownloadedLibrary\Displays & Optoelectronics-LEDs & LED Accessories-Visible LEDs.cml

Symbols:
========

LED  C:\Users\Public\Documents\DesignSpark PCB 6.1\Library\DownloadedLibrary\Displays & Optoelectronics-LEDs & LED Accessories-Visible LEDs.ssl

Update Components Summary
=========================

Updating single component.
Update component values
Update component value positions

	Selected for update:			   1  Component 
						   1  Symbol 

	Selected items to be updated:		   0  Components
						   0  Symbols

	Additional items to be updated:		   0  Components
						   0  Symbols

	Selected items NOT to be updated:	   1  Component 
	  (Same version as library)		   1  Symbol 

End Of Report.

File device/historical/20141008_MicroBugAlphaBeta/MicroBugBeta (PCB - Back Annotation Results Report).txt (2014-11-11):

Back Annotation Results Report
------------------------------

Report File    : C:\Users\michaels\Documents\MicroBugAlpha\MicroBugBeta (PCB - Back Annotation Results Report).txt
Report Written : Monday, October 06, 2014
Design Path    : C:\Users\michaels\Documents\MicroBugAlpha\MicroBugBeta.pcb
Design Title   : 
Created        : 06/10/2014 12:11:33
Last Saved     : 06/10/2014 15:25:19
Editing Time   : 196 min
Units          : thou (precision 0)

Back Annotate renames from PCB "C:\Users\michaels\Documents\MicroBugAlpha\MicroBugBeta.pcb" to Schematic "C:\Users\michaels\Documents\MicroBugAlpha\MicroBugBeta.sch".

Change Value on Component 'CCLIP6' - 'AnalogPin'.
Change Value on Component 'CCLIP5' - 'AnalogPin'.
Change Value on Component 'CCLIP4' - 'AnalogPin'.
Change Value on Component 'CCLIP1' - 'AnalogPin'.
Change Value on Component 'CCLIP2' - 'AnalogPin'.
Change Value on Component 'CCLIP3' - 'AnalogPin'.

End Of Report.

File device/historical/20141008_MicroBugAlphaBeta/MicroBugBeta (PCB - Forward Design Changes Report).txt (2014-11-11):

Forward Design Changes Report
-----------------------------

Report File    : C:\Users\michaels\Documents\MicroBugAlpha\MicroBugBeta (PCB - Forward Design Changes Report).txt
Report Written : Monday, October 06, 2014
Design Path    : C:\Users\michaels\Documents\MicroBugAlpha\MicroBugBeta.pcb
Design Title   : 
Created        : 06/10/2014 12:11:33
Last Saved     : 06/10/2014 15:28:05
Editing Time   : 196 min
Units          : thou (precision 0)

Connected pin "R6-1" to net "GND".

End Of Report.

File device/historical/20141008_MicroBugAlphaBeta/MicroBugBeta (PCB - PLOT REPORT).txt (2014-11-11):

PLOT REPORT
-----------

Report File    : C:\Users\michaels\Documents\MicroBugAlpha\MicroBugBeta (PCB - PLOT REPORT).txt
Report Written : Wednesday, October 08, 2014
Design Path    : C:\Users\michaels\Documents\MicroBugAlpha\MicroBugBeta.pcb
Design Title   : 
Created        : 06/10/2014 12:11:33
Last Saved     : 08/10/2014 12:51:58
Editing Time   : 280 min
Units          : thou (precision 0)

Device Settings
===============

Gerber Settings
===============

    Leading zero suppression.
    G01 assumed throughout.
    Line termination <*> <CR> <LF>.
    2.3 format absolute inches.

    Format commands defined in Gerber file.
    Aperture table defined in Gerber file.
    Hardware arcs allowed.

Drill Settings
==============

    Excellon Format 1    Format 2.3 absolute in inches.
    No zero suppression.

Plots Output
============

    Plot Job: "C:\Users\michaels\Documents\MicroBugAlpha\MicroBugBeta.mop"

Gerber Output
=============

C:\Users\michaels\Documents\MicroBugAlpha\MicroBugBeta - Top Documentation.gbr

    Layers:
    -------------------
    Top Documentation
    Board Outlines

    D-Code  Shape  (thou)
    ---------------------
    D14     Round 5.00

Gerber Output
=============

C:\Users\michaels\Documents\MicroBugAlpha\MicroBugBeta - Top Silkscreen.gbr

    Layers:
    ----------------
    Top Silkscreen
    Board Outlines

    D-Code  Shape  (thou)
    ---------------------
    D14     Round 5.00
    D19     Round 6.00
    D70     Round 2.00
    D71     Round 3.00
    D20     Round 1.00

Gerber Output
=============

C:\Users\michaels\Documents\MicroBugAlpha\MicroBugBeta - Top Copper.gbr

    Layers:
    ------------
    Top Copper

    D-Code  Shape  (thou)
    ---------------------------------------------
    D21     Rectangle 17.52 X 37.40  Rotation 135
    D22     Rectangle 30.00 X 55.00
    D23     Rectangle 14.00 X 46.00  Rotation 90
    D24     Rectangle 14.00 X 46.00
    D25     Rectangle 55.00 X 83.00  Rotation 90
    D26     Rectangle 18.00 X 55.00  Rotation 90
    D27     Rectangle 55.00 X 63.00  Rotation 90
    D28     Rectangle 53.00 X 57.00
    D29     Rectangle 17.52 X 37.40
    D72     Rectangle 30.00 X 55.00  Rotation 90
    D73     Square 78.74
    D74     Rectangle 36.00 X 57.00
    D75     Rectangle 36.00 X 57.00  Rotation 90
    D76     Round 236.22
    D77     Round 62.99
    D78     Round 78.74
    D79     Round 56.00
    D80     Round 10.00
    D81     Round 48.00

Gerber Output
=============

C:\Users\michaels\Documents\MicroBugAlpha\MicroBugBeta - Top Copper (Resist).gbr

    Layers:
    ------------
    Top Copper

    D-Code  Shape  (thou)
    ---------------------------------------------
    D82     Rectangle 27.52 X 47.40  Rotation 135
    D83     Rectangle 40.00 X 65.00
    D84     Rectangle 24.00 X 56.00  Rotation 90
    D85     Rectangle 24.00 X 56.00
    D86     Rectangle 65.00 X 93.00  Rotation 90
    D87     Rectangle 28.00 X 65.00  Rotation 90
    D88     Rectangle 65.00 X 73.00  Rotation 90
    D89     Rectangle 63.00 X 67.00
    D90     Rectangle 27.52 X 47.40
    D91     Rectangle 40.00 X 65.00  Rotation 90
    D92     Square 88.74
    D93     Rectangle 46.00 X 67.00
    D94     Rectangle 46.00 X 67.00  Rotation 90
    D95     Round 246.22
    D96     Round 72.99
    D97     Round 88.74

Gerber Output
=============

C:\Users\michaels\Documents\MicroBugAlpha\MicroBugBeta - Top Copper (Paste).gbr

    Layers:
    ------------
    Top Copper

    D-Code  Shape  (thou)
    ---------------------------------------------
    D98     Rectangle 13.52 X 33.40  Rotation 135
    D99     Rectangle 26.00 X 51.00
    D100    Rectangle 10.00 X 42.00  Rotation 90
    D101    Rectangle 10.00 X 42.00
    D102    Rectangle 51.00 X 79.00  Rotation 90
    D103    Rectangle 14.00 X 51.00  Rotation 90
    D104    Rectangle 51.00 X 59.00  Rotation 90
    D105    Rectangle 49.00 X 53.00
    D106    Rectangle 13.52 X 33.40
    D107    Rectangle 26.00 X 51.00  Rotation 90
    D108    Square 74.74
    D109    Rectangle 32.00 X 53.00
    D110    Rectangle 32.00 X 53.00  Rotation 90

Gerber Output
=============

C:\Users\michaels\Documents\MicroBugAlpha\MicroBugBeta - Bottom Copper.gbr

    Layers:
    ---------------
    Bottom Copper

    D-Code  Shape  (thou)
    ---------------------------------
    D76     Round 236.22
    D77     Round 62.99
    D78     Round 78.74
    D79     Round 56.00
    D80     Round 10.00
    D81     Round 48.00
    D111    Rectangle 400.00 X 400.00
    D112    Rectangle 200.00 X 200.00
    D113    Rectangle 196.85 X 196.85

Gerber Output
=============

C:\Users\michaels\Documents\MicroBugAlpha\MicroBugBeta - Bottom Copper (Resist).gbr

    Layers:
    ---------------
    Bottom Copper

    D-Code  Shape  (thou)
    ---------------------------------
    D95     Round 246.22
    D96     Round 72.99
    D97     Round 88.74
    D114    Rectangle 410.00 X 410.00
    D115    Rectangle 210.00 X 210.00
    D116    Rectangle 206.85 X 206.85

Gerber Output
=============

C:\Users\michaels\Documents\MicroBugAlpha\MicroBugBeta - Bottom Copper (Paste).gbr

    Layers:
    ---------------
    Bottom Copper

    D-Code  Shape  (thou)
    ---------------------------------
    D117    Rectangle 396.00 X 396.00
    D118    Rectangle 196.00 X 196.00
    D119    Rectangle 192.85 X 192.85

Gerber Output
=============

C:\Users\michaels\Documents\MicroBugAlpha\MicroBugBeta - Bottom Silkscreen.gbr

    Layers:
    -------------------
    Bottom Silkscreen
    Board Outlines

    D-Code  Shape  (thou)
    ---------------------
    D14     Round 5.00

Gerber Output
=============

C:\Users\michaels\Documents\MicroBugAlpha\MicroBugBeta - Bottom Documentation.gbr

    Layers:
    ----------------------
    Bottom Documentation

    D-Code  Shape  (thou)
    ---------------------
    D14     Round 5.00

NC Drill Output
===============

C:\Users\michaels\Documents\MicroBugAlpha\MicroBugBeta - Drill Data - Through Hole.drl

    Output:
    --------------------------
    Plated Round Drill Holes
    Plated Slots
    Plated Board Outlines

    Tool   Size       Count    ID
    -----------------------------
    T001   00.024 in  34     B
    T002   00.031 in  3      G
    T003   00.032 in  12     C
    T004   00.057 in  1      H
    T005   00.059 in  1      I
    T006   00.157 in  8      K
    -----------------------------
    Total             59
    -----------------------------
    Tool   Size       Count    ID
    -----------------------------
    T001   00.025 in  1
    -----------------------------
    Total             1
    -----------------------------

Gerber Output
=============

C:\Users\michaels\Documents\MicroBugAlpha\MicroBugBeta - Drill Ident Drawing - Through Hole.gbr

    Layers:
    ----------------
    [Through Hole]

Drill Ident Drawing
===================

    Drill  Plated  Size  Shape  ID
    ------------------------------
    24     Y       100   Round  B
    32     Y       100   Round  C
    31     Y       100   Round  G
    57     Y       100   Round  H
    59     Y       100   Round  I
    157    Y       100   Round  K

    D-Code  Shape  (thou)
    ---------------------
    D13     Round 100.00
    D14     Round 5.00

End Of Report.

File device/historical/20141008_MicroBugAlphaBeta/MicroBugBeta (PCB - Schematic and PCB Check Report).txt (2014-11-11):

Schematic and PCB Check Report
------------------------------

Report File    : C:\Users\michaels\Documents\MicroBugAlpha\MicroBugBeta (PCB - Schematic and PCB Check Report).txt
Report Written : Wednesday, October 08, 2014
Design Path    : C:\Users\michaels\Documents\MicroBugAlpha\MicroBugBeta.pcb
Design Title   : 
Created        : 06/10/2014 12:11:33
Last Saved     : 08/10/2014 12:31:13
Editing Time   : 276 min
Units          : thou (precision 0)

Checking integrity of Schematic "C:\Users\michaels\Documents\MicroBugAlpha\MicroBugBeta.sch" with PCB "C:\Users\michaels\Documents\MicroBugAlpha\MicroBugBeta.pcb"
==================================================================================================================================================================

The PCB and Schematic designs do not match.
To bring them into line, you will need to make the following changes to the PCB design:

Component 'LNJ237W82RA' package 'LED_LNJ' in PCB is newer version than Schematic, use Update Component to correct this.

End Of Report.

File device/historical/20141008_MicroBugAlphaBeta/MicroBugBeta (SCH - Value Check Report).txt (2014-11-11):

Value Check Report
------------------

Report File    : C:\Users\michaels\Documents\MicroBugAlpha\MicroBugBeta (SCH - Value Check Report).txt
Report Written : Wednesday, October 08, 2014
Design Path    : C:\Users\michaels\Documents\MicroBugAlpha\MicroBugBeta.sch
Design Title   : 
Created        : 
Last Saved     : 06/10/2014 15:28:19
Editing Time   : 230 min
Units          : thou (precision 2)

Errors Found
============

Capacitor C1 value not found
Capacitor C2 value not found
Capacitor C3 value not found
Inductor L1 value not found
Inductor L2 value not found
Inductor L3 value not found
Inductor L4 value not found
Inductor L5 value not found
Inductor L6 value not found
Inductor L7 value not found
Inductor L8 value not found
Inductor L9 value not found
Inductor L10 value not found
Inductor L11 value not found
Inductor L12 value not found
Inductor L13 value not found
Inductor L14 value not found
Inductor L15 value not found
Inductor L16 value not found
Inductor L17 value not found
Inductor L18 value not found
Inductor L19 value not found
Inductor L20 value not found
Inductor L21 value not found
Inductor L22 value not found
Inductor L23 value not found
Inductor L24 value not found
Inductor L25 value not found
Inductor L26 value not found
Inductor L27 value not found
Resistor R1 value not found
Resistor R2 value not found
Resistor R3 value not found
Resistor R4 value not found
Resistor R5 value not found
Resistor R6 value not found
Resistor R7 value not found
Resistor R8 value not found
Resistor R9 value not found
Resistor R10 value not found
Resistor R11 value not found
Resistor R12 value not found

End Of Report.

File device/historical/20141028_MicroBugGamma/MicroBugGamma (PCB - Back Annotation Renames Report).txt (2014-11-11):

Back Annotation Renames Report
------------------------------

Report File    : C:\Users\michaels\Documents\MicroBugGamma\MicroBugGamma (PCB - Back Annotation Renames Report).txt
Report Written : Tuesday, October 28, 2014
Project Path   : C:\Users\michaels\Documents\MicroBugGamma\MicroBugGamma.prj
Design Path    : C:\Users\michaels\Documents\MicroBugGamma\MicroBugGamma.pcb
Design Title   : 
Created        : 26/10/2014 01:28:37
Last Saved     : 28/10/2014 20:26:16
Editing Time   : 3445 min
Units          : thou (precision 0)

Outstanding PCB renames awaiting back annotation to the Schematics design.

Rename Component from "VCC" to "PWR".
Rename Net from "LED_ANODES_4" to "PIN20_RX".
Rename Net from "PIN18" to "LED_ANODES_2".
Rename Net from "LED_ANODES_2" to "PIN18".

End Of Report.

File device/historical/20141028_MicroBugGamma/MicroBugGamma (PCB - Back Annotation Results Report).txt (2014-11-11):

Back Annotation Results Report
------------------------------

Report File    : C:\Users\michaels\Documents\MicroBugGamma\MicroBugGamma (PCB - Back Annotation Results Report).txt
Report Written : Tuesday, October 28, 2014
Project Path   : C:\Users\michaels\Documents\MicroBugGamma\MicroBugGamma.prj
Design Path    : C:\Users\michaels\Documents\MicroBugGamma\MicroBugGamma.pcb
Design Title   : 
Created        : 26/10/2014 01:28:37
Last Saved     : 28/10/2014 20:26:16
Editing Time   : 3445 min
Units          : thou (precision 0)

Back Annotate renames from the PCB design to all Schematic designs in project "MicroBugGamma".

Error: Could not find  Component " VCC".
Renamed Net from "LED_ANODES_4" to "PIN20_RX" in design "MicroBugGamma.sch".
Renamed Net from "LED_ANODES_4" to "PIN20_RX" in design "MicroBugGamma.sch".
Renamed Net from "PIN18" to "LED_ANODES_2" in design "MicroBugGamma.sch".
Renamed Net from "PIN18" to "LED_ANODES_2" in design "MicroBugGamma.sch".
Renamed Net from "LED_ANODES_2" to "PIN18" in design "MicroBugGamma.sch".
Renamed Net from "LED_ANODES_2" to "PIN18" in design "MicroBugGamma.sch".
Renamed Schematic Net from "PIN20_RX" to "PIN21" in design "MicroBugGamma.sch".

End Of Report.

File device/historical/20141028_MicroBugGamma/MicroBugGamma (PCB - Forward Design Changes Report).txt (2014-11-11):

Forward Design Changes Report
-----------------------------

Report File    : C:\Users\michaels\Documents\MicroBugGamma\MicroBugGamma (PCB - Forward Design Changes Report).txt
Report Written : Tuesday, October 28, 2014
Project Path   : C:\Users\michaels\Documents\MicroBugGamma\MicroBugGamma.prj
Design Path    : C:\Users\michaels\Documents\MicroBugGamma\MicroBugGamma.pcb
Design Title   : 
Created        : 26/10/2014 01:28:37
Last Saved     : 28/10/2014 20:53:41
Editing Time   : 3446 min
Units          : thou (precision 0)

Disconnected pin "L2-2" from net "LED_ANODES_2".
Disconnected pin "L7-2" from net "LED_ANODES_2".
Disconnected pin "L12-2" from net "LED_ANODES_2".
Disconnected pin "L17-2" from net "LED_ANODES_2".
Disconnected pin "L22-2" from net "LED_ANODES_2".
Disconnected pin "R2-1" from net "LED_ANODES_2".
Disconnected pin "R2-2" from net "PIN18".
Disconnected pin "R4-2" from net "PIN20_RX".
Disconnected pin "U1-18" from net "PIN18".
Disconnected pin "U1-20" from net "PIN20_RX".
Disconnected pin "BH1-1" from net "N0068".
Disconnected pin "SW1-1" from net "VCC".
Disconnected pin "SW1-2" from net "N0068".

Deleted component reference "SW1".

Deleted net "N0068".

Added net "PIN21".
Added net "N0070".

Added component reference "SW2" of component "SlideSwitch_SPDT_SMT2", package "USER".

Connected pin "L2-2" to net "PIN18".
Connected pin "L7-2" to net "PIN18".
Connected pin "L12-2" to net "PIN18".
Connected pin "L17-2" to net "PIN18".
Connected pin "L22-2" to net "PIN18".
Connected pin "R2-2" to net "LED_ANODES_2".
Connected pin "R2-1" to net "PIN18".
Connected pin "R4-2" to net "PIN21".
Connected pin "U1-18" to net "LED_ANODES_2".
Connected pin "U1-20" to net "PIN21".
Connected pin "BH1-1" to net "N0070".
Connected pin "SW2-2" to net "N0070".
Connected pin "SW2-1" to net "VCC".

Net LED_ANODES_4 renamed to PIN20_RX

End Of Report.

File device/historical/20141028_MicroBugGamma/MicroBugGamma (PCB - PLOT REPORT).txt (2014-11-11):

PLOT REPORT
-----------

Report File    : C:\Users\michaels\Documents\MicroBugGamma\MicroBugGamma (PCB - PLOT REPORT).txt
Report Written : Tuesday, October 28, 2014
Project Path   : C:\Users\michaels\Documents\MicroBugGamma\MicroBugGamma.prj
Design Path    : C:\Users\michaels\Documents\MicroBugGamma\MicroBugGamma.pcb
Design Title   : 
Created        : 26/10/2014 01:28:37
Last Saved     : 28/10/2014 21:12:55
Editing Time   : 3464 min
Units          : mm (precision 1)

Device Settings
===============

Gerber Settings
===============

    Leading zero suppression.
    G01 assumed throughout.
    Line termination <*> <CR> <LF>.
    2.3 format absolute inches.

    Format commands defined in Gerber file.
    Aperture table defined in Gerber file.
    Hardware arcs allowed.

Drill Settings
==============

    Excellon Format 1    Format 2.3 absolute in inches.
    No zero suppression.

Plots Output
============

    Plot Job: "C:\Users\michaels\Documents\MicroBugGamma\MicroBugGamma.mop"

Gerber Output
=============

C:\Users\michaels\Documents\MicroBugGamma\MicroBugGamma - Top Documentation.gbr

    Layers:
    -------------------
    Top Documentation
    Board Outlines

    D-Code  Shape  (thou)
    ---------------------
    D21     Round 5.00

Gerber Output
=============

C:\Users\michaels\Documents\MicroBugGamma\MicroBugGamma - Top Silkscreen.gbr

    Layers:
    ----------------
    Top Silkscreen

    D-Code  Shape  (thou)
    ---------------------
    D21     Round 5.00
    D23     Round 3.00
    D24     Round 1.00
    D25     Round 6.00
    D26     Round 2.00

Gerber Output
=============

C:\Users\michaels\Documents\MicroBugGamma\MicroBugGamma - Top Copper.gbr

    Layers:
    ----------------
    Top Copper
    Board Outlines

    D-Code  Shape  (thou)
    ---------------------------------------------
    D21     Round 5.00
    D27     Round 60.00
    D28     Rectangle 17.52 X 37.40  Rotation 90
    D29     Rectangle 30.00 X 55.00  Rotation 90
    D72     Rectangle 14.00 X 46.00  Rotation 45
    D73     Rectangle 14.00 X 46.00  Rotation 135
    D74     Rectangle 55.00 X 83.00
    D75     Rectangle 18.00 X 55.00
    D76     Rectangle 55.00 X 63.00
    D77     Rectangle 53.00 X 57.00  Rotation 90
    D78     Rectangle 30.00 X 55.00  Rotation 135
    D79     Rectangle 36.00 X 57.00  Rotation 90
    D80     Rectangle 36.00 X 57.00
    D81     Round 236.22
    D82     Square 78.74
    D83     Rectangle 17.52 X 37.40
    D84     Round 32.00
    D85     Oval 50.00 X 80.00
    D86     Round 10.00
    D87     Round 8.00
    D115    Round 40.00

Gerber Output
=============

C:\Users\michaels\Documents\MicroBugGamma\MicroBugGamma - Top Copper (Resist).gbr

    Layers:
    ------------
    Top Copper

    D-Code  Shape  (thou)
    ---------------------------------------------
    D10     Round 246.22
    D88     Round 70.00
    D89     Rectangle 27.52 X 47.40  Rotation 90
    D90     Rectangle 40.00 X 65.00  Rotation 90
    D91     Rectangle 24.00 X 56.00  Rotation 45
    D92     Rectangle 24.00 X 56.00  Rotation 135
    D93     Rectangle 65.00 X 93.00
    D94     Rectangle 28.00 X 65.00
    D95     Rectangle 65.00 X 73.00
    D96     Rectangle 63.00 X 67.00  Rotation 90
    D97     Rectangle 40.00 X 65.00  Rotation 135
    D98     Rectangle 46.00 X 67.00  Rotation 90
    D99     Rectangle 46.00 X 67.00
    D100    Square 88.74
    D101    Rectangle 27.52 X 47.40
    D116    Round 50.00

Gerber Output
=============

C:\Users\michaels\Documents\MicroBugGamma\MicroBugGamma - Top Copper (Paste).gbr

    Layers:
    ------------
    Top Copper

    D-Code  Shape  (thou)
    ---------------------------------------------
    D102    Rectangle 13.52 X 33.40  Rotation 90
    D103    Rectangle 26.00 X 51.00  Rotation 90
    D104    Rectangle 10.00 X 42.00  Rotation 45
    D105    Rectangle 10.00 X 42.00  Rotation 135
    D106    Rectangle 51.00 X 79.00
    D107    Rectangle 14.00 X 51.00
    D108    Rectangle 51.00 X 59.00
    D109    Rectangle 49.00 X 53.00  Rotation 90
    D110    Rectangle 26.00 X 51.00  Rotation 135
    D111    Rectangle 32.00 X 53.00  Rotation 90
    D112    Rectangle 32.00 X 53.00
    D113    Square 74.74
    D114    Rectangle 13.52 X 33.40

Gerber Output
=============

C:\Users\michaels\Documents\MicroBugGamma\MicroBugGamma - Bottom Copper.gbr

    Layers:
    ----------------
    Bottom Copper
    Board Outlines

    D-Code  Shape  (thou)
    ----------------------------------------------
    D21     Round 5.00
    D27     Round 60.00
    D81     Round 236.22
    D84     Round 32.00
    D85     Oval 50.00 X 80.00
    D86     Round 10.00
    D87     Round 8.00
    D115    Round 40.00
    D117    Rectangle 47.00 X 99.00  Rotation 90
    D150    Rectangle 400.00 X 400.00  Rotation 90
    D151    Rectangle 200.00 X 200.00  Rotation 90
    D152    Rectangle 196.85 X 196.85  Rotation 90

Gerber Output
=============

C:\Users\michaels\Documents\MicroBugGamma\MicroBugGamma - Bottom Copper (Resist).gbr

    Layers:
    ---------------
    Bottom Copper

    D-Code  Shape  (thou)
    ----------------------------------------------
    D10     Round 246.22
    D11     Rectangle 410.00 X 410.00  Rotation 90
    D12     Rectangle 210.00 X 210.00  Rotation 90
    D13     Rectangle 206.85 X 206.85  Rotation 90
    D88     Round 70.00
    D116    Round 50.00
    D118    Rectangle 57.00 X 109.00  Rotation 90

Gerber Output
=============

C:\Users\michaels\Documents\MicroBugGamma\MicroBugGamma - Bottom Copper (Paste).gbr

    Layers:
    ---------------
    Bottom Copper

    D-Code  Shape  (thou)
    ----------------------------------------------
    D17     Rectangle 396.00 X 396.00  Rotation 90
    D18     Rectangle 196.00 X 196.00  Rotation 90
    D19     Rectangle 192.85 X 192.85  Rotation 90
    D119    Rectangle 43.00 X 95.00  Rotation 90

Gerber Output
=============

C:\Users\michaels\Documents\MicroBugGamma\MicroBugGamma - Bottom Silkscreen.gbr

    Layers:
    -------------------
    Bottom Silkscreen

    D-Code  Shape  (thou)
    ---------------------
    D21     Round 5.00
    D24     Round 1.00

Gerber Output
=============

C:\Users\michaels\Documents\MicroBugGamma\MicroBugGamma - Bottom Documentation.gbr

    Layers:
    ----------------------
    Bottom Documentation
    Board Outlines

    D-Code  Shape  (thou)
    ---------------------
    D21     Round 5.00

NC Drill Output
===============

C:\Users\michaels\Documents\MicroBugGamma\MicroBugGamma - Drill Data - Through Hole.drl

    Output:
    --------------------------
    Plated Round Drill Holes
    Plated Slots
    Plated Board Outlines

    Tool   Size       Count    ID
    -----------------------------
    T001   00.016 in  92     M
    T002   00.035 in  23     D
    T003   00.157 in  8      K
    -----------------------------
    Total             123
    -----------------------------
    Tool   Size       Count    ID
    -----------------------------
    T001   00.025 in  1
    -----------------------------
    Total             1
    -----------------------------

Gerber Output
=============

C:\Users\michaels\Documents\MicroBugGamma\MicroBugGamma - Drill Ident Drawing - Through Hole.gbr

    Layers:
    ----------------
    [Through Hole]

Drill Ident Drawing
===================

    Drill  Plated  Size  Shape  ID
    ------------------------------
    35     Y       100   Round  D
    157    Y       100   Round  K
    16     Y       100   Round  M

    D-Code  Shape  (thou)
    ---------------------
    D21     Round 5.00
    D22     Round 100.00

End Of Report.

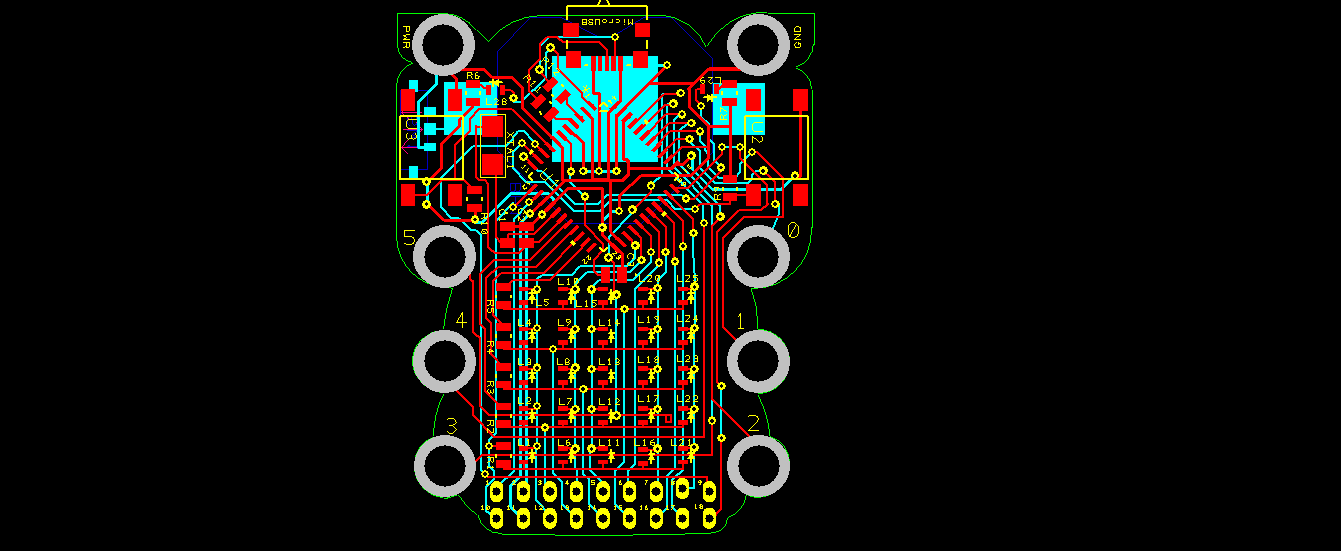
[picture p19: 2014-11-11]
device/historical/20141028_MicroBugGamma/MicroBugGamma.bmp

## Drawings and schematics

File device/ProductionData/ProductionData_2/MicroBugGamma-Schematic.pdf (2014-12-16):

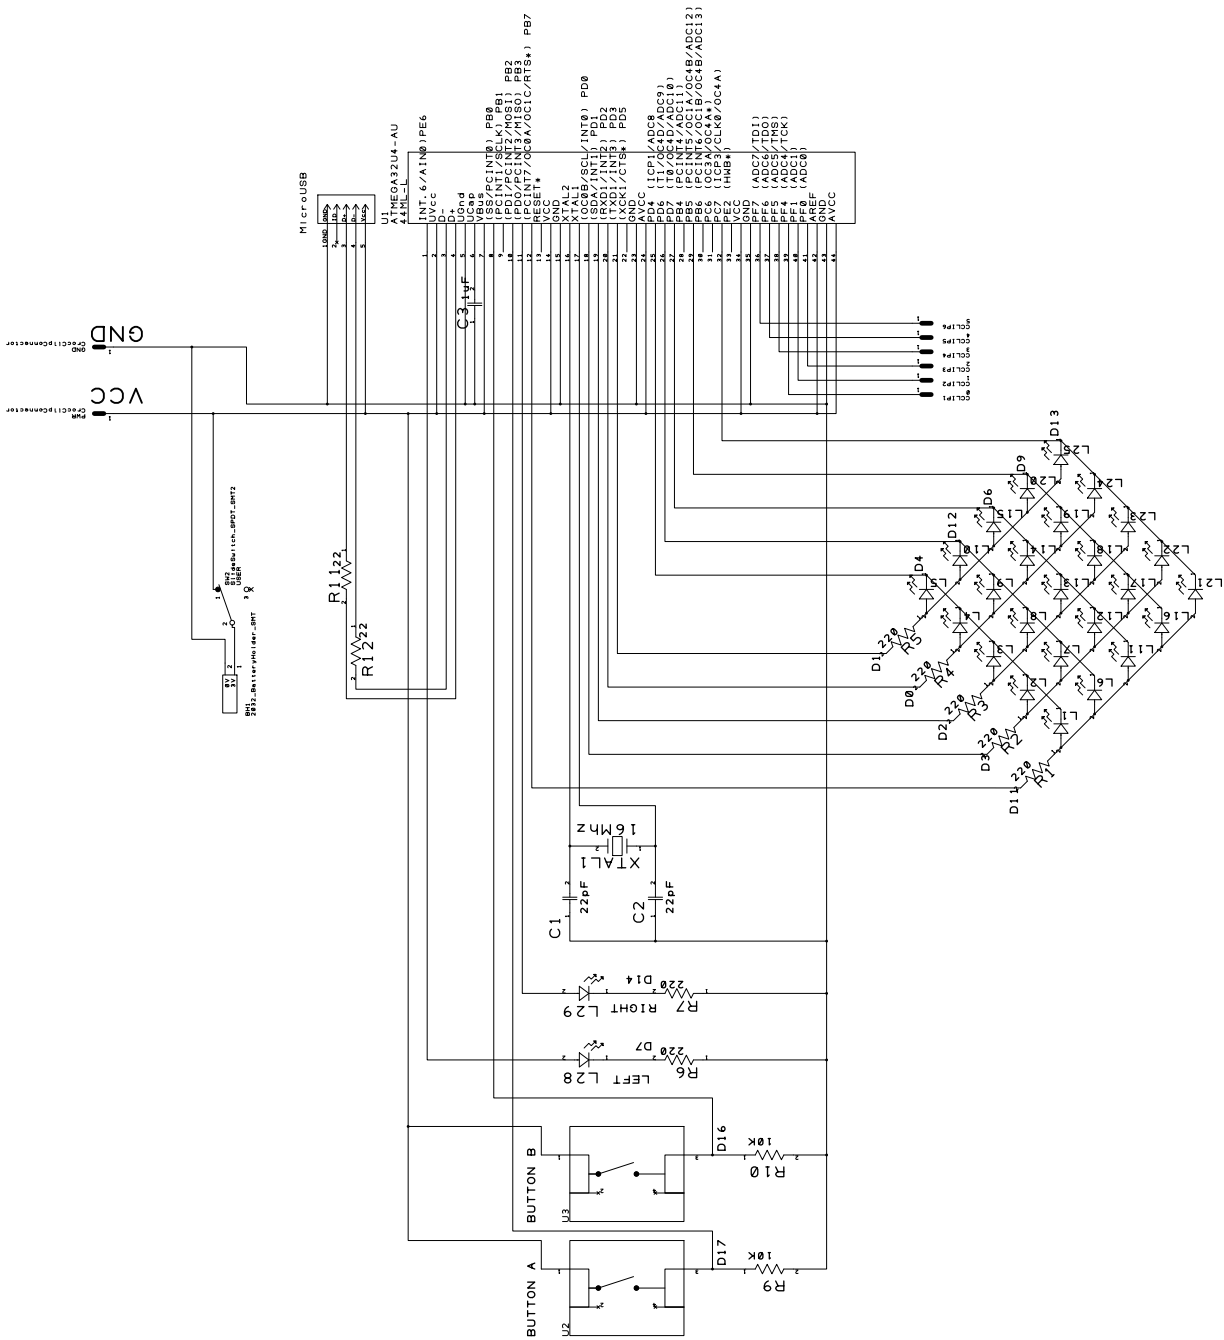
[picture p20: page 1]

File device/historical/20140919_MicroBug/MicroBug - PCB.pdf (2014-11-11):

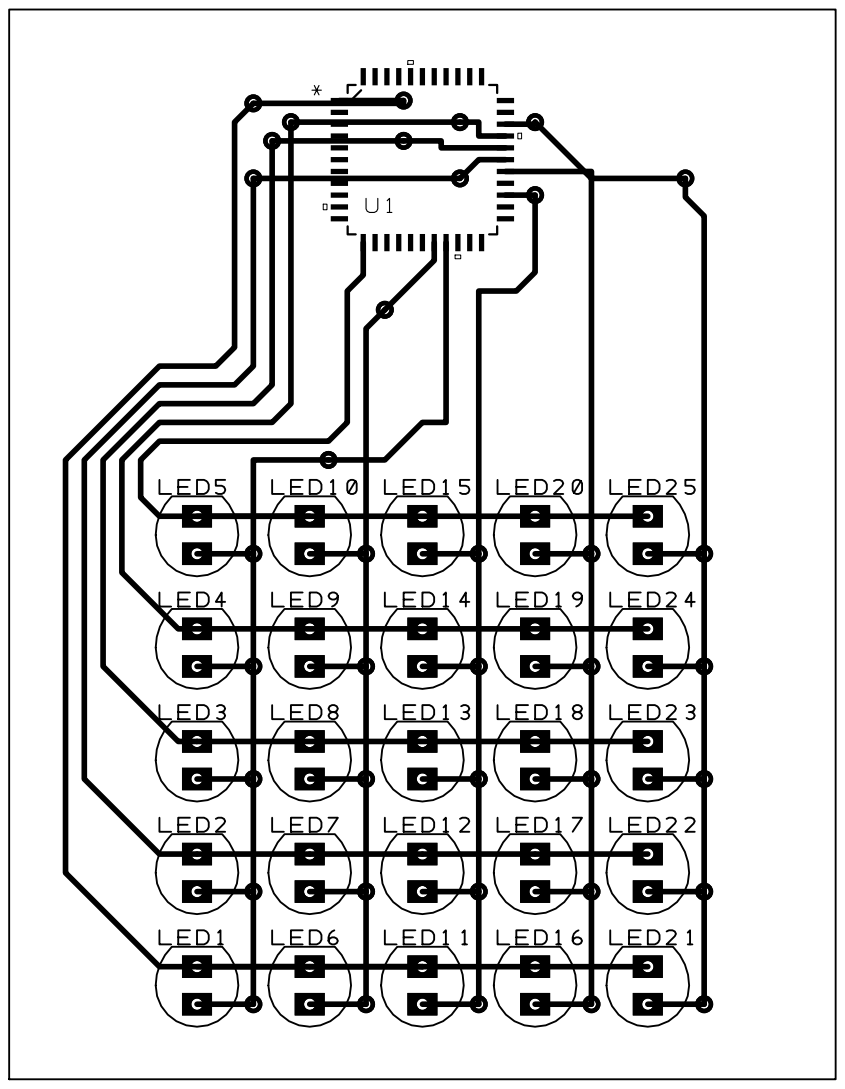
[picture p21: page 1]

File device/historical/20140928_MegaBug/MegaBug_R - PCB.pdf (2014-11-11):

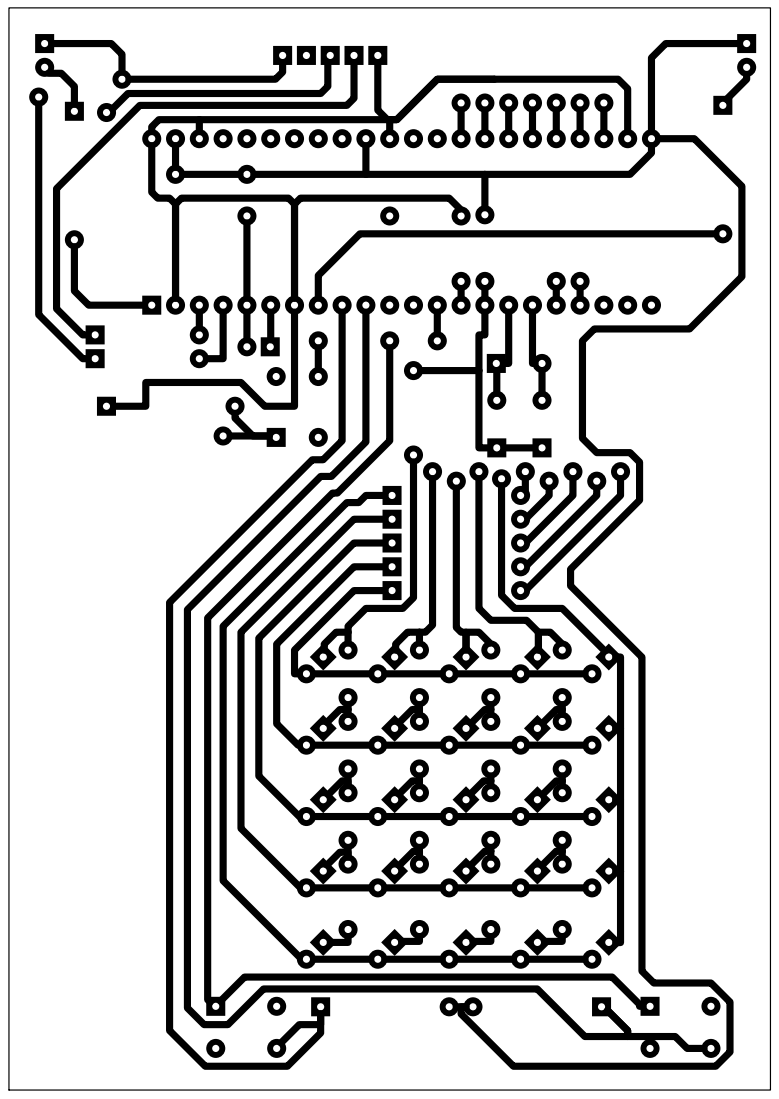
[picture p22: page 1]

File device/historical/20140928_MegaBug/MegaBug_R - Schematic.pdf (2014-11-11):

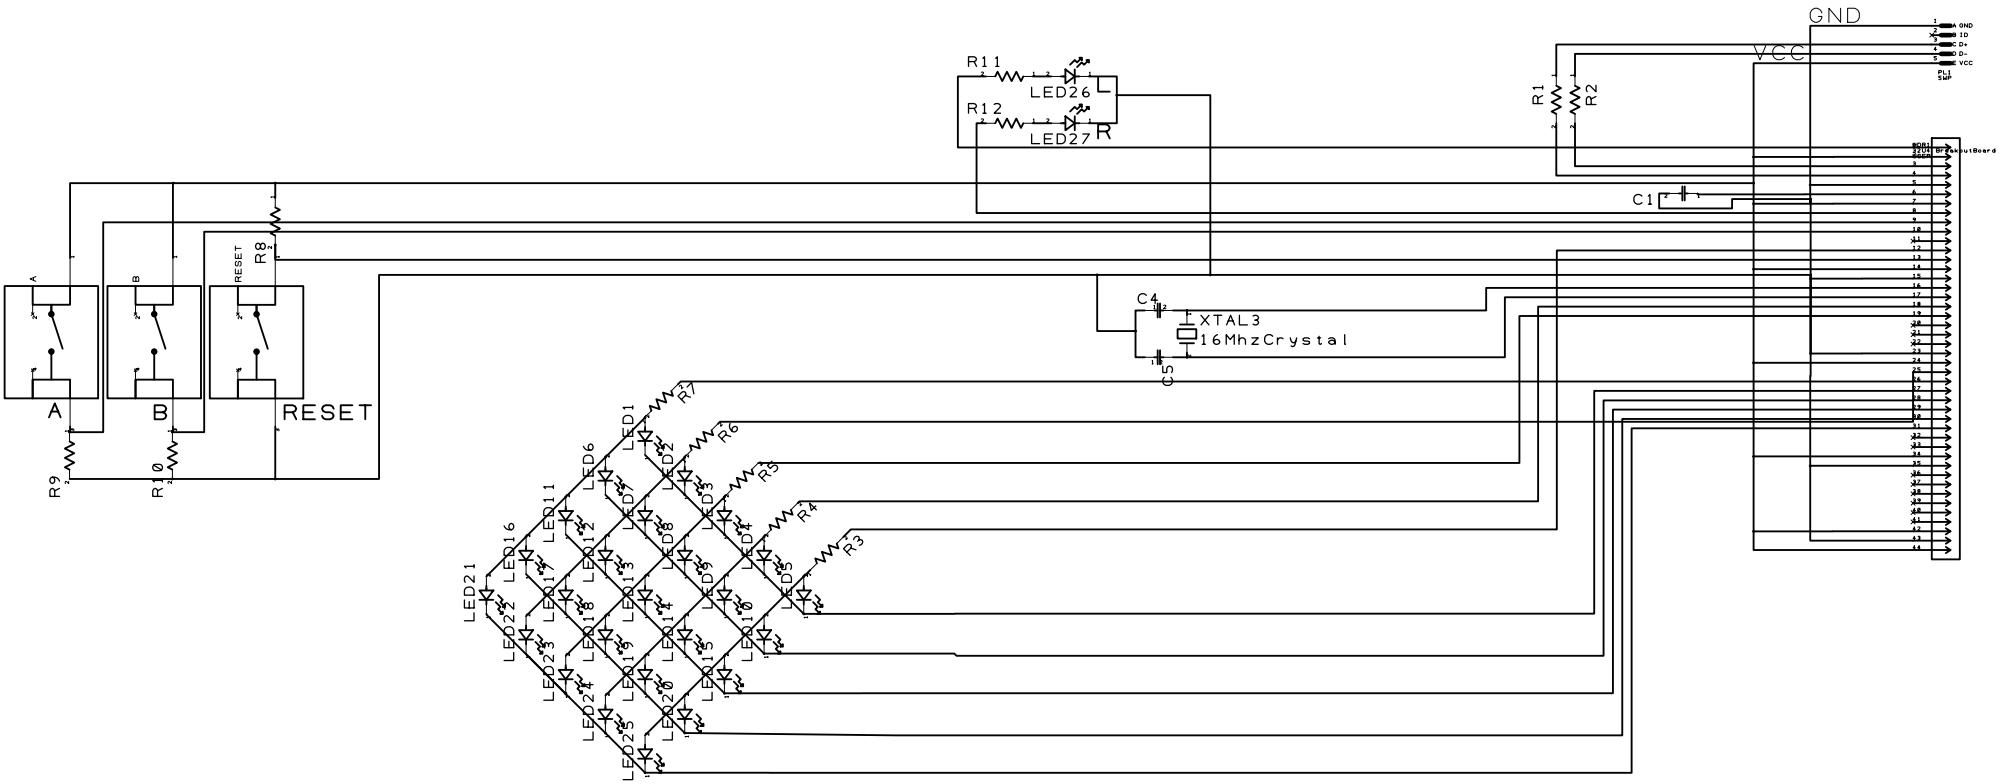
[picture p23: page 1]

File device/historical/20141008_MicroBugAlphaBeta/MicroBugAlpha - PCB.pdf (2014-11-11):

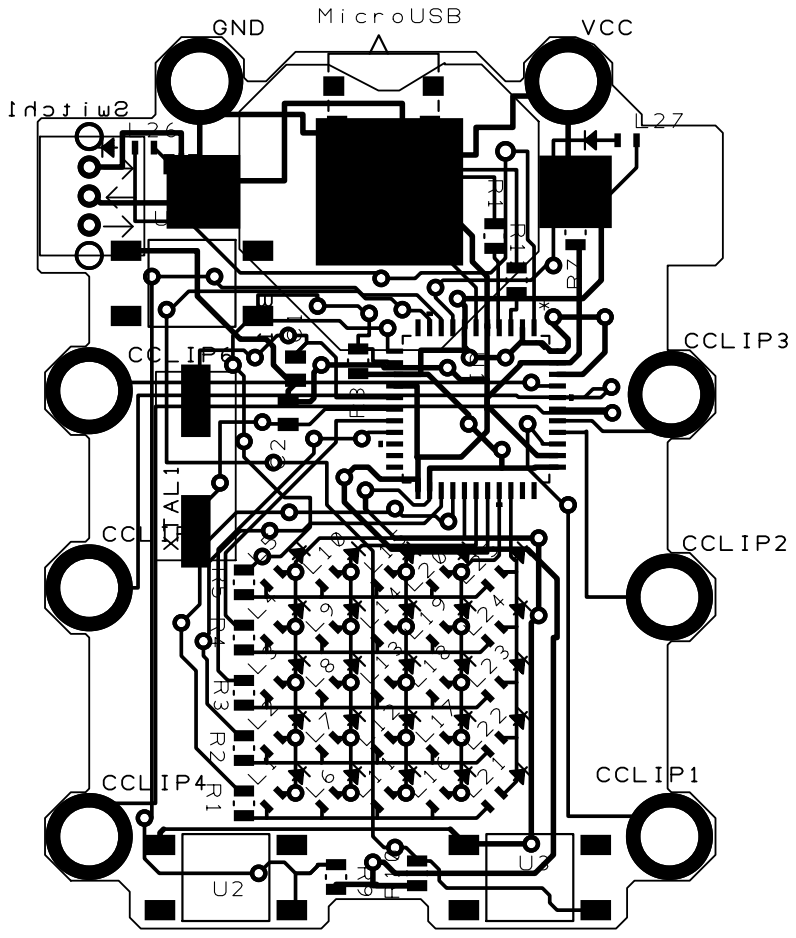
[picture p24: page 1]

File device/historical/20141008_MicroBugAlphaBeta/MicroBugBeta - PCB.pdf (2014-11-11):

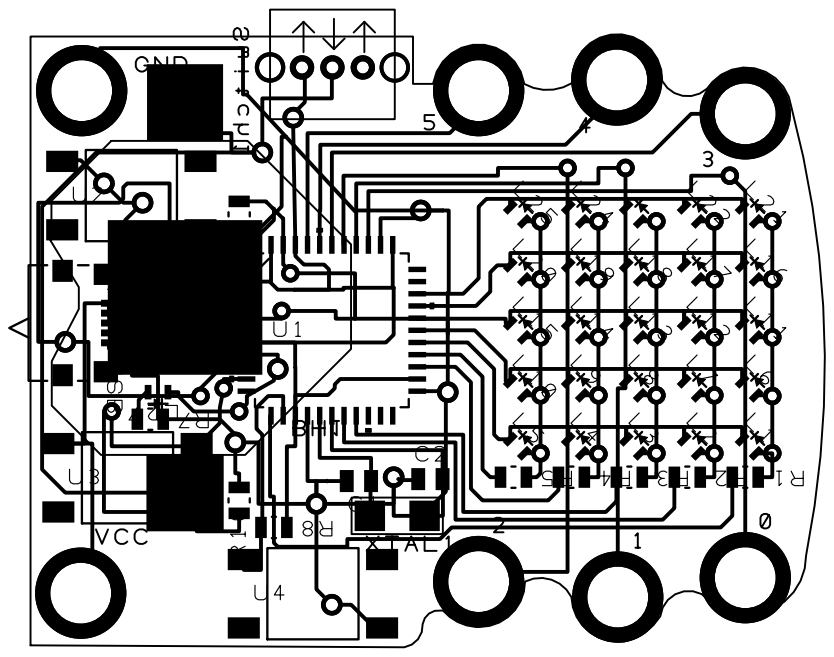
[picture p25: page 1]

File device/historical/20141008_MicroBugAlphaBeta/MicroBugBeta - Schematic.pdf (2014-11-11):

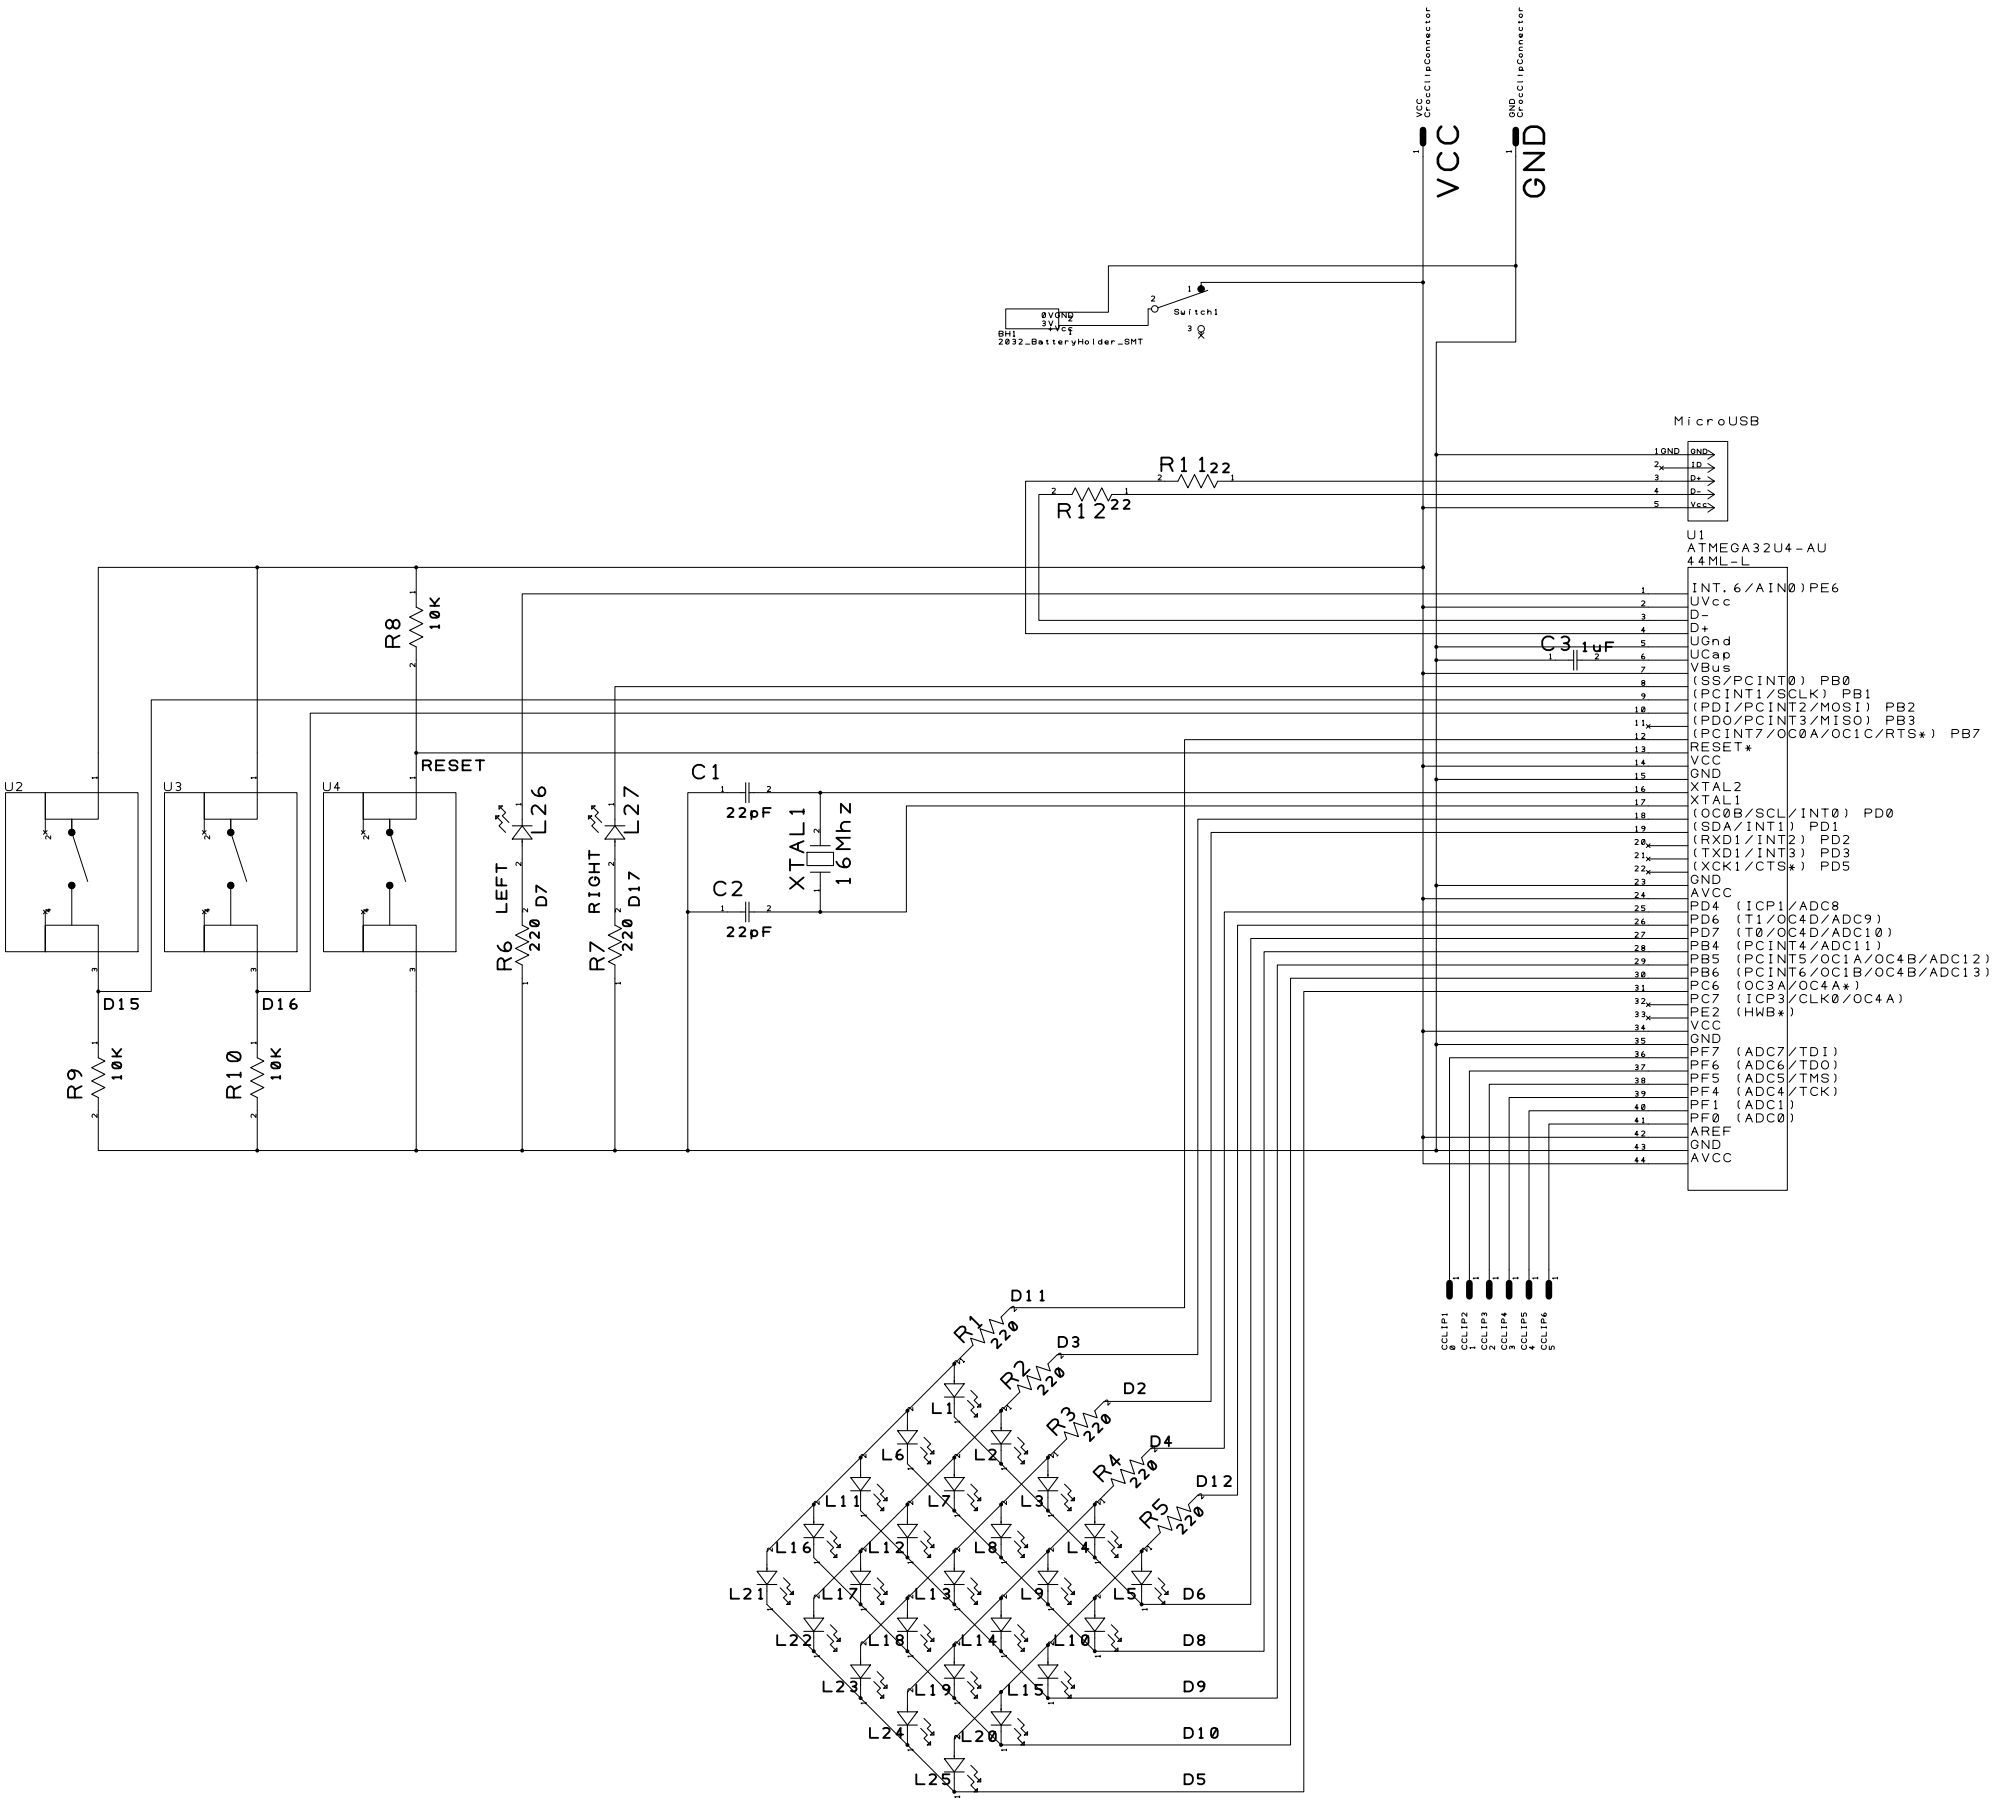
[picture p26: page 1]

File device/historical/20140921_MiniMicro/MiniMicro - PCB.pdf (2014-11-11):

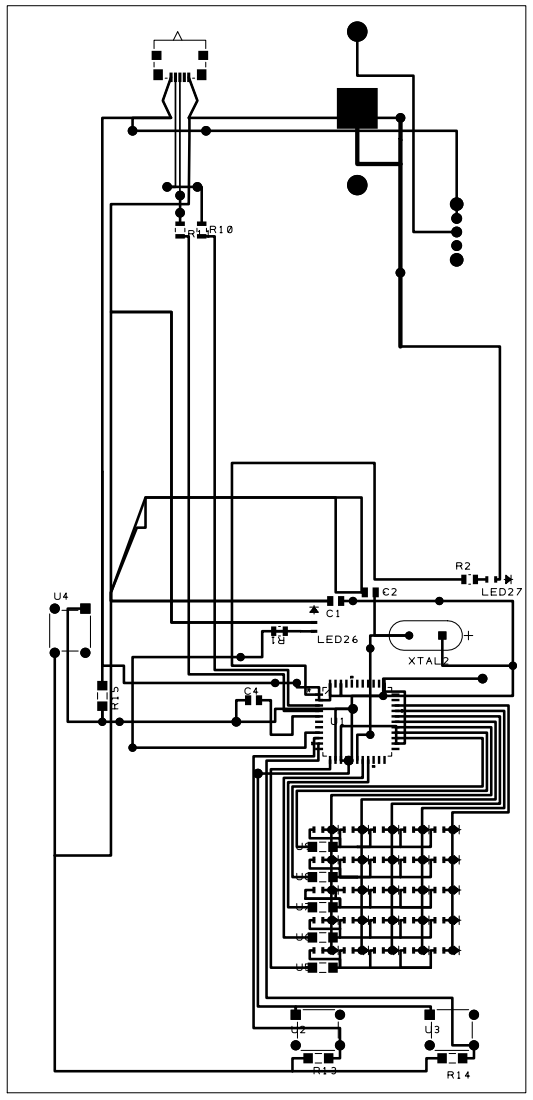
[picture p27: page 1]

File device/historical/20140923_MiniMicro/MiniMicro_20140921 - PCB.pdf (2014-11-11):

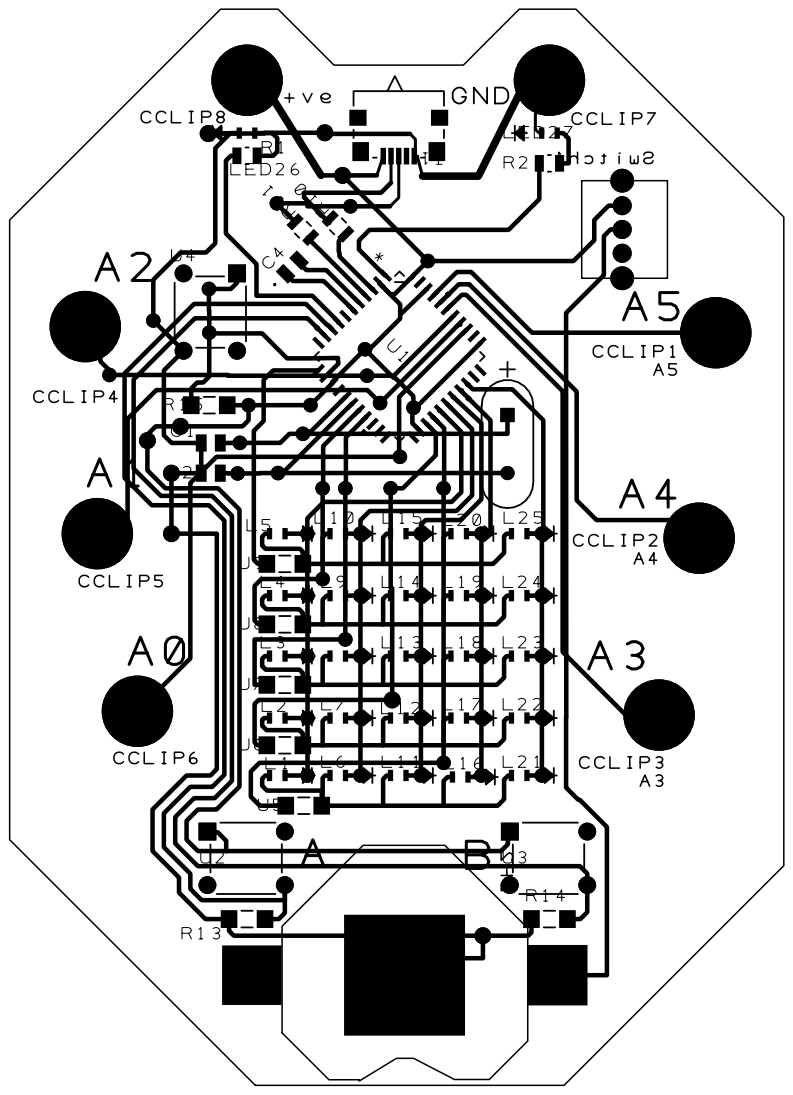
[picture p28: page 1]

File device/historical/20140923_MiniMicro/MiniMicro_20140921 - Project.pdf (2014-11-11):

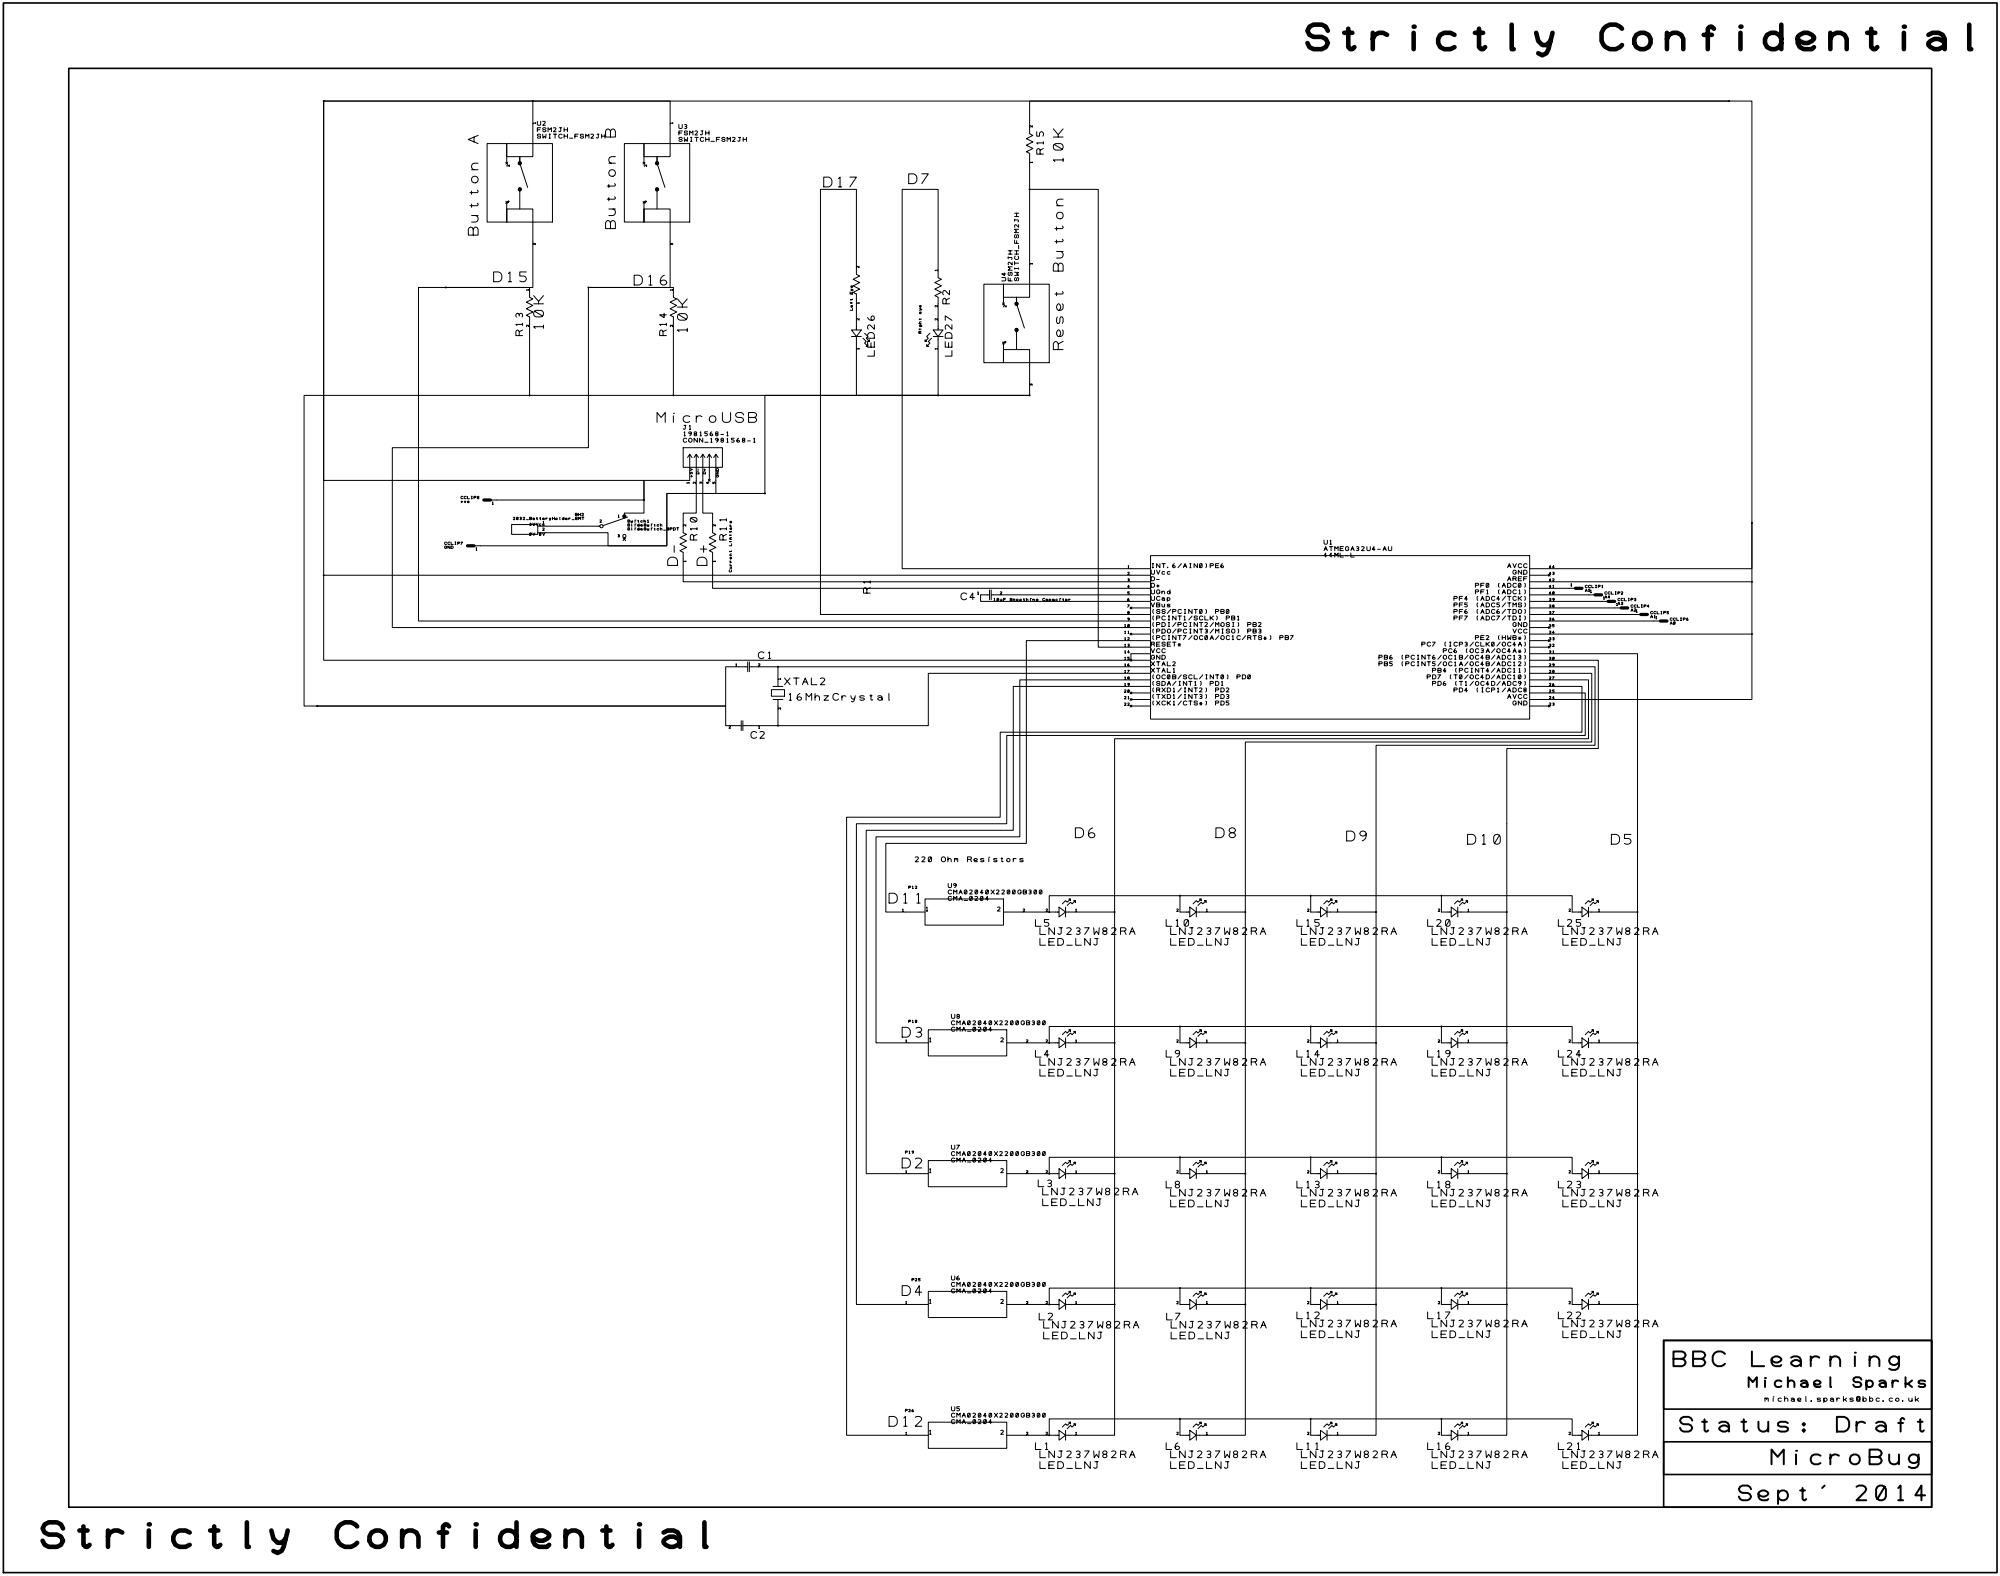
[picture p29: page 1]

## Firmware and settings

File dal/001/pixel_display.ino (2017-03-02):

#
# Copyright 2016 British Broadcasting Corporation and Contributors(1)
#
# (1) Contributors are listed in the AUTHORS file (please extend AUTHORS,
#     not this header)
#
# Licensed under the Apache License, Version 2.0 (the "License");
# you may not use this file except in compliance with the License.
# You may obtain a copy of the License at
#
#     http://www.apache.org/licenses/LICENSE-2.0
#
# Unless required by applicable law or agreed to in writing, software
# distributed under the License is distributed on an "AS IS" BASIS,
# WITHOUT WARRANTIES OR CONDITIONS OF ANY KIND, either express or implied.
# See the License for the specific language governing permissions and
# limitations under the License.
#

#define MICROBUG
#ifdef MEGABUG
int row0 = 11; // Arduino Pin for row 0
int row1 = 3; // Arduino Pin for row 1
int row2 = 2; // Arduino Pin for row 2
int row3 = 4; // Arduino Pin for row 3
int row4 = 12; // Arduino Pin for row 4

int col0 = 6; // Arduino Pin for row 0
int col1 = 8; // Arduino Pin for row 1
int col2 = 9; // Arduino Pin for row 2
int col3 = 10; // Arduino Pin for row 3
int col4 = 5; // Arduino Pin for row 4

int lefteye = 7; // Arduino Pin for left eye
int righteye = 17; // Arduino Pin for left eye

int ButtonA = 15; // Arduino Pin for left eye
int ButtonB = 16; // Arduino Pin for left eye
#endif


#ifdef MICROBUG

int row0 = 12; // Arduino Pin for row 0
int row1 = 4; // Arduino Pin for row 1
int row2 = 2; // Arduino Pin for row 2
int row3 = 3; // Arduino Pin for row 3
int row4 = 11; // Arduino Pin for row 4

int col0 = 6; // Arduino Pin for row 0
int col1 = 8; // Arduino Pin for row 1
int col2 = 9; // Arduino Pin for row 2
int col3 = 10; // Arduino Pin for row 3
int col4 = 5; // Arduino Pin for row 4

int lefteye = 7; // Arduino Pin for left eye
int righteye = 17; // Arduino Pin for left eye

int ButtonA = 15; // Arduino Pin for left eye
int ButtonB = 16; // Arduino Pin for left eye
#endif

#define DELAY 5
void setup()
{
      pinMode(row0, OUTPUT);
      pinMode(row1, OUTPUT);
      pinMode(row2, OUTPUT);
      pinMode(row3, OUTPUT);
      pinMode(row4, OUTPUT);

      pinMode(col0, OUTPUT);
      pinMode(col1, OUTPUT);
      pinMode(col2, OUTPUT);
      pinMode(col3, OUTPUT);
      pinMode(col4, OUTPUT);

      pinMode(lefteye, OUTPUT);
      pinMode(righteye, OUTPUT);

      pinMode(ButtonA, INPUT);
      pinMode(ButtonB, INPUT);

      digitalWrite(row0, LOW);
      digitalWrite(row1, LOW);
      digitalWrite(row2, LOW);
      digitalWrite(row3, LOW);
      digitalWrite(row4, LOW);

      digitalWrite(col0, LOW);
      digitalWrite(col1, LOW);
      digitalWrite(col2, LOW);
      digitalWrite(col3, LOW);
      digitalWrite(col4, LOW);

      digitalWrite(lefteye, LOW);
      digitalWrite(righteye, LOW);
}

void all_on() {
      digitalWrite(row0, HIGH);
      digitalWrite(row1, HIGH);
      digitalWrite(row2, HIGH);
      digitalWrite(row3, HIGH);
      digitalWrite(row4, HIGH);
      digitalWrite(col0, LOW);
      digitalWrite(col1, LOW);
      digitalWrite(col2, LOW);
      digitalWrite(col3, LOW);
      digitalWrite(col4, LOW);
}

void all_off() {
      digitalWrite(row0, LOW);
      digitalWrite(row1, LOW);
      digitalWrite(row2, LOW);
      digitalWrite(row3, LOW);
      digitalWrite(row4, LOW);

      digitalWrite(col0, LOW);
      digitalWrite(col1, LOW);
      digitalWrite(col2, LOW);
      digitalWrite(col3, LOW);
      digitalWrite(col4, LOW);
}


void iterate_rows() {
      digitalWrite(row0, LOW);
      digitalWrite(row1, LOW);
      digitalWrite(row2, LOW);
      digitalWrite(row3, LOW);
      digitalWrite(row4, LOW);
      digitalWrite(col0, LOW);
      digitalWrite(col1, LOW);
      digitalWrite(col2, LOW);
      digitalWrite(col3, LOW);
      digitalWrite(col4, LOW);

      digitalWrite(row0, HIGH);
  delay(DELAY);
      digitalWrite(row0, LOW);

      digitalWrite(row1, HIGH);
  delay(DELAY);
      digitalWrite(row1, LOW);

      digitalWrite(row2, HIGH);
  delay(DELAY);
      digitalWrite(row2, LOW);

      digitalWrite(row3, HIGH);
  delay(DELAY);
      digitalWrite(row3, LOW);

      digitalWrite(row4, HIGH);
  delay(DELAY);
      digitalWrite(row4, LOW);

}

void iterate_cols() {
      digitalWrite(col0, HIGH);
      digitalWrite(col1, HIGH);
      digitalWrite(col2, HIGH);
      digitalWrite(col3, HIGH);
      digitalWrite(col4, HIGH);

      digitalWrite(row0, HIGH);
      digitalWrite(row1, HIGH);
      digitalWrite(row2, HIGH);
      digitalWrite(row3, HIGH);
      digitalWrite(row4, HIGH);

      digitalWrite(col0, LOW);
  delay(DELAY);
      digitalWrite(col0, HIGH);

      digitalWrite(col1, LOW);
  delay(DELAY);
      digitalWrite(col1, HIGH);

      digitalWrite(col2, LOW);
  delay(DELAY);
      digitalWrite(col2, HIGH);

      digitalWrite(col3, LOW);
  delay(DELAY);
      digitalWrite(col3, HIGH);

      digitalWrite(col4, LOW);
  delay(DELAY);
      digitalWrite(col4, HIGH);


}

void pixels() {

      digitalWrite(row0, HIGH); digitalWrite(row1, LOW ); digitalWrite(row2, LOW ); digitalWrite(row3, LOW ); digitalWrite(row4, LOW );
      digitalWrite(col0, LOW); digitalWrite(col1, HIGH); digitalWrite(col2, HIGH); digitalWrite(col3, HIGH); digitalWrite(col4, HIGH);
  delay(DELAY);

      digitalWrite(row0, HIGH); digitalWrite(row1, LOW ); digitalWrite(row2, LOW ); digitalWrite(row3, LOW ); digitalWrite(row4, LOW );
      digitalWrite(col0, HIGH); digitalWrite(col1, LOW ); digitalWrite(col2, HIGH); digitalWrite(col3, HIGH); digitalWrite(col4, HIGH);
  delay(DELAY);

      digitalWrite(row0, HIGH); digitalWrite(row1, LOW ); digitalWrite(row2, LOW ); digitalWrite(row3, LOW ); digitalWrite(row4, LOW );
      digitalWrite(col0, HIGH); digitalWrite(col1, HIGH); digitalWrite(col2, LOW ); digitalWrite(col3, HIGH); digitalWrite(col4, HIGH);
  delay(DELAY);

      digitalWrite(row0, HIGH); digitalWrite(row1, LOW ); digitalWrite(row2, LOW ); digitalWrite(row3, LOW ); digitalWrite(row4, LOW );
      digitalWrite(col0, HIGH); digitalWrite(col1, HIGH); digitalWrite(col2, HIGH); digitalWrite(col3, LOW ); digitalWrite(col4, HIGH);
  delay(DELAY);

      digitalWrite(row0, HIGH); digitalWrite(row1, LOW ); digitalWrite(row2, LOW ); digitalWrite(row3, LOW ); digitalWrite(row4, LOW );
      digitalWrite(col0, HIGH); digitalWrite(col1, HIGH); digitalWrite(col2, HIGH); digitalWrite(col3, HIGH); digitalWrite(col4, LOW );
  delay(DELAY);

// -------------------
      digitalWrite(row0, LOW ); digitalWrite(row1, HIGH); digitalWrite(row2, LOW ); digitalWrite(row3, LOW ); digitalWrite(row4, LOW );
      digitalWrite(col0, LOW ); digitalWrite(col1, HIGH); digitalWrite(col2, HIGH); digitalWrite(col3, HIGH); digitalWrite(col4, HIGH);
  delay(DELAY);

      digitalWrite(row0, LOW ); digitalWrite(row1, HIGH); digitalWrite(row2, LOW ); digitalWrite(row3, LOW ); digitalWrite(row4, LOW );
      digitalWrite(col0, HIGH); digitalWrite(col1, LOW ); digitalWrite(col2, HIGH); digitalWrite(col3, HIGH); digitalWrite(col4, HIGH);
  delay(DELAY);

      digitalWrite(row0, LOW ); digitalWrite(row1, HIGH); digitalWrite(row2, LOW ); digitalWrite(row3, LOW ); digitalWrite(row4, LOW );
      digitalWrite(col0, HIGH); digitalWrite(col1, HIGH); digitalWrite(col2, LOW ); digitalWrite(col3, HIGH); digitalWrite(col4, HIGH);
  delay(DELAY);

      digitalWrite(row0, LOW ); digitalWrite(row1, HIGH); digitalWrite(row2, LOW ); digitalWrite(row3, LOW ); digitalWrite(row4, LOW );
      digitalWrite(col0, HIGH); digitalWrite(col1, HIGH); digitalWrite(col2, HIGH); digitalWrite(col3, LOW ); digitalWrite(col4, HIGH);
  delay(DELAY);

      digitalWrite(row0, LOW ); digitalWrite(row1, HIGH); digitalWrite(row2, LOW ); digitalWrite(row3, LOW ); digitalWrite(row4, LOW );
      digitalWrite(col0, HIGH); digitalWrite(col1, HIGH); digitalWrite(col2, HIGH); digitalWrite(col3, HIGH); digitalWrite(col4, LOW );
  delay(DELAY);

// --------------------
      digitalWrite(row0, LOW ); digitalWrite(row1, LOW ); digitalWrite(row2, HIGH); digitalWrite(row3, LOW ); digitalWrite(row4, LOW );
      digitalWrite(col0, LOW ); digitalWrite(col1, HIGH); digitalWrite(col2, HIGH); digitalWrite(col3, HIGH); digitalWrite(col4, HIGH);
  delay(DELAY);

      digitalWrite(row0, LOW ); digitalWrite(row1, LOW ); digitalWrite(row2, HIGH); digitalWrite(row3, LOW ); digitalWrite(row4, LOW );
      digitalWrite(col0, HIGH); digitalWrite(col1, LOW ); digitalWrite(col2, HIGH); digitalWrite(col3, HIGH); digitalWrite(col4, HIGH);
  delay(DELAY);

      digitalWrite(row0, LOW ); digitalWrite(row1, LOW ); digitalWrite(row2, HIGH); digitalWrite(row3, LOW ); digitalWrite(row4, LOW );
      digitalWrite(col0, HIGH); digitalWrite(col1, HIGH); digitalWrite(col2, LOW ); digitalWrite(col3, HIGH); digitalWrite(col4, HIGH);
  delay(DELAY);

      digitalWrite(row0, LOW ); digitalWrite(row1, LOW ); digitalWrite(row2, HIGH); digitalWrite(row3, LOW ); digitalWrite(row4, LOW );
      digitalWrite(col0, HIGH); digitalWrite(col1, HIGH); digitalWrite(col2, HIGH); digitalWrite(col3, LOW ); digitalWrite(col4, HIGH);
  delay(DELAY);

      digitalWrite(row0, LOW ); digitalWrite(row1, LOW ); digitalWrite(row2, HIGH); digitalWrite(row3, LOW ); digitalWrite(row4, LOW );
      digitalWrite(col0, HIGH); digitalWrite(col1, HIGH); digitalWrite(col2, HIGH); digitalWrite(col3, HIGH); digitalWrite(col4, LOW );
  delay(DELAY);
// ----------------------
      digitalWrite(row0, LOW ); digitalWrite(row1, LOW ); digitalWrite(row2, LOW ); digitalWrite(row3, HIGH); digitalWrite(row4, LOW );
      digitalWrite(col0, LOW ); digitalWrite(col1, HIGH); digitalWrite(col2, HIGH); digitalWrite(col3, HIGH); digitalWrite(col4, HIGH);
  delay(DELAY);

      digitalWrite(row0, LOW ); digitalWrite(row1, LOW ); digitalWrite(row2, LOW ); digitalWrite(row3, HIGH); digitalWrite(row4, LOW );
      digitalWrite(col0, HIGH); digitalWrite(col1, LOW ); digitalWrite(col2, HIGH); digitalWrite(col3, HIGH); digitalWrite(col4, HIGH);
  delay(DELAY);

      digitalWrite(row0, LOW ); digitalWrite(row1, LOW ); digitalWrite(row2, LOW ); digitalWrite(row3, HIGH); digitalWrite(row4, LOW );
      digitalWrite(col0, HIGH); digitalWrite(col1, HIGH); digitalWrite(col2, LOW ); digitalWrite(col3, HIGH); digitalWrite(col4, HIGH);
  delay(DELAY);

      digitalWrite(row0, LOW ); digitalWrite(row1, LOW ); digitalWrite(row2, LOW ); digitalWrite(row3, HIGH); digitalWrite(row4, LOW );
      digitalWrite(col0, HIGH); digitalWrite(col1, HIGH); digitalWrite(col2, HIGH); digitalWrite(col3, LOW ); digitalWrite(col4, HIGH);
  delay(DELAY);

      digitalWrite(row0, LOW ); digitalWrite(row1, LOW ); digitalWrite(row2, LOW ); digitalWrite(row3, HIGH); digitalWrite(row4, LOW );
      digitalWrite(col0, HIGH); digitalWrite(col1, HIGH); digitalWrite(col2, HIGH); digitalWrite(col3, HIGH); digitalWrite(col4, LOW );
  delay(DELAY);
// ----------------------
      digitalWrite(row0, LOW ); digitalWrite(row1, LOW ); digitalWrite(row2, LOW ); digitalWrite(row3, LOW ); digitalWrite(row4, HIGH);
      digitalWrite(col0, LOW); digitalWrite(col1, HIGH); digitalWrite(col2, HIGH); digitalWrite(col3, HIGH); digitalWrite(col4, HIGH);
  delay(DELAY);

      digitalWrite(row0, LOW ); digitalWrite(row1, LOW ); digitalWrite(row2, LOW ); digitalWrite(row3, LOW ); digitalWrite(row4, HIGH);
      digitalWrite(col0, HIGH); digitalWrite(col1, LOW ); digitalWrite(col2, HIGH); digitalWrite(col3, HIGH); digitalWrite(col4, HIGH);
  delay(DELAY);

      digitalWrite(row0, LOW ); digitalWrite(row1, LOW ); digitalWrite(row2, LOW ); digitalWrite(row3, LOW ); digitalWrite(row4, HIGH);
      digitalWrite(col0, HIGH); digitalWrite(col1, HIGH); digitalWrite(col2, LOW ); digitalWrite(col3, HIGH); digitalWrite(col4, HIGH);
  delay(DELAY);

      digitalWrite(row0, LOW ); digitalWrite(row1, LOW ); digitalWrite(row2, LOW ); digitalWrite(row3, LOW ); digitalWrite(row4, HIGH);
      digitalWrite(col0, HIGH); digitalWrite(col1, HIGH); digitalWrite(col2, HIGH); digitalWrite(col3, LOW ); digitalWrite(col4, HIGH);
  delay(DELAY);

      digitalWrite(row0, LOW ); digitalWrite(row1, LOW ); digitalWrite(row2, LOW ); digitalWrite(row3, LOW ); digitalWrite(row4, HIGH);
      digitalWrite(col0, HIGH); digitalWrite(col1, HIGH); digitalWrite(col2, HIGH); digitalWrite(col3, HIGH); digitalWrite(col4, LOW );
  delay(DELAY);



}

void blink_eyes() {
  digitalWrite(lefteye,HIGH);
  digitalWrite(righteye,HIGH);
  delay(200);
  digitalWrite(lefteye,LOW);
  digitalWrite(righteye,LOW);
}

void loop() {
    int button_a = digitalRead(ButtonA);
    int button_b = digitalRead(ButtonB);

    if (button_a && button_b) {
      all_on();
      delay(100);
      all_off();
      delay(100);
    } else if (button_a) {
        iterate_rows();
    } else if (button_b) {
        iterate_cols();
    } else {
        pixels();
//        blink_eyes();
    }
}

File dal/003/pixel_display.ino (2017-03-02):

#
# Copyright 2016 British Broadcasting Corporation and Contributors(1)
#
# (1) Contributors are listed in the AUTHORS file (please extend AUTHORS,
#     not this header)
#
# Licensed under the Apache License, Version 2.0 (the "License");
# you may not use this file except in compliance with the License.
# You may obtain a copy of the License at
#
#     http://www.apache.org/licenses/LICENSE-2.0
#
# Unless required by applicable law or agreed to in writing, software
# distributed under the License is distributed on an "AS IS" BASIS,
# WITHOUT WARRANTIES OR CONDITIONS OF ANY KIND, either express or implied.
# See the License for the specific language governing permissions and
# limitations under the License.
#

#include "spark_font.h"

#define PRESSED HIGH

#define MICROBUG
// #define Megabug

#ifdef MEGABUG

int row0 = 11; // Arduino Pin for row 0
int row1 = 3; // Arduino Pin for row 1
int row2 = 2; // Arduino Pin for row 2
int row3 = 4; // Arduino Pin for row 3
int row4 = 12; // Arduino Pin for row 4

int col0 = 6; // Arduino Pin for row 0
int col1 = 8; // Arduino Pin for row 1
int col2 = 9; // Arduino Pin for row 2
int col3 = 10; // Arduino Pin for row 3
int col4 = 5; // Arduino Pin for row 4

int lefteye = 7; // Arduino Pin for left eye
int righteye = 17; // Arduino Pin for left eye

int ButtonA = 15; // Arduino Pin for left eye
int ButtonB = 16; // Arduino Pin for left eye

#endif

#ifdef MICROBUG

int row0 = 12; // Arduino Pin for row 0
int row1 = 4; // Arduino Pin for row 1
int row2 = 2; // Arduino Pin for row 2
int row3 = 3; // Arduino Pin for row 3
int row4 = 11; // Arduino Pin for row 4

int col0 = 6; // Arduino Pin for row 0
int col1 = 8; // Arduino Pin for row 1
int col2 = 9; // Arduino Pin for row 2
int col3 = 10; // Arduino Pin for row 3
int col4 = 5; // Arduino Pin for row 4

int lefteye = 7; // Arduino Pin for left eye
int righteye = 17; // Arduino Pin for left eye

int ButtonA = 16; // Arduino Pin for left eye
int ButtonB = 15; // Arduino Pin for left eye

#endif

int counter =0;
#define DELAY 5

int timer4_counter;

int display_strobe_counter;
int display[5][5] = {
                      { LOW, LOW, LOW, LOW, LOW},
                      { LOW, LOW, LOW, LOW, LOW},
                      { LOW, LOW, LOW, LOW, LOW},
                      { LOW, LOW, LOW, LOW, LOW},
                      { LOW, LOW, LOW, LOW, LOW}
                    };

/* API ---------------------------------------------------------------------------------------- */

#define DISPLAY_WIDTH 5
#define DISPLAY_HEIGHT 5

#define ___ 0

typedef struct Image {
    int width;
    int height;
    int *data ;
} Image;

void set_eye(char id, int state);
void eye_on(char id);
void eye_off(char id);
void print_message(const char * message, int pausetime);
void showLetter(char c);
int getButton(char id);
void clear_display();
void plot(int x, int y);
void unplot(int x, int y);
int point(int x, int y);
void set_display(int sprite[5][5]);
void showViewport(Image& someImage, int x, int y);
void ScrollImage(Image someImage, boolean loop);
int image_point(Image& someImage, int x, int y);
void set_image_point(Image& someImage, int x, int y, int value);
void showLetter(char c); // Could be just internal, but useful.
void print_message(const char * message, int pausetime);

struct StringSprite;
void scroll_sprite(StringSprite theSprite, int pausetime);

// Functions internal to the API
inline int image_point_index(Image& someImage, int x, int y);
void display_column(int i);
void setup_display();
void microbug_setup();
void bootloader_start(void);
void check_bootkey();

/* END API ------------------------------------------------------------------------------------ */


// CODE TO SUPPORT SWITCH TO DFU BOOTLOADER -------------------------------------------------------

#include "avr/wdt.h"
#include "atmel_bootloader.h"

#define Usb_detach()                              (UDCON   |=  (1<<DETACH))

void bootloader_start(void) {
    /* This needs to reset the devive to a state the bootloader expects.
     * This means for example:
     *   Detaching from USB
     *   Waiting for the host to register the detach (we wait for 200 milli)
     *   Switch off all timers
     *   Reset registers to initial states
     *   Then and only then jump to the DFU bootloader
     */
    Usb_detach();
    cli();
    delay(200);
    MCUSR &= ~(1 << WDRF);
    wdt_disable();

    TIMSK0 = USBINT = OTGCON = OTGTCON = OTGIEN = OTGINT = PLLCSR = TCNT1L = TCNT1H = TIMSK3 = TCCR1B = TCNT4L = TCNT4H = TCCR4B = 0x00;
    USBCON = 0x20;
    UHWCON = 0x80;
    USBSTA = 0x08;

    run_bootloader();
}

void check_bootkey() {
    if (digitalRead(ButtonA) == PRESSED) {
        bootloader_start();
    }
}
// END CODE TO SUPPORT SWITCH TO DFU BOOTLOADER -------------------------------------------------------


void setup_display() {
#ifdef MICROBUG

CLKPR = 0x80;
CLKPR = 0x01;
#endif

    // initialize timer4 
    noInterrupts();           // disable all interrupts
    TCCR4A = 0;
    TCCR4B = 0;
    // Set timer4_counter to the correct value for our interrupt interval
    // timer4_counter = 64911;     // preload timer 65536-16MHz/256/100Hz
    timer4_counter = 65224;     // preload timer 65536-16MHz/256/200Hz
    // timer4_counter = 65497;     // preload timer 65536-2MHz/256/200Hz // For some reason current microbug is operating at 2MHz

    TCNT4 = timer4_counter;   // preload timer
    TCCR4B |= (1 << CS12);    // 256 prescaler 
    TIMSK4 |= (1 << TOIE4);   // enable timer overfLOW interrupt
    interrupts();             // enable all interrupts
}


ISR(TIMER4_OVF_vect)        // interrupt service routine 
{
    TCNT4 = timer4_counter;   // preload timer
    display_column(display_strobe_counter % 5);

    display_strobe_counter += 1;
    if (display_strobe_counter > 200) {
        display_strobe_counter = 0; // reset
    }
}

void microbug_setup() { // This is a really MicroBug setup
    setup_display();

    display_strobe_counter = 0;

    pinMode(row0, OUTPUT);
    pinMode(row1, OUTPUT);
    pinMode(row2, OUTPUT);
    pinMode(row3, OUTPUT);
    pinMode(row4, OUTPUT);

    pinMode(col0, OUTPUT);
    pinMode(col1, OUTPUT);
    pinMode(col2, OUTPUT);
    pinMode(col3, OUTPUT);
    pinMode(col4, OUTPUT);

    pinMode(lefteye, OUTPUT);
    pinMode(righteye, OUTPUT);

    pinMode(ButtonA, INPUT);
    pinMode(ButtonB, INPUT);

    digitalWrite(row0, LOW);
    digitalWrite(row1, LOW);
    digitalWrite(row2, LOW);
    digitalWrite(row3, LOW);
    digitalWrite(row4, LOW);

    digitalWrite(col0, HIGH);
    digitalWrite(col1, HIGH);
    digitalWrite(col2, HIGH);
    digitalWrite(col3, HIGH);
    digitalWrite(col4, HIGH);

    digitalWrite(lefteye, LOW);
    digitalWrite(righteye, LOW);
check_bootkey();

}
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

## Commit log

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2014-10-11 Boolean literals and while loop support
    Also added a special case - never_statement (while False)
2014-10-11 Switched parser to support else clauses
    Else clause provides the hook for being just a plain else clause
    or further elifs.
2014-10-11 Support for elif (and fixed else)
    elif is currently mutally exclusive of else
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2014-10-11 Example of multiply chained elifs
    This parses, but the AST could be nicer
2014-10-12 Added microfont.odt file
    This was used during the creation/design of the font included here.
    In particular it's derived from the open source font "tiny" which
    is available here:
    http://www.squaregear.net/fonts/tiny.shtml
    In particular, this is a permissive BSD/MIT style license. In many
    respects it's used as inspiration, or for lower case letters. However
    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
2014-10-13 First command line program for the device
    This is the same program that I've used for testing the device to date,
    but just built and installed using command line tools. Specifically,
    you do this:
    make
    <press reset on device>
    make upload
    This results in the code being uploaded to the device.
    This code loops through all the pixels displaying them, and based on
    button presses changes the behaviour. While simplistic, it's useful
    for testing the LEDS..
    [pixel_display.ino]
2014-10-13 Strobing/persistence of vision for display updates
    Switch to representing the display using an array, and strobe through
    it rapidly to show patterns you wouldn't be able to do so otherwise.
    Proof of concept - wouldn't play nicely with other code, but proves it
    works
2014-10-13 Interrupt driven display
    The display is now driven by timer interrupts. This allows treating the
    display as images to be updated, or even addressing individual pixels.
    Uses TIMER1, which may or may not be what we need/want.
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2014-10-18 Changes to allow testing on Microbug - which inverts rows
    [pixel_display.ino]
2014-10-18 2Mhz base for timer, reorder behaviour in display handler
    For some reason the manually created microbug is running at 2Mhz - or
    the timers are based off that, based on a manual calculation. Changed
    timers based on this.
    Secondly, the LEDs used in the microbug have a faster response time,
    so the code showed up ghosting if switches were toggled in a particular
    order. They're now toggled in an order that prevents that.
    [pixel_display.ino]
2014-10-19 Fix to the system clock speed
    Wish I'd found this page sooner:
    http://dougspcbdesigns.pbworks.com/w/page/59725474/ATMega32U4%20Bringup
    [pixel_display.ino]
2014-10-20 Fix delays to work with the normal clock speed/
    [pixel_display.ino]
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2014-10-20 Better Makefile
    make all - calls the avr/arduino toolchain
    make erase - uses the dfu-programmer to clear the device and enable changes
    make flash_device - uses dfu-programmer to flash the device with the hex file
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2014-10-31 Improve lower case fonts
    Lower case fonts could do with some improvement - esp when you start scrolling
    them. Hence this change.
2014-10-31 Fix function signature of print_message
    This is to prevent print_message complaining about printing string literals.
    [pixel_display.ino]
2014-10-31 Switch font repr to unsigned char* (halves size)
    Changed the font representation to unsigned chars - this halves the
    size of the data used. Next step is to shift this into progmem, and
    perhaps use a nibble based representation, given we only use 4 bits
    per row.
    I suspect the shift into progmem will be the most beneficial change
    to be fair.
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2014-10-31 Initial version of the DAL, derived from 003
    This removes the setup/loop functions and all the test examples, and is
    flipped to being a .h
    [dal.h]
2014-10-31 Necessary for rebooting the device - enabling programming mode
    [atmel_bootloader.h]
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2014-11-10 Switch back to devkit device for testing code
    (The devkit code is far easier to roundtrip development on, so using that in preferance during dev)
2014-11-10 Now using Twitter Bootstrap
    Added the code to get the Twitter Bootstrap framework up and running.
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2014-11-11 "eye" LED manipulation
    Switch off eyes before the device's setup() call (generically)
    In this example setup now switches the eyes on.
2014-11-11 Hardware design files for Microbug - from zero to now
    [MegaBug.sch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]
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2014-11-11 Production data for the second PCB print run, third device iteration
    [MicroBugGamma - Bottom Copper (Paste).gbr, MicroBugGamma - Bottom Copper (Resist).gbr, MicroBugGamma - Bottom Copper.gbr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]
2014-11-12 Standalone simulator harness added. dal.js underlying simulation complete, but only partially tested. Visiting simtest.html will call showLetter, printMessage and scrollString - output visible in bro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
2014-11-12 SIMIO code to render virtual bug and handle input added (unfinished). Currently handles display of lights only. Hitting simtest.html should now produce visible scrolly message on webpage
2014-11-16 Generate python code and interpret code cleanly
    Run in a non-blocking fashion. The interpreter now runs in steps.
    The interpreter checks to see if the micro device is ready. If
    it is, it issues a new command. If it isn't it pauses briefly.
    This allows emulation of blocking behaviour.
2014-11-16 Minor fix to the python generation - remove brackets round print
    Minor fix, but one to bring the code in line with what the back end understands.
2014-11-18 Added unminified interpreter source for reference (currently running using it too), removed blocks that aren't being interpreted correctly, set default Blockly program to something that works
2014-11-21 Program status now updates
    Now dynamically updates the area which shows down the download button, or how long it'll take until it's expected to be compiled.
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2014-11-22 Microbug Gamma production data
    [MicroBugGamma - Bottom Copper (Paste).gbr, MicroBugGamma - Bottom Copper (Resist).gbr, MicroBugGamma - Bottom Copper.gbr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]
2014-11-22 Add workarounds for char strings
    [dal.h]
2014-11-22 Change IOT device name to microbug not testhosttether
    Aside from being cosmetic, this results in the device being advertised
    as microbug._iotoy._tcp.local
2014-11-24 Change microbug/settings based on deployed host
    In particular, currently differentiate between michael's machine and pauls
    This is done by looking for a module called 'michaels_machine' and if that succeeds
    we use settings suitable for michael's dev machine, otherwise pauls.
    This will switch to match the server too shortly
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2014-11-25 The Save button now works
    This involved some tweaking to how the other buttons work.
2014-11-25 Download button now keeps updating
    This stops the button from not working when the user saves a new version.
2014-11-28 Added a/b/l/r/cursor button inputs (mouse clicks not workingAdded all Python code block generation stubs (they might even produce the right code). Added comment block. Code generates ON,OFF,PRESSED,N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
2014-12-04 Permissions change
    [MegaBug.sch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]
2014-12-10 Password reset request
    Now a nice popup to do the password request, although it currently does nothing.
    Now a nice 'has_pending_password_request' in the UserProfile, although it currently does nothing.
2014-12-10 Forking programs now works
    The big 'Make own version' button. It does things.
2014-12-11 Fixed setup.py to bundle microbug image for windows loader, added xp drivers (even though not working, Inno setup builder script references them)
2014-12-12 Fix to old code.
    [pixel_display.ino]
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2014-12-17 "LoadCode" buttons in tutorials
    Can now specify code to load in tutorials. It's ugly but it works.
2014-12-17 Can now create programs from tutorials
    Can now press the 'Save code' button in tutorials and do stuff.
2014-12-17 New blue BUG, new light positions, new eye positions, and correct button click handling
2014-12-17 Minor tweaks at Jo's request, fixed Clear Code Button, and an empty email bug
2014-12-17 Removing simulator reset button - too many steps to remove at this stage
2014-12-18 Added trash can, get_button now returns false rather than true if incorrect button specified
2014-12-19 Clear highlighted blockly blocks on reset. Ensure reset button available at all times
2014-12-19 Remove reference to dfrobot
    [sparkslabs_2.GBL, sparkslabs_2.GBO, sparkslabs_2.GBS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]
2014-12-19 Renamed import of device history to historical
    [MegaBug.sch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]
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2015-01-04 Null assignment, for loops and boolean infix expressions
    Assignment is currently assumed to be null.
    This needs to change, but is to support for loops
2015-01-05 Implement missing block tweak
    [dal.h]
2015-01-08 Remove implicit loop from generated code
    The implicit loop is an arduino-ism, but the codebug needs to not have implicit looping
2015-01-08 DAL recognises lower case versions of A,B,L,R as well as upper case
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2015-01-11 Deal with print problems when printing identifiers
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2015-01-11 Special case static string image scrolling
    In particular, anything that does show_image_offset(make_image(... ) ,0,0)
    can be short circuited as C code rather than using memory. This makes quite
    a lot of programs now work where before they'd die quickly
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2015-01-14 Swap left/right status LED's IOs
    The reason for this is because in the revised hardware by Lawrence, after re-laying out
    to accommodate the added fuse, the status LEDs got switched round. The upshot of
    this change is therefore to switch this round.
    [dal.h]
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2015-01-16 Fix print_message javascript code generation
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2015-01-22 This is a direct drop in of lawrence's power changes. This won't be ready to merge like this, but this allows tracking of when and where things can go and initial testing.
    [dal.h]
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2015-01-22 Various fixes merged from mainline
    [dal.h]
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2015-03-05 Moved clear_display back into core - needed for device reset
    [dalcore.h]
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
